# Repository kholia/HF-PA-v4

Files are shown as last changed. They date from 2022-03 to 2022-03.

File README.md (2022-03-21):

### HF-PA-v4

VU3CER's Robust `Class-D HF PA` for https://github.com/kholia/Easy-Digital-Beacons-v1
project for 40-20-17-15-10 bands.

For extra fun, use this PA with https://github.com/kholia/HF-Balcony-Antenna-System.

Jan-2022 UPDATE: https://github.com/kholia/HF-PA-v5 is up now.

This design aspires to be the standard mW-to-QRP-Gallon HF PA in the ~600 INR
(8 USD) design space. Well, it does much more than QRP now...

Design Constraints:

- PCB is to be homebrewed.

- PCB is single-sided - only one layer (side) is available for routing.

- IRF510 MOSFET needs to be on an edge to allow usage of heatsinks.

- Typical external linears (e.g. `PA150 HF Linear Amp`) need 2W minimum to
  function. So we need a minimum of 2W of RF output from our design.

- Minimal part count is strongly preferred. Low cost, and ease of availability
  are strong driving and deciding factors.

  The cost of this HF-PA-v4 system is less than one RD16HHF1 MOSFET ;)

- Reproducibility is a MUST! We focus a lot on this aspect by documenting each,
  and every detail possible.

- Repairability in the field is a MUST!

  Dhiru's finding: Repairing homebrewed PCBs is so much easier, and fun than
  reworking commercial `lead-free` PTH PCBs.

- No moving mechanical parts are allowed in the design - this rules out usage
  of (failure-prone) active cooling options like fans.

- We do NOT like the robustness of QCX, QDX, uSDX PAs. Removing heat from TO-92
  devices in a reliable way is not a trivial problem.

Note 0: All screenshots are clickable and zoomable.

Input: Few milliwatts is fine. Note: Si5351's output is around 8-10mW.

Output: With `v4.1` design, we are able to get 12W+ (total power) on the 15m
band with 30% efficiency! With a 5-pole LPF attached, we get ~10W RF output on
the 15m band. Efficiencies and output power levels are much higher on lower
bands! E.g. Power output @ 14 MHz is 14W+ with 51% efficiency - with LPF
attached!

Old results (kept for reference purposes):
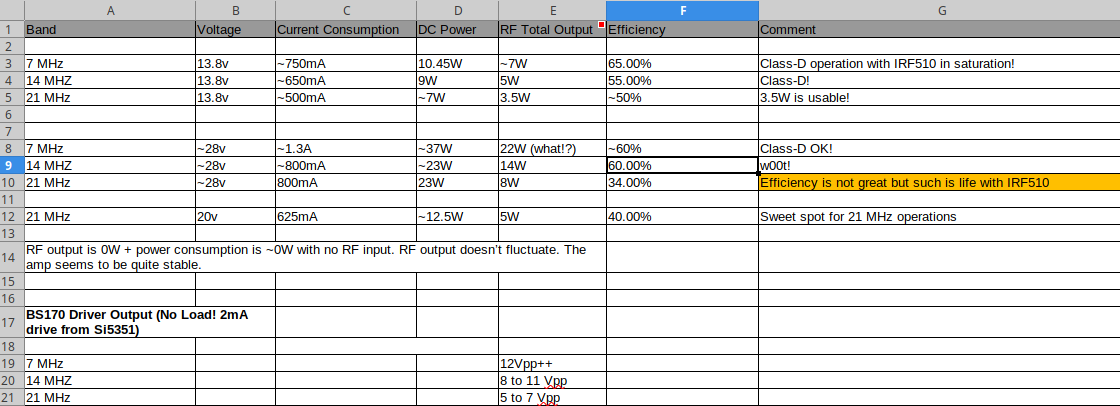
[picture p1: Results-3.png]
Results


Sample output for (14 MHz, 20v, ~725mA IN, 15W DC IN, 5.2W RF OUTPUT, With LPF
attached):

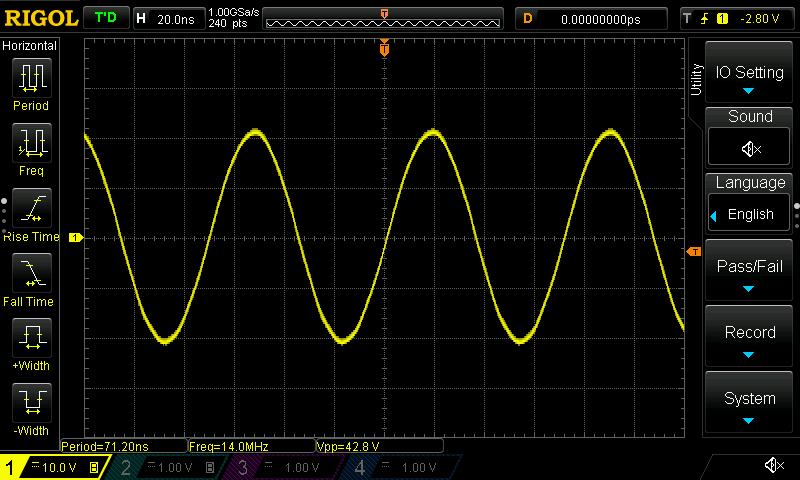
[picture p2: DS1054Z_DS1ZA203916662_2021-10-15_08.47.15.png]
Scope Shot


Note 1: The output power is software controllable (via `PWM grounding`) for
flexibility.

Note 2: The idea behind making these (and my other) design notes publicly
available is to deliver REPRODUCIBLE, flexible, home-brewable, standardized,
reasonable, and cost-effective solutions for some common problems. I include
many references, simulations, and notes in my projects to enable you to do your
own (better) designs - do share them ;)

Robustness Notes:

- Ensure that the IRF510 is fastened securely to the heat sink.

  Use lock washers, and thermal epoxy adhesive to ensure good mechanical
  contact.

- We recommend operating at 24v instead of >= 29v.

**Final recommendations from 05-November-2021 (for v4.3)**:

- Using 7805 is recommended instead of 7809 / 7912. Less is more ;)

- Enable `SI5351_DRIVE_8MA` option in code.

- Output results @ 24v:

  - 28.075 MHz (10m): 4W RF OUT (~14.5W DC IN)

  - 21.075 MHz (15m): 5W RF OUT (~13W DC IN)

  - 14.075 MHz (20m): 7W RF OUT (~13W DC IN)

For more power, use 7809 instead of 7805, and remember to take (much) more
care!

Please see the older https://github.com/kholia/HF-PA-v2 project for the
power-supply (over-current protected), and LPF designs.

Schematic:

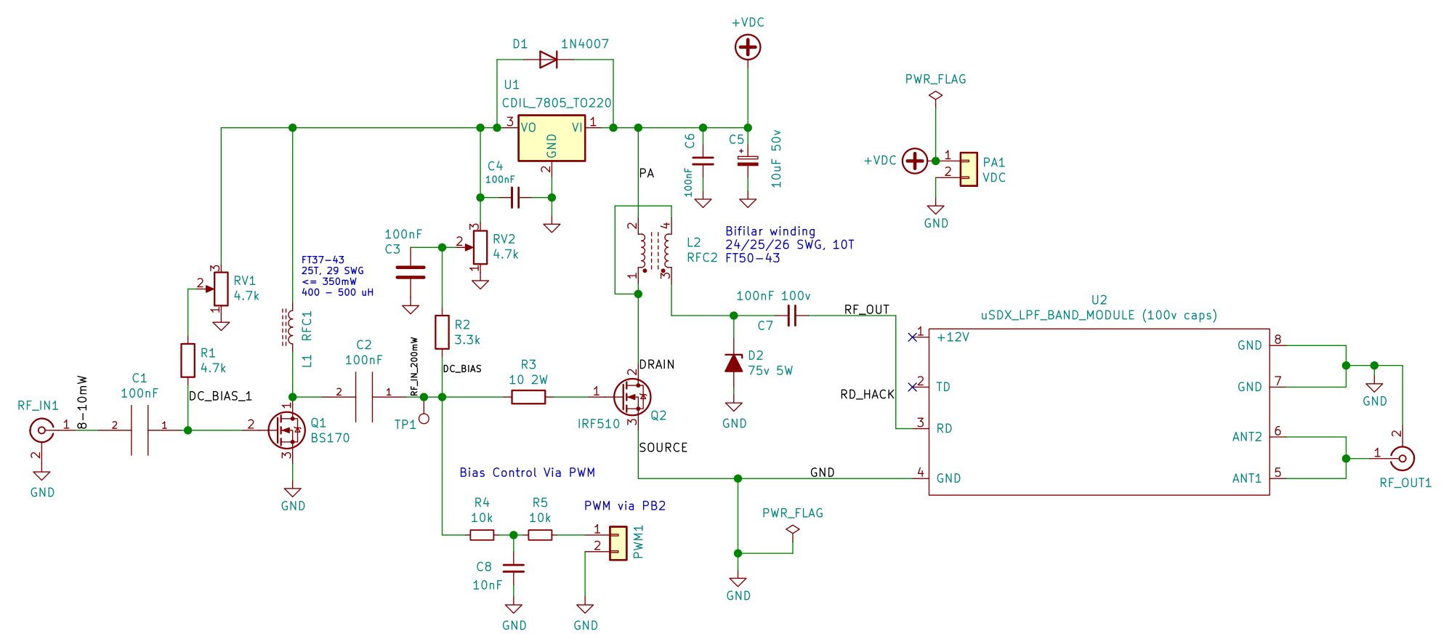
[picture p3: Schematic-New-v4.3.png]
Schematic


PCB rendering (v4.1):

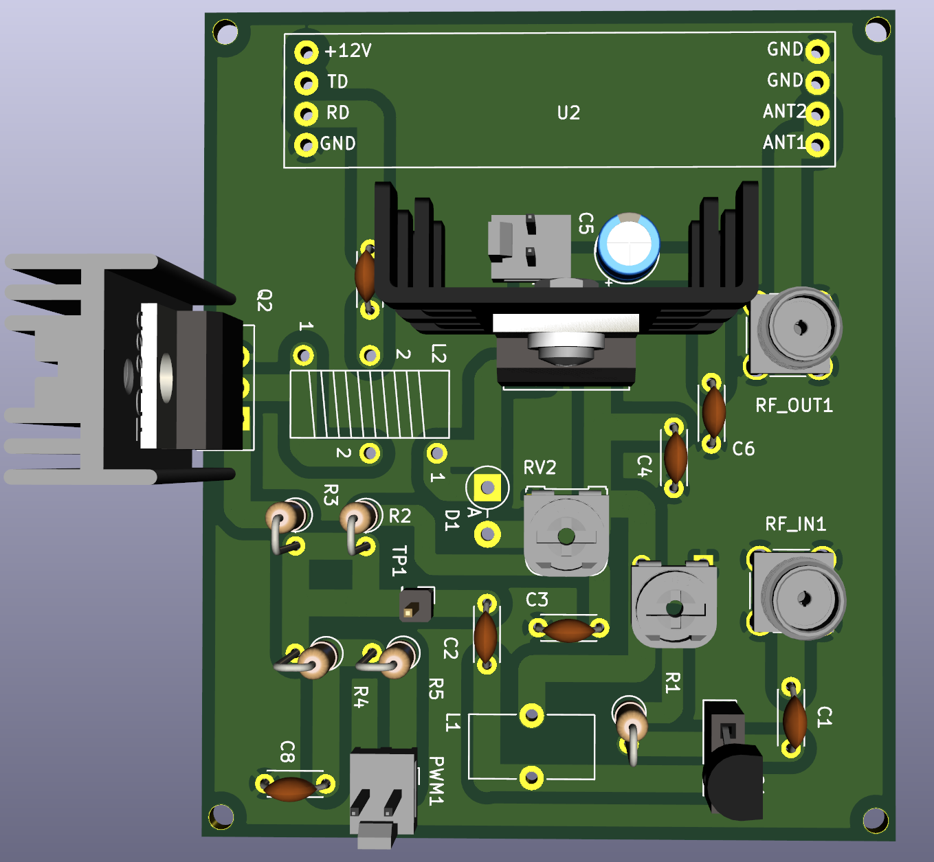
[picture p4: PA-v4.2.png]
HF-PA-v4


Note 3: The HF PA is connected to a 20m dipole over 55 meters of HLF-200 coax.

Note 4: The PCB is done using KiCad - a free, and open EDA software.

Note 5: This PA can be homebrewed from scratch in around 4 to 6 hours (one
afternoon, and an evening).

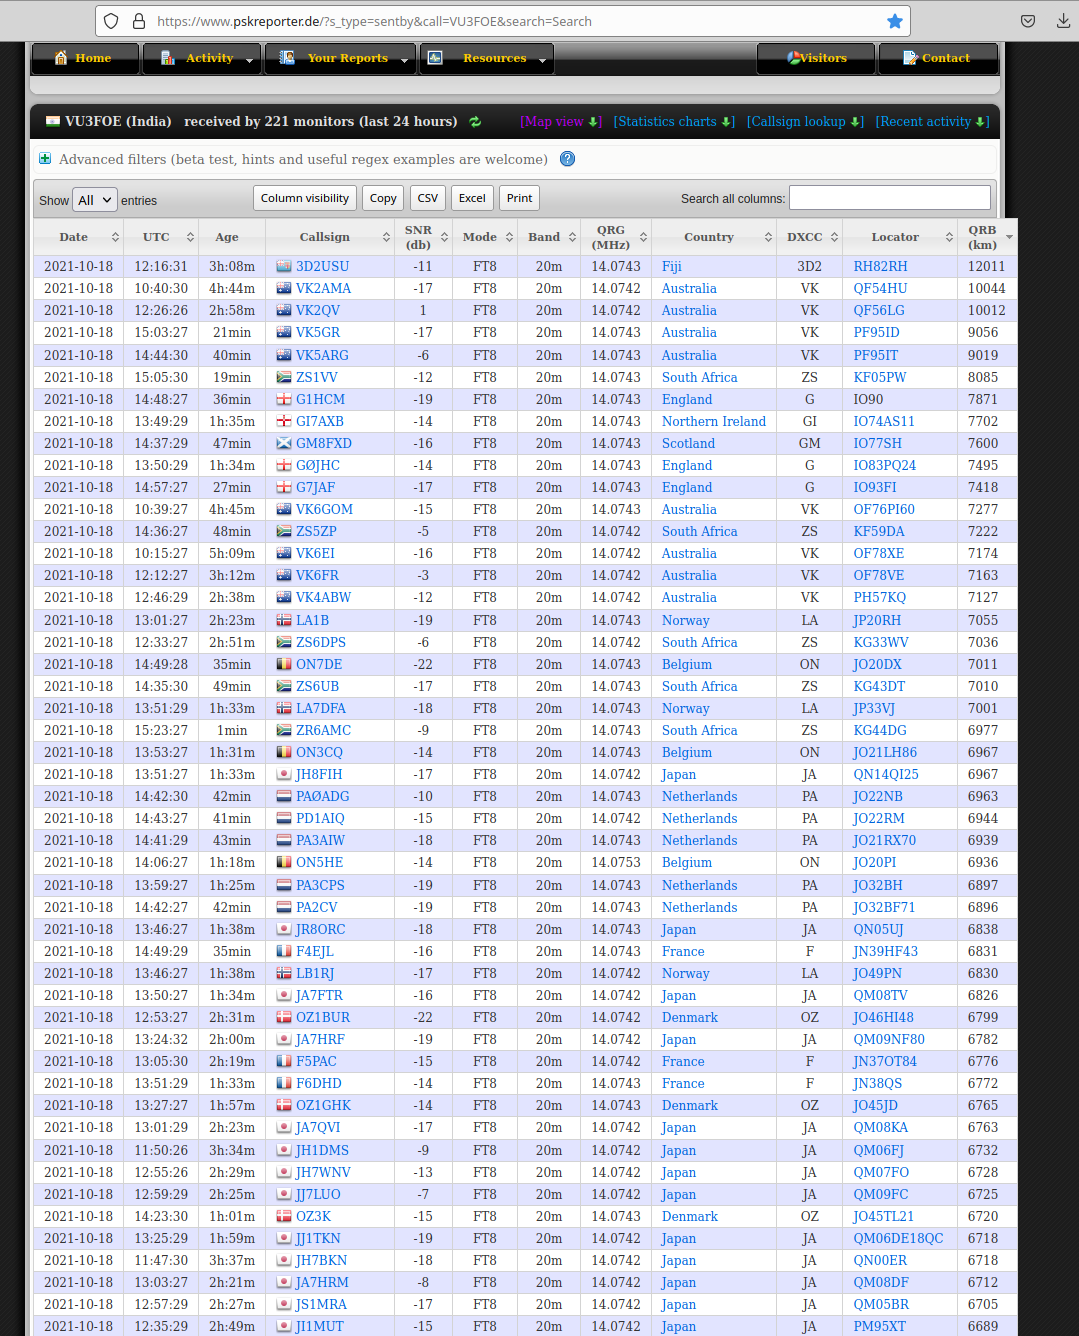
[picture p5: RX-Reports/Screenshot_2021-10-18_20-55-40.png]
RX Report 1

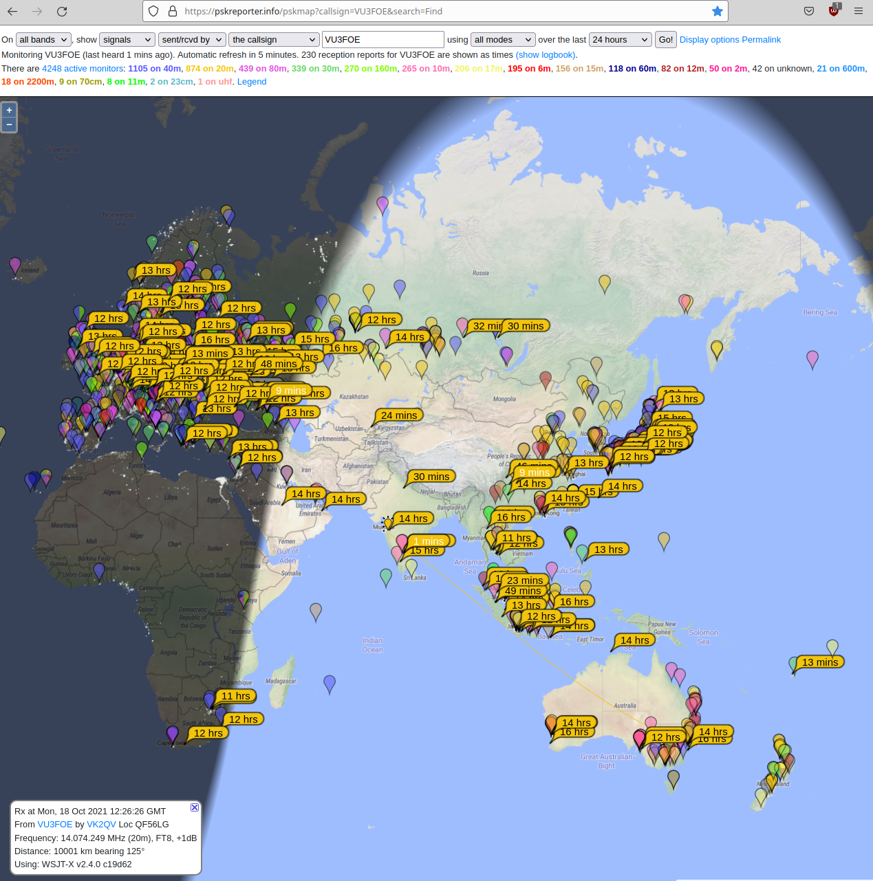
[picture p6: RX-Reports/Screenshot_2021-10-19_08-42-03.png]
RX Report 2

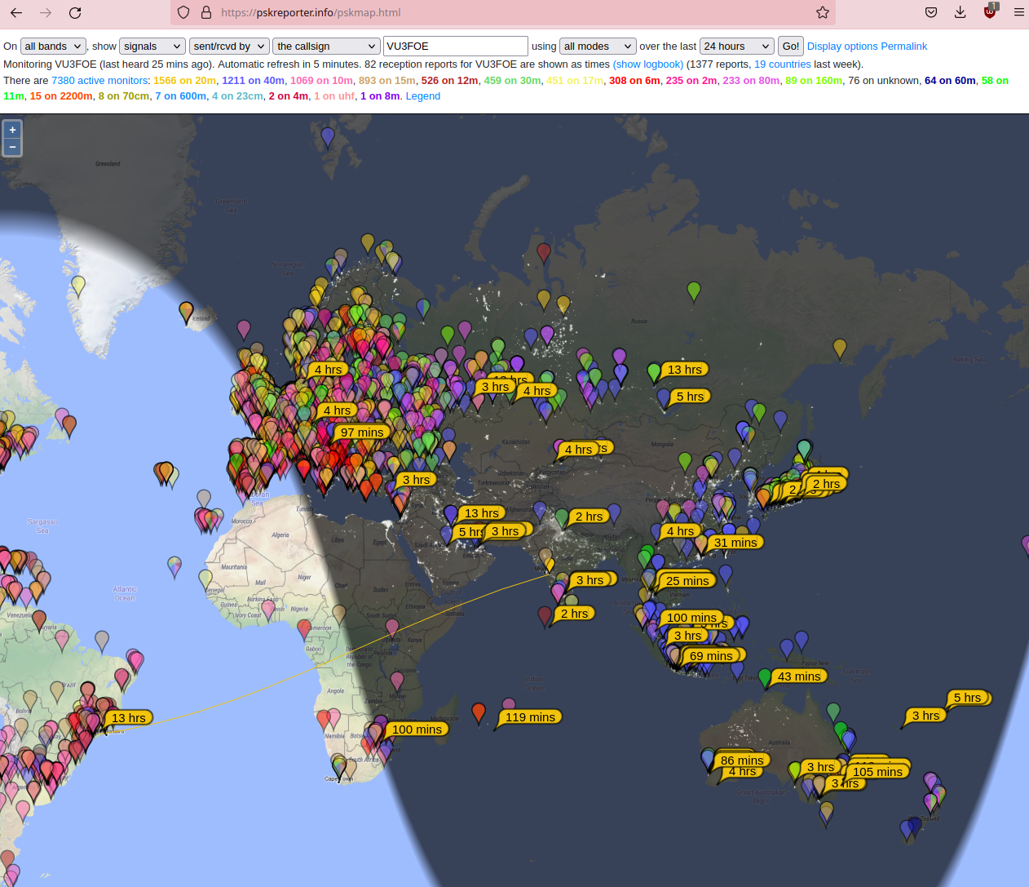
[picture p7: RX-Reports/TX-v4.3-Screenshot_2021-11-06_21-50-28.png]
RX Report 3


#### Notes

[From QRP Labs] Si5351A outputs a 3.3v square wave. The power output of Si5351A
is around 8-10mW (10 dBm). The BS170 based driver circuit amplifies this to
~200mW (23 dBm) for a gain of around 13 dB. The IRF510 finals provide a gain of
around 14dB and produce around 5W of RF power.

#### PA tuning process

- Remove the BS170 and IRF510 MOSFETS from their sockets.

- Set DC gate bias for BS170 to 0v. Now increase the bias (via trimpot) until
  the current consumption increases slightly (QRP Labs' process).

  You can also start by setting the gate bias to 2v directly ;)

- For IRF510, set gate bias to 3v. This ensures that IRF510 isn't turned ON -
  double-check this by monitoring the power consumption.

- Connect the MOSFET back, and measure RF output. Happy with the output power? -
  If yes, you are done else follow the next steps.

- Remove the MOSFET, increase the gate bias voltage in very small increments
  (0.1v types).

- Connect the MOSFET back, and measure power consumption without any RF input.
  Ensure that MOSFET remains OFF without any RF input.

- Apply RF input, and measure RF output.

- Repeat these steps as needed.

The [QRP Labs' procedure for bias adjustment](https://www.qrp-labs.com/images/pa/pa_simple_assembly_A4.pdf) and [this document](https://www.qrp-labs.com/images/ultimate3s/assembly_u3s.pdf) seem to have a better description of this process.

#### PA BOM

- 1 x IRF510 (Genuine Vishay parts are tried-and-tested) - 35 to 50 INR

  - The `SEC` (`SEC Electronics Inc`) branded IRF510(s) also work great!

  - The `SEC IRF510` can perform even better than Vishay's version. This
    particular result will vary between different product batches.

  - IRF510 with `International Rectifier` branding are most likely fake or "new
    old stock" if you are very lucky!

    Note: IR and Infineon have stopped manufacturing IRF510 MOSFETs.

  - AliExpress IRF510(s) are likely to be fake

  - The IR IRF510 gave ~3W versus 5.2W+ from SEC IRF510 versus ~5W from
    Vishay's IRF510!

    Note: The gate threshold voltage can vary even between two samples picked
    from the same manufacturer!

  - The Cgs ("gate capacitance") of a fake IRF510 is typically more than 1000pF
    on a LCR-T4 meter. This value is around ~400pF for genuine IRF510 parts on
    a LCR-T4 meter.

  - Ensure proper sourcing (trusted supply chain, etc) to get genuine parts

- BS170 MOSFET - 9 to 15 INR

- 2 x 4.7k Preset (Potentiometer) RM-065 - 12 INR

  - It is easier to get 5k (502) trimpots

- 1 x 3.3k 0.25W MFR - 2 INR

- 1 x 4.7k 0.25W MFR - 2 INR

- 1 x 10 Ohm Resistor 0.25W or 0.5W MFR - 2 INR (MOSFET gate resistor)

- [Optional] 2 x 10k Ohm - 0.25W Metal Film Resistor - 5 INR

- A very large heat sink - 50 to 175 INR - larger heatsink is better!

- 1 x 7805 (TO-220 package from CDIL) Voltage Regulator - 30 INR

  - The ST's 7805 is widely faked - let's avoid it or let's source it properly

- 1 x 1N4001 (or 1N4007) diode for 7805 protection - 2 INR

- 2 x SMA connectors (Vertical PCB mount) - 75 INR

- 1 x 10uF 50v Electrolytic Capacitor - 5 INR

- 8 x 100nF (104) 50v MLCC - 20 INR

- 1 x FT37-43 (Black Toroid, Fair-Rite 5943000201) - less than 25 INR (handles <= 350mW only)

- 1 x FT50-43 (Larger Black Toroid, Fair-Rite 5943000301) - less than 32 INR

- Misc: Relimate Connectors, Copper Clad PCB (Glass Epoxy), Various Consumables
  (~100 INR), SMA cables for testing, RF adapter (SMA Male to SO-239), M3 nuts
  and screws, TO-220 insulator kit

- Tools: LCR-T4 Meter (for measuring things), RF Power Meter

- Optional power supply: LM50-20B24 Mornsun SMPS - 24V 2.2A - 52.8W AC/DC SMPS - 700 INR

- Optional PPTC fuse

- PA Total Cost: Less than 600 INR

#### Power Supply + LPF BOM

See the following projects:

- https://github.com/kholia/HF-PA-v2
- https://github.com/kholia/HF-PA-v3
- 2 x 100 pF (50/100v)
- 1 x 180 pF (50/100v)
- 2 x T50-6 (Yellow Iron Dust code) toroids
- 25 SWG Winding Wire

Note: For LPF, use C0G 100v rated caps!

#### BOM + Equipment Sources

- https://www.semikart.com/ (IRF510, BS170, 100v NP0 LPF caps - Kemet and others)

  - 100v NP0 LPF caps from `Multicomp Pro` brand seem pretty cost-effective

  - 1N5374B 75V 5W Zener Diode (optional - for SWR protection)

- https://www.electronicscomp.com/

  - IRF510, BS170, regular caps, ST voltage regulators

  - Female berg strip (2.54mm pitch)

- https://www.electroncomponents.com/ (transistors, connectors, consumables, misc)

  - https://www.electroncomponents.com/LM7805-5V-Positive-Regulator

  - https://www.electroncomponents.com/BS170-N-channel-Switching-FET

  - https://www.electroncomponents.com/1N4001

  - https://www.electroncomponents.com/mica-insulator-to-220-set-kit

- https://www.sunrom.com/ (regular ceramic caps, SMA connectors)

- https://projectpoint.in/

  - Transistors, regular caps, voltage regulators, pots / trimmers, MFR resistors, misc

  - 2-Pin High Quality Relimate Connectors (all those 2-pin headers are actually Relimate Connectors)

  - Copper Magnetic Winding Wire - 29 SWG and 25 SWG

  - CDIL 7805

  - 3-Pin Relimate Cable Female to Female (High Quality 2500mA) - 'TO-220 socket'

  - 2-Pin Relimate Cable Female (High Quality 2500mA) - for power

  - 2-Pin Relimate Male Header

- Semikart, eBay (`gr_makis`) - Toroids

- https://www.onlinetps.com/shop/ ('IR branded' IRF510 - not recommended!)

- https://www.ktron.in/ (SMA connectors)

- [LCR-T4 LCR Meter](https://www.techtonics.in/lcr-t4-12864-lcd-graphical-transistor-tester-resistance-capacitance-esr-scr-meter)

- https://robu.in/ (voltage boost module)

- See https://github.com/kholia/HF-PA-v2 and https://github.com/kholia/HF-PA-v3 sources too

Note for international buyers: The BOM can be carefully sourced via Mouser and DigiKey.

#### O(Current consumption)

The ESP8266 usually draws a peak current of about 250mA after it wakes up and
then more or less constantly draws around 70mA before it goes back to sleep.

DS3231 -> 5mA

Si5351 -> ~50 to 100mA

PA -> Less than 1 A (rms)

Upper bound -> 1.4A maximum.

#### Tips

MOSFETs are sensitive with regards to ESD and high soldering temperatures. Use
best practices when dealing with MOSFETs and perhaps always ;)

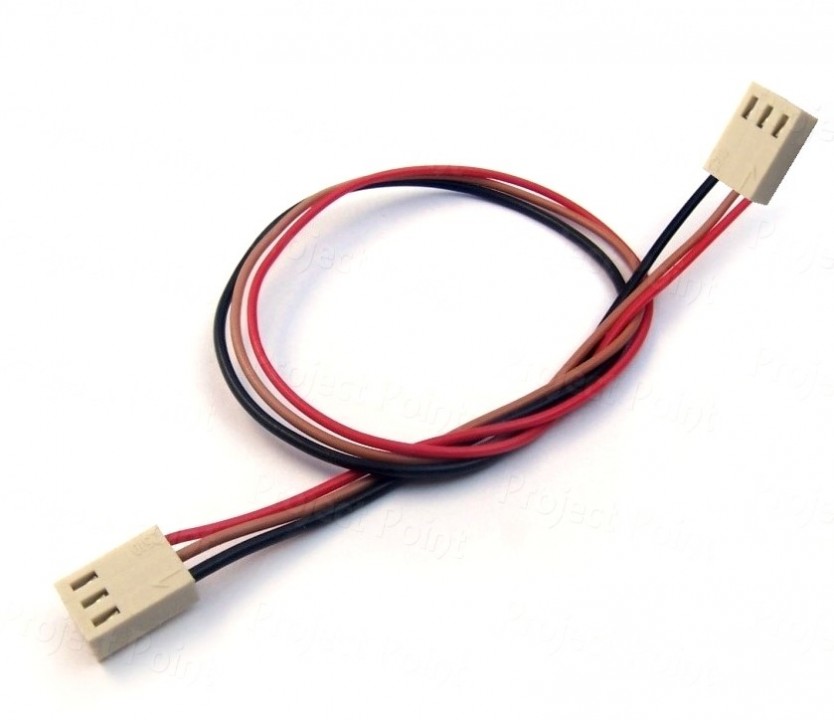
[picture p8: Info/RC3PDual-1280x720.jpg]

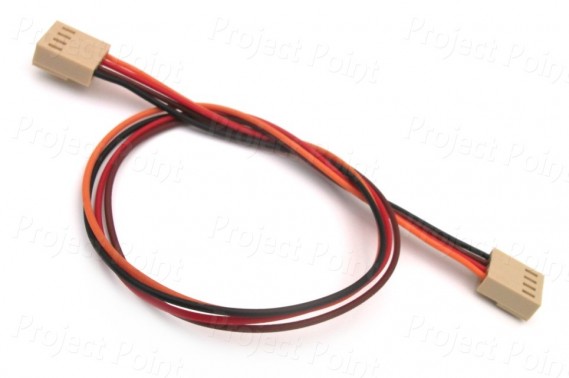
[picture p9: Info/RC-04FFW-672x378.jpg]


By using these `TO-220 Sockets`, we can easily support any MOSFET pinout. This
technique allows usage of `off-pcb` heat sinks with a lot of flexibility. It
also avoids common ESD + MOSFET problems as well. The gate bias can be easily
checked by safely removing the MOSFET from the TO-220 socket. Also, this socket
idea allows us to safely eliminate the LDO from the design.

A burnt 78(L)05 regulator can easily eat up 4-5W of power by itself. If there
is no RF output but power is being consumed then check your linear regulator.

#### Future ideas

- Use a `PPTC fuse` in the PA voltage line (oscillations can be a real problem,
  and can be nasty) - Sandeep Lohia (VU3SXT).

- Add a `Type K Thermocouple` based temperature monitoring to ensure safety.

- Alternatively, use ACS712 to monitor the current consumption to ensure
  safety.

#### References

See [References.md](./References.md).

#### Credits

This design uses ideas, and support from Hans Summers (G0UPL, QRP Labs), VU3SXT
(Sandeep Lohia), VU2ASH, Mr. Bhatnagar (VU2SPF), AC7LX, and PY2OHH.

Also see https://github.com/kholia/HF-PA-v3#credits and https://github.com/kholia/HF-PA-v2#credits.

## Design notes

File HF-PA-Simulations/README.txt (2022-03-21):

The `DS1054Z*.png` files are scopeshots of the BS170 driver stage.

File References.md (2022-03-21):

#### References

- http://shop.qrp-labs.com/pa
- http://shop.qrp-labs.com/kits/U3S
- https://github.com/kholia/HF-PA-v3/
- https://github.com/kholia/HF-PA-v2/
- https://github.com/agustinmartino/wsjt_transceiver
- https://www.qrp-labs.com/ultimate3/u3info/u3sbifilar.html
- https://www.qsl.net/py2ohh/trx/peanuts/peanuts.html
- https://www.qsl.net/py2ohh/trx/lpf100w/lpf100w.html (LPF filters)
- http://hyse.org/pdf/www.aoc.nrao.edu/~pharden/hobby/_ClassDEF1.pdf
- http://hyse.org/pdf/www.aoc.nrao.edu/~pharden/hobby/_ClassDEF2.pdf
- http://thestone.zone/radio/2020/12/13/multi-watt-amplifier.html
- http://thestone.zone/radio/2020/12/18/gate-driver-amplifier.html
- http://thestone.zone/radio/2021/01/14/capacitors.html
- http://thestone.zone/radio/2021/01/16/minor-enhancements.html
- https://www.g0kla.com/scpa/SimpleCheapPA.php
- https://www.linkedin.com/pulse/rf-pcb-design-rules-manufacturing-process-lisa-chu/
- http://thestone.zone/radio/2021/06/04/attenuator.html
- http://thestone.zone/radio/2021/06/05/power-amplifier.html
- https://on7dq.blogspot.com/2020/12/qcx-mini-measurements.html
- https://www.random-science-tools.com/electronics/dBm-Watts-volts.htm
- https://www.mitsubishielectric.com/semiconductors/php/oSearch.php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
- http://www.carnut.info/WSPR_Tx/WSPR_Tx.htm
- https://sites.google.com/view/andy-g0ftd/iron-fist-transmitter
- https://www.dj0abr.de/english/technik/dds/pa.htm
- https://www.qsl.net/py2ohh/
- https://hf5l.pl/en/transceiver-usdx-with-arduino-nano/#
- http://www.m0rzf.co.uk/PA_Old/index.html
- https://vk3hn.wordpress.com/2019/05/01/summit-prowler-6-a-pocket-sized-ssb-cw-transceiver-for-80-40-30-and-20m/
- http://am-transmitter.blogspot.com/2014/07/protect-your-mosfet-final-stage.html
- https://electronics.stackexchange.com/questions/11583/grounding-a-soldering-iron
- http://hfsignals.blogspot.com/p/25-watt-linear-for-40-and-20.html
- http://www.norcalqrp.org/nb6mminiboots.htm
- https://github.com/RoGeorge/DS1054Z_screen_capture

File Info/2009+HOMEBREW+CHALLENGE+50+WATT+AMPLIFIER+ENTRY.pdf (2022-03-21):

ARRL 2009 HOMEBREW CHALLENGE 50-WATT AMPLIFIER ENTRY: “The 89-cent Special”
Donald W. Huff, W6JL

This amplifier was designed and built by the author as an entry in the ARRL’s 2009 Homebrew Challenge contest. The requirements of the amplifier are that it be a 40 meter band 50 watt output amplifier intended for use with a QRP transmitter as driver (less than 5W), constructed at a total material cost of not over $125.00, and meet applicable FCC requirements for amateur radio products, tested in accordance with published ARRL Laboratory test procedures. Other requirements also apply. Hopefully this amplifier will be found to meet or exceed all requirements.

This builder’s priorities for this amplifier are as follows, in order of importance:
1. True “homebrew” (no pre-made PC boards, kits, etc).
2. Lowest possible cost of materials. (HB labor is recreational, and therefore FREE, so I always trade off materials for labor). Must be a “cost-effective” design.
3. More than adequate performance.
4. Practicality in construction and in use, with no frills.
5. Usable on other bands.
6. T/R switching fast enough for QSK at usual speeds.
7. “Cosmetics” always seem to be last on my list. Beauty is in the eye of the builder, and for this builder, ugly-style is beautiful!

PHYSICAL CONSTRUCTION (FANCY TERM IS MECHANICAL DESIGN):

Bare copper-clad material, and “ugly construction” methods minimize cost and provide excellent RF grounding of circuitry. This amplifier is a nearly ideal candidate for ugly construction. Only a single side of the copper clad material is used for mounting components, thus either double-sided or single-sided copper clad material (less expensive) may be used. The copper-clad material is drilled for three 4-40 mounting screws threaded into matching drilled and tapped holes in the heat sink. Also, the heat sink is drilled and tapped for two 4-40 threaded holes for the mosfet mounting screws. Last, the copper-clad is drilled with four 4-40 screw clearance holes in the corners, used for four 4-40 screws and threaded spacers to act as supports above the table top when in use. Two rectangular cutouts about 1/8 inch larger all around than the TO-220 device packages, are centered on the base material’s length and width, and cut out using a drill and a hand nibbler tool and/or a file. An inexpensive but very effective personal computer Pentium processor heat sink/fan is used. This heat sink/fan maximizes cooling effectiveness required by the relatively poor thermal conductivity of the TO-220AB package of the chosen active devices, the International Rectifier IRFZ24N power mosfet. The key to low cost is the use of these very inexpensive devices, which are intended for switch-mode power supplies and other switching applications, not RF service. As hams have historically done, I am using whatever is readily and inexpensively available that will meet my needs. A reasonably stocked junkbox can keep the out-of-pocket cost for this amplifier under $10.

CIRCUIT DETAILS (FANCY TERM IS ELECTRICAL DESIGN):

There is really no original design work here. But for any builder it is important to understand what the components do, and how they were chosen. I see all too many homebrew articles which just present a schematic and skimpy circuit description and do not explain what each part does, how its value is determined, and perhaps how critical its value may be and why.

The circuit used in this amplifier is a conventional and often-used push-pull broadband transformer-coupled architecture. No RF negative feedback is used, for simplicity and to provide high gain while still meeting the minimum IMD requirement of -28 dBc (at least 22dB below 12.5W tones). No complex mechanical assemblies are required and most components are mounted by their leads as usual in Ugly Style construction. I used inexpensive solder-down RCA type connectors for input, output, and P.T.T./Keying, and direct wire connections for a 13.8VDC supply.
Operation is class AB for linear applications (SSB, PSK, etc); or the amplifier is easily re-biased for class B for CW use if desired. A bias control potentiometer for each mosfet allows user variation of operating point to enable optimization of operation for a particular mode or for optimizing performance. Limited temperature compensation of bias point is provided by gluing pairs of 1N4148 (costing as low as 2 cents each from at least one supplier) diodes to the plastic cases of the mosfet devices and utilizing their known forward voltage vs temperature characteristic (about -2mV/deg C) to reduce forward bias as mosfet junction temperature increases. The diodes run at a constant current. This is accomplished by making simple current sources using a PNP transistor at Q1 and Q2 with associated biasing resistors. Why use a current source? Because, if driven from a voltage (ie, low resistance) source, the temperature variation of diode forward voltage will be reduced by the divider formed between the diodes’ changing forward voltage and the other resistors in the circuit. With a current source, the current through the diodes is maintained over a wide range of voltages and variation in diode forward voltage, thus preserving the variation in voltage due to the diodes’ changing temperature. (See LTSpice simulation circuit for the current sources later in this article). The absolute value of the bias voltage depends on the magnitude of the current from the current source, and the setting of the bias pot. How does the current source work? Zener diode D1 maintains a fixed voltage of about 4.8V across the base-emitter of Q1 and Q2, plus emitter resistor of Q1 and Q2 (the zener has a tolerance of +/- 5%, so its voltage can vary from 4.75 to 5.25 volts depending on the accuracy of any given diode). The current flowing in the emitter and collector circuits of Q1 and Q2 is determined by this voltage, minus 0.7 volts drop emitter to base, divided by the emitter resistance. Thus, in the prototype circuit the current is (4.8 – 0.7)/1.2K or 3.3 mA. This value is not critical, and will vary from unit to unit depending on zener tolerance and resistors R1 and R2 tolerances. Potentiometers R4 and R5 adjust gate bias on the mosfets over a range from about 2.9 to 4.5V, which for most IRFZ24N devices will cover operation from Class B (no quiescent drain current), up to class AB (up to a few hundred mA of drain current for each mosfet). The author found it unnecessary to make biasing individually adjustable for each mosfet, after trying several pairs of IRF24ZN mosfets in the circuit, but individual control is included here for accommodating those cases where the gate threshold voltage matching is not so close between the two mosfets. .
The gates of the two mosfets are heavily loaded at RF frequencies by the pairs of 20 ohm ½ watt resistors, connected from gate to RF ground via C2 and C5. These values were chosen somewhat arbitrarily (yes, they were available in the junkbox), and reduce the gain in addition to partially swamping out the high input capacitance of the mosfets. The lower the values of these resistors,the higher the required input drive power (and the lower the power gain) of the amplifier. They also act to help stabilize the input impedance, so that the driver sees approximately a 50 ohm load. Transformer T1 steps the 20 ohms of push-pull gate impedance up to about 50 ohms, thus requiring at 50/20 or 2.5:1 impedance step-up from gates to input. Recall that for any transformer the impedance ratio is equal to the turns ratio squared, ie, Z1/Z2 = (N1/N2)^2. This requires a turns ratio in this case of the square root of 2.5, which is 1.58. The inductance of the secondary or primary must be at least 4 times the working impedance of the circuit. For the secondary, this impedance is 20 ohms. So we need an inductive reactance of at least 4 times 20 or 80 ohms, at the lowest frequency we plan to use, say 1.8 MHz. 80 ohms of inductive reactance at 1.8 MHz works out to an inductance of 7.1 uH (easily determined from a reactance chart; also see calculation method below for T2’s primary). Using an Amidon FT-37-43 (readily available at low cost, but also was in my junk box), we find the AL value to be 420 mH/1000 turns. Since turns = 1000 * square root of (inductance in mH/AL), we get 4 turns. For a little margin I chose 5 turns, making the primary 1.58 x 5 or 8 turns, rounded to the nearest turn.

The output transformer T2 is determined similarly, but we need to know what drain-to-drain load resistance we need. This is easily determined from a consideration of the supply voltage and output power that the mosfets can sustain. For a push-pull Class AB or B amplifier, the drain to drain impedance can be calculated from the formula Rdd = 2*(Vsupply)^2/Pout (see Note 1, also see sidebar for derivation). In this case we calculate Rdd to be [2*(13.8)^2]/50 or 7.6 ohms. The voltage swing on the mosfet drains will be about twice the supply voltage, or about 28V. (The rated 55 V maximum drain-source voltage of the IRFZ24N’s thus provides adequate margin, as long as the load is connected to the amplifier. Some mismatch is tolerable of course, but it is good practice to assure that the amplifier is looking into a relatively low impedance at all times). Since transformer T2 has a single-turn primary, the available ratios are integer ratios only. The closest integer ratio is 1:3 which provides a 1:9 impedance step-up, (or 9:1 impedance step-down the other way, from output to input). With a 50 ohm load resistance, this works out to 50/9 or 5.6 ohms at the input, which is close enough to 7.6 ohms for our purpose. Why is a single turn chosen for T4’s primary? We need a primary inductive reactance greater than 4 times the drain-to drain impedance so as not to significantly load the circuit with the transformer’s primary inductance, at the lowest frequency of operation. This means no less than 5.6 ohms x 4 or 22 ohms of inductive reactance, at 1.8 MHz. Since XL =2*PI*F*L (or use a reactance chart), we need a primary inductance of at least 22/(2*PI*1.8MHz) or 1.9uH. Using the Amidon BN-43-3312 ferrite two-hole balun core (also available for about $2 but also available salvaged from another project in my junk box), and looking up the AL value in the Amidon data sheet, we find an AL value of 5400 mH/1000 turns. Since turns = 1000 * square root (Lmh/AL), plugging in the inductance of 1.9 uH, which is .0019 mH, gives us 0.6 turns. The closest we can get is a single turn, so that should do, even for 160M.
The method of building T4 is nothing new, using the braid from a short piece of RG-58 coax, and looping the braid through to make the single turn primary (a single turn in a binocular core passes through both holes). The braid does not have to be insulated, because the ferrite core is a non-conductor of electricity for all practical purposes. The braid is kept open and a hole is enlarged through it at the center of the output side to enable threading three turns of insulated wire through the inside of the braid, around the input holes (staying always inside the braid), and with the final turn exiting the braid through the hole. This takes longer to describe than becomes immediately apparent when seeing a sketch, which is shown below. Another way is to use the common method of two brass tubes that fit the core holes to make the primary, shorting the ends at the output side, and connecting the mosfet drains to the two tubes at the input side. Then the secondary is threaded through the brass tubes. Either way is equivalent, but the braid method requires no brass tubing to be cut and a short to be fabricated from PC stock with holes drilled to short the output end. As you can see, there is a simple rationale for everything, as it should be: Keep It Simple.
For those wondering about why there is no RF feedback, as is often used, the use of small value source resistors and shunt RF feedback was investigated. Both can make the amplifier more linear, reducing IMD further, but drive power increases and peak output power becomes insufficient to meet the 50W CW requirement, at least while limited to a 13.8 VDC supply voltage. There is just not enough “head room” to avoid peak rounding (amplifier compression) with a 13.8VDC supply. The amplifier simply saturates at a lower power level when using feedback, particularly source resistive feedback. (A higher supply voltage may enable use of feedback while still obtaining sufficient peak power output). The peak RF output limitation with a 13.8V supply is probably due to the ON-state resistance of the mosfets. At peak RF drain currents of say 10 amperes or more, the voltage drop across the Rdson resistance (rated at .07 ohms at 25 deg C) of the mosfet can become a significant portion of the 13.8V supply voltage, subtracting from it and resulting in insufficient remaining drain voltage swing to provide the desired 50W of peak output. Mosfets designed for RF power amplifier service tend to have higher ON resistances (and much lower capacitances) and they almost always require a higher supply voltage for proper operation. This is why 14V powered RF power amplifiers at near the 100W level tend to use bipolar transistors instead of mosfets.
Push-pull operation tends to cancel even harmonics if well balanced, but odd harmonics are still significant. (This is a price we pay for untuned, broad-band amplifier circuits like this). The usual 40-meter “half wave” low-pass filter is included here for further harmonic suppression; other bands will require different low-pass filter component values. These are easily determined and available components (the reactance of each L and C is chosen to be equal in to the load impedance of 50 ohms), see table below for list of components for filters on other bands. If you have a selective antenna system and/or antenna tuner, if you calculate how much harmonic suppression you have with the total radiating system, you may find that on some bands you will have sufficient harmonic filtering due to an appropriate antenna tuner/antenna combination’s selectivity, to eliminate or greatly simplify the low pass filtering of harmonics. This is an often-overlooked capability. I have a two-element yagi on 40 meters for example, which is a very high Q (narrow band) radiator, offering significant attenuation outside of the band and poor radiating (and receiving) efficiency at harmonic frequencies. Running an antenna simulation using Eznec or other programs, can aid in determining the selectivity of your antenna system. We are only interested in total transmitted harmonic suppression, so you can take the whole transmitter/tuner/antenna system selectivity into account.
Simple relay T/R switching is provided. On “make” (key-down), the small Omron relays chosen close after a less than 7 millisecond (mS) delay after key-down (“make”), and, with a 22uF capacitor across the coils to slow the current decay in the coils, open again after 20 mS of delay following key-up (“break”). This enables QSK at up to about 30 WPM with no hot switching in the amplifier if the exciter does not have RF build-up before about 7 mS from key-down, and if the RF output does not last more than 20 mS after key-up. This can usually be arranged with the exciter (especially if the exciter is also homebrew!). Use of a lower-rated coil voltage relay, operating at 13.8VDC, can speed up the “make” time in some relays. This is no problem if key-down time is limited. (Do not be afraid to “mis-use” a component in a known and intentional way; we are not building an amplifier for mass production here; we just need reliable operation for this one to work. Again, think of simple ways to solve a problem and/or use an existing junk-box part to advantage). The higher voltage (and hence, coil current) on “make” can speed up the armature movement to the closed condition. The T/R relay switching was also modeled using LTSpice, after measuring the relay resistance and inductance. It turns out the inductance is insignificant and the relay opening (“break”) time stretch is determined by the resistance and the coil drop-out current, in conjunction with the shunt capacitor value. (The capacitor value is easily determined experimentally with an oscilloscope without any coil measurements or simulating of the circuit, but I have become attached to using LTSpice and find any excuse to model something :o)). With the values shown, the maximum QSK CW speed is limited to about 30 WPM. QRQ ops will need shorter switching times. (This can also be done very inexpensively with a homebrew PIN diode T/R switch, eliminating all relays, which the author built for his QRO QSK rig, using inexpensive 5-cent 1N4007 rectifier diodes, but that is outside the scope of this article).
Operation with key-down for over 20 minutes at a time has been demonstrated at the 50W continuous output power level on CW or 2-tone output at 12.5W per tone on 40 meters, at stabilized heat sink temperatures (see thermal test results graph below). The inexpensive CPU cooler does an excellent job of dissipating the heat from the two TO-220 devices, but they must be mounted with silicon grease and/or good quality insulators. Mica is ideal. The inherently rather high (about 1.8 deg C per watt) thermal resistance from junction to case of the TO-220AB package also limits the maximum safe power dissipation even with a very good heat sink

BAND | INDUCTANCE | CONSTRUCTION | C9, C12 | C10+C11
160M | 4.2uH | 18T ON T106-2 | 1500pF | 3000 pF
80M | 2.5uH | 14T on T106-2 | 820pF | 1500pF
30M | 1.2uH | 15T on T-50-2 | 330pF | 560pF
20-17M | 0.58uH | 12T on T-50-6 | 180pF | 330pF
15-10M | 0.33Uh | 9T on T-50-6 | 100pF | 180pF
Table 1. Output low-pass filter values for other HF bands. Wire sizes are not given, as they are non-critical. It is best to use the largest wire size (or equivalent-area multifilar smaller gauge wires) for which the required number of turns will fit as a single layer on the toroidal core. The two largest cores, used on 80 and 160 meters, are overkill size-wise; they were available, naturally, in the author’s junk box so were used. T-80 cores are a better fit, and turns will more fully fill the core. As with winding any toroidal inductors, the required turns count is calculated according to the published AL values for the cores chosen, and the total turns count is how many turns pass through the central hole. The first capacitor, C9, can be adjusted (ie, “tweaked”) in value somewhat, with minimal effect on low pass performance, but it can improve the higher-order IMD products by reflecting a varying reactive load back into the primary of T2, helping to cancel a little of the higher-order IMD energy. This is why C9 is shown as 680pF (instead of the calculated 470pF) on the schematic. However the amplifier should still meet the minimum -28dBc IMD requirement even with the calculated value.

TURN-ON AND TESTING:

There is not much to do before turn-on except verify all connections and parts values; look carefully, in good light. Measure the resistance of the 13.8VDC line to ground to check for shorts, set bias potentiometers to their minimum (counterclockwise, if wired similar to the original, but check this beforehand!); the bias voltage should read less than 3V on the two gates. It is useful to be able to vary the 13.8V supply up from zero slowly, watching the current. That way any problems can be corrected with no damage to the circuit. Short the PTT line to ground to energize the relays. At 13.8VDC, with the PTT grounded, the fan and relays draw about 200mA total, so this will be the minimum current drawn before adjusting the bias pots. With 13.8V supply, adjust the bias potentiometers R4 and R5 one at a time carefully such that 13.8V current increases by about 100 mA for each potentiometer. Total idling supply current will then be around 400 mA.
The amplifier is now ready for use for linear operation. For CW-only, you can set the bias at about 2.95V or just at the point where you start to draw mosfet drain current (Class B). Connect a load reasonably close to 50 ohms, preferably a 50W or greater dummy load through a directional wattmeter to start. Connect a driver and apply drive power carefully, not to exceed 5W and preferably much less (and preferably adjustable; a simple homebrew attenuator is useful for this), observing output on whatever directional wattmeter you normally use. On 40 meters it should not require over 2W of RF power for 50W output if biased for AB1 (100mA per mosfet), or 3W for Class B (0 mA). On CW you can drive the amplifier to about 63W output with 5W of drive in Class B. Higher drive powers will increase the dissipation in the gate loading resistors, so caution should be exercised to not hold drive power above about 3 watts for extended periods of time due to heating of these resistors, but they are quite forgiving.

PERFORMANCE:

This amplifier was tested using a regulated 13.8V DC bench supply capable of up to 10 amperes, an oscilloscope, the usual DVOM, and, for documenting the IMD, a 35 year old HP141T / HP8553B spectrum analyzer. However, adjustment for optimum performance can be done without recourse to a spectrum analyzer with a little practice “reading” the two-tone RF output envelope on the oscilloscope. The amplifier is usable on all HF bands 160M through 10M, but optimum performance (and full output (50W) is reached only on the 80M through 20M bands, with IMD of -30 dBc or better. On 40 meters, IMD approaching -36 dBc was measured. Maximum output on 80 through 20 meters meets or exceeds 50 W with up to 5 W of drive. This makes this amplifier a very useful addition to any QRP-only station when more power (QRO) is required for the QSO and propagation path at hand. In normal use there should be no problems with overheating. A key-down test was made with the CPU cooler’s fan turned off, and mosfet temperatures rapidly rose to 100 deg C in less than 3 minute’s time. So keep that fan running! Detailed performance figures are illustrated in the graphs below, based on the test data taken on the prototype. Output of 50 watts or better is available from 80 through 20 meters, with reduced output on 160 meters (about 25W), 15 meters (about 40W) and 10 meters (only about 12 watts). The relatively high capacitances and consequent long switching times of these inexpensive mosfets limit the output on the highest HF bands. Even more output could be obtained on several bands by using higher supply voltages (respecting the 55 V maximum breakdown voltage of the device) and optimizing components for another band. There is much opportunity for further experimentation with this design; no doubt the output can be improved on 160 meters, for example.

Total material cost should be under $30 if all parts are purchased new (not including shipping costs and taxes), and under $10 for a reasonably-stocked junkbox containing the common components such as R’s and C’s and scrap PC board material, etc; likely available to anyone who has done any modern homebrewing. The two most important components, the mosfets, are some of the least expensive items required. This is one thing that makes homebrewing today so great! So build, and enjoy. Then, build some more!

ACKNOWLEDGEMENT:
Thanks to my old friend and fellow homebrewer Bob Friess, N6CM, for alerting me to the Pentium heat sink/coolers available at low cost online, and for persuading me to enter the contest with my amplifier. The heat sink is the heart of this amplifier in that one needs plenty of cooling capability to enable use of the inexpensive TO-220 packaged devices at these power levels, especially with nearly unlimited key-down times. And, yes, the mosfets are beryllium-oxide free, as with all plastic-cased low-cost devices. Also, if it matters, they are available lead-free if you purchase the IRFZ24NPB part number.

Respectfully submitted,
D. W. Huff, W6JL 10 February, 2010

Notes:
1. See 2010 ARRL Radio Handbook, page 17.35. Also see sidebar for derivation.

APPENDIX 1: Using other mosfets: the IRFZ34N or IRFZ34NPB

The author did some limited experimenting with a similar mosfet, the IRFZ34N. This is priced in the same range as the IRFZ24N, but is rated at 34 amps max, compared with 24 amps for the IRFZ24N. It has a lower ON resistance, but we don’t get something for nothing, so it has about twice the capacitance of the IRFZ24N. This limits it further in high frequency performance but I was curious to see how it might work on the lower three HF bands, 40 through 160 meters. It does indeed appear to work somewhat better on these bands The data below shows a capability of at least 50W output on 40, 80 and 160 meters, with low drive power of 1W or less (about 0.5W ON 160m gives 50W of output when biased at 100 mA per device). This is a gain of 100 , or 20 dB, not bad for a device costing less than one dollar each. The IMD also met or exceeded the required -28 dBc on all these bands, at 12.5 watts per tone. So here is one way to improve performance on the lower HF bands.

MEASUREMENT RESULTS: PHOTOS/GRAPHS

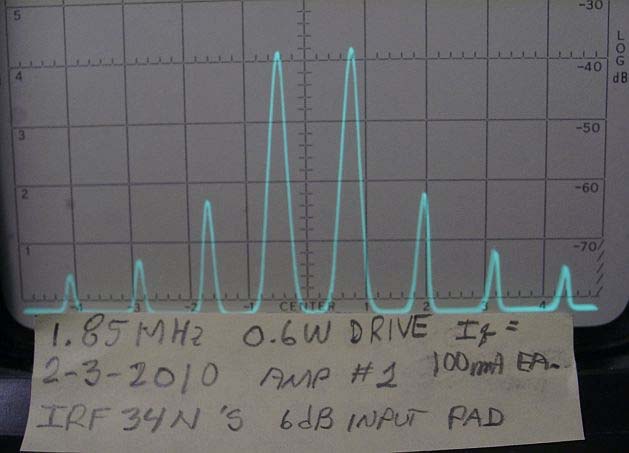
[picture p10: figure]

160M: About -31 dBc IMD at 12.5W per tone with less than 1W of drive.

160M: 50W CW output with less than 1W of drive.

160M: About -31 dBc IMD at 12.5W per tone.

80M: About 63W CW output with less than 1W drive.

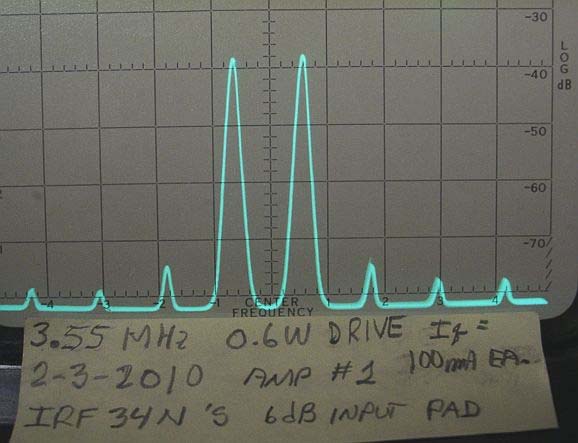
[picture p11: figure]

80M: Impressive IMD of -42 dBc with less than 1W drive. This approaches the IMD of the test two-tone source. IMD varies with temperature and biasing, especially when this clean. With circuit values unchanged from the IRFZ34N design, 80M seems to be the new “sweet spot” for low IMD when using the IRFZ34N. (The reference to a 6 dB input pad refers to a pi-attenuator made of three 2W resistors, to further reduce the output of the K3 2-tone source, which has a lower limit of resolution of a few tenths of a watt, so that a higher power setting could be used on the K3).

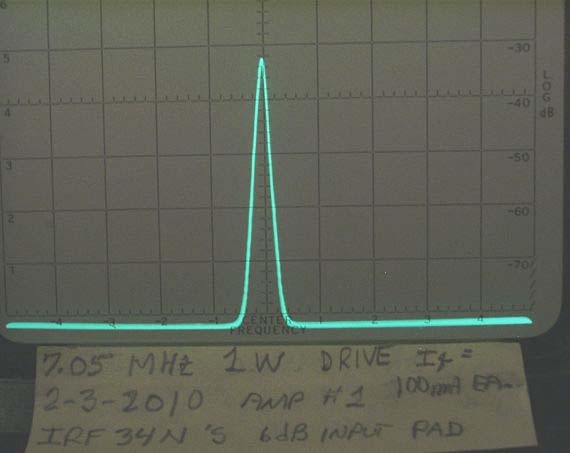
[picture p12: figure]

40M: 50W CW with about 1W of drive.

40M: IMD about -30 dBc, not as good as the IRFZ24N, but will be somewhat better with higher quiescent current. .

ADDENDUM:

The Homebrewing Experience

This project provides the amateur radio builder with an opportunity to experiment with a useful RF amplifier using very inexpensive modern devices. Building RF circuits on bare copper-clad is a joy. Progress is rapid, and soldering is easy with almost nothing required except the components themselves, soldered together in free-space style. A little forethought in layout will usually result in a circuit which “flows” naturally when reading the schematic and working on the actual circuit. It is my preferred method of constructing even QRO transmitters, and complete receivers.
This amplifier, with appropriate variation of bias point, supply voltage, and incorporating such features as RF negative feedback, one can achieve improved IMD performance and/or higher RF output, possibly even 100W, at a very low cost. It is also conceivable that four parallel devices could be used, at least at the lower end of the HF spectrum, for additional power output. Alternatively, two or more amplifiers can be combined with transformer combiners for even greater power output. There are a large number of possibilities waiting to be explored with such a basic circuit as a starting point. With devices costing under $1 each, experimentation need not be prohibitively expensive when sudden failures in devices occur. RF-rated devices rated at comparable power level cost 20 to 50 times as much per device as the IRFZ24N devices used in this amplifier, which are currently available online for $0.89 each, in single quantities (www.jameco.com.)

Expensive or elaborate test equipment is not required for this kind of project, even though the author has available a 35+ year old surplus HP spectrum analyzer. Assuming an adequately clean RF two-tone source as driver is available, even just an oscilloscope display can get you in the ballpark for IMD. (An Elecraft K3 transceiver became available for use in testing. Its design conveniently includes a clean built-in 2-tone RF generator with variable output power (down to 0.1W) on all HF bands. Before the K3 became available, a homebrew single mosfet Class A driver amplifier and simple homebrew hybrid combiner circuit was used, driven by two low level RF sources separated by a few KHz in frequency. This was adequate for IMD testing). An oscilloscope allowing observation of the two-tone RF output voltage envelope will enable a builder to get IMD performance at least equal to -28 dBc or better, just by carefully observing envelope waveform zero crossing and crest wave shapes. The author found this to be the case, and used his HP141T spectrum analyzer only for making more accurate measurements for documentation purposes. For CW ops like myself, even less equipment is needed, since a high degree of linearity is not a requirement. Incidentally, older analog test equipment, now available at low prices online, is more than adequate for ham radio homebrew projects such as this. Use of an inexpensive digital camera allows easy documentation of test results and waveforms. This author used his 10 year old Casio digital camera, hand held, for all screen shots in this project.

Homebrewing has never been easier, or less expensive, than it is today, for building excellent rigs! The author has operated all-homebrew equipment at QRO power levels for many years (decades), frequently updating as new design ideas, (plus free software circuit simulation tools), and devices become available. Parts are readily available and at low cost online from many sources today. See internet part sources list below, current as of this writing, at the end of this article. Excellent homebrew designs are also available by searching the internet. Many new and creative designs are coming from ham homebrewers in Europe also. So there is a lot to see, learn, (and copy!) if desired. All it takes is the interest and motivation to do so.
Full-featured free software simulation tools using PSPice are now available. One I recommend is Linear Technologies’ LTSpiceIV, available for download from their website at: http://www.linear.com/designtools/software/#Spice. This program with built in schematic capture and parts libraries allows almost any builder simulate linear and nonlinear circuits and measure their performance, before you build them. And you can add models of other parts not already in the provided library, as well as custom components. This is a really fun program to use, and can be used as a learning tool to gain much insight into how circuits of all kinds work, without lifting a soldering iron.

We are living now in a Golden Time for those of us interested in homebrewing. The author’s 54 years of homebrewing experience supports this conclusion. This is just the opposite from what many hams I talk with on the air every day seem to believe. Many are convinced that parts are difficult to obtain and are more costly, but those who have shared this opinion with me have never actually tried obtaining modern parts online from the many sources available today. The mentality of many hams I talk with on the air who claim to have once been homebrewers but say they “can’t homebrew any more” seems to be that of 30+ years ago, when electronic parts were purchased at local retail stores, which are now long gone. That era has (fortunately, in my view) long passed, with something much better taking its place with the much better situation we have now! So, what other excuses do YOU have for not enjoying homebrewing, if you are really interested?

APPENDIX:

SUPPORTING DOCUMENTATION

Example of reasonable IMD | RF envelope of IMD plot at left. Some peak rounding.

More IMD, higher order. | RF envelope of IMD plot at left. Distortion is obvious.

Test Bench showing Amp under test, attenuators, and spectrum analyzer. I found the power attenuators at bargain prices at the 2009 Dayton Hamvention flea market.

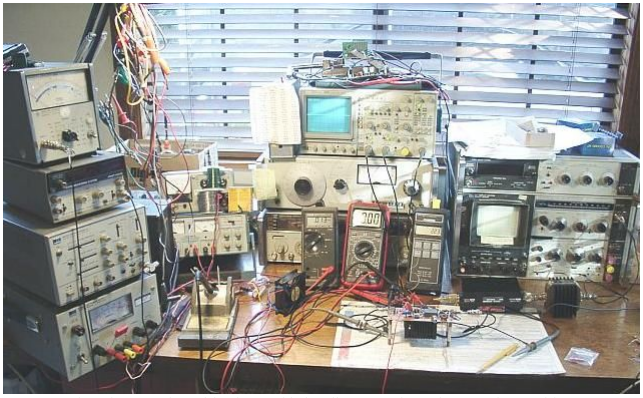
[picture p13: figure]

My “Homebrewing Bench”, wide view. This is adjacent to the main operating position. (I use a homebrew wireless paddle and wireless cans while ragchewing and working on the bench. That way, I can get a lot done while ragchewing). How much of this equipment was used for this project? Very little: power supply at lower left, scope at top center, one or more DVOMs, temperature meter, and, for IMD documentation, the older HP spectrum analyzer at lower right.

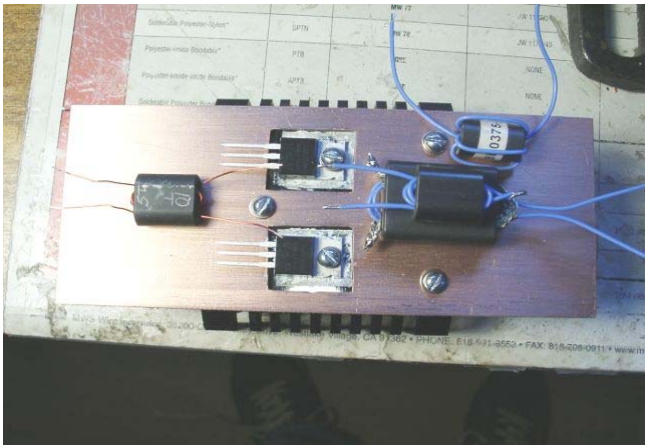
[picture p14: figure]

Beginning of amplifier assembly on bare copper-clad. Later the input binocular and DC
feed binocular and bead chokes were found unnecessary and eliminated. Keep It Simple applies here.

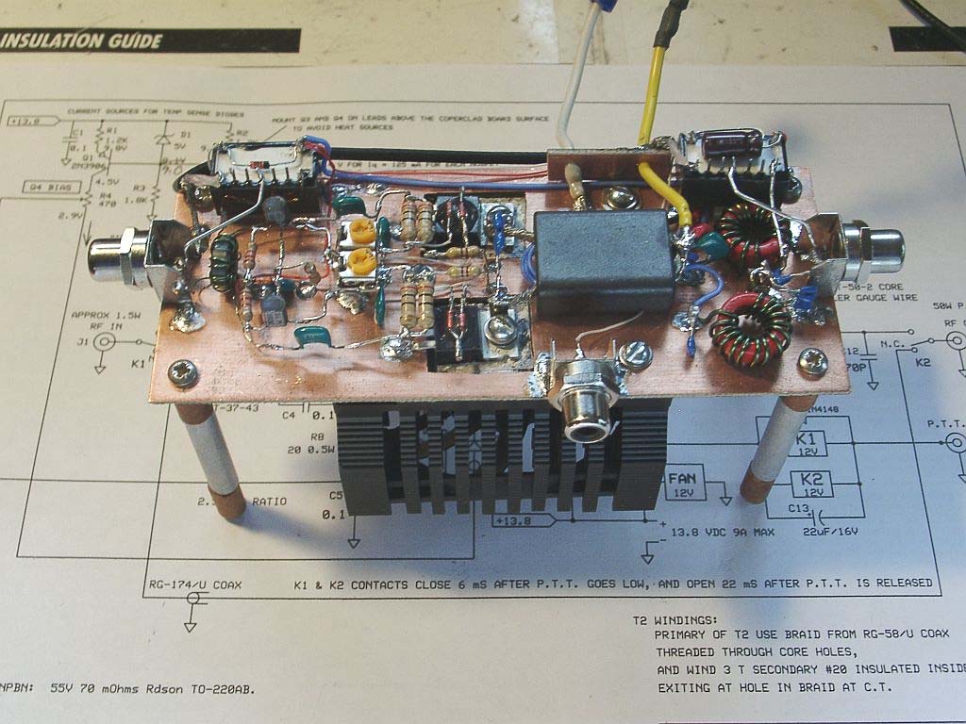
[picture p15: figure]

Overall view of bottom side of completed amplifier. Copper-clad is a beautiful material for building circuits, and is easy to work with.

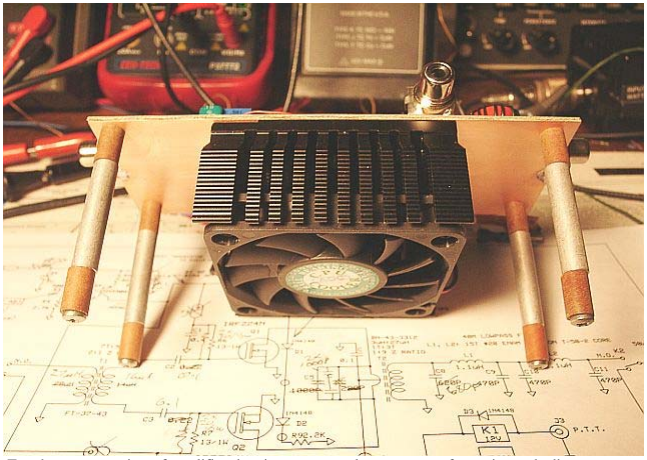
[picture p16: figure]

Top three quarter view of amplifier showing temporary longer spacers for testing and adjustment access to bottom side while allowing sufficient clearance for the fan to operate.

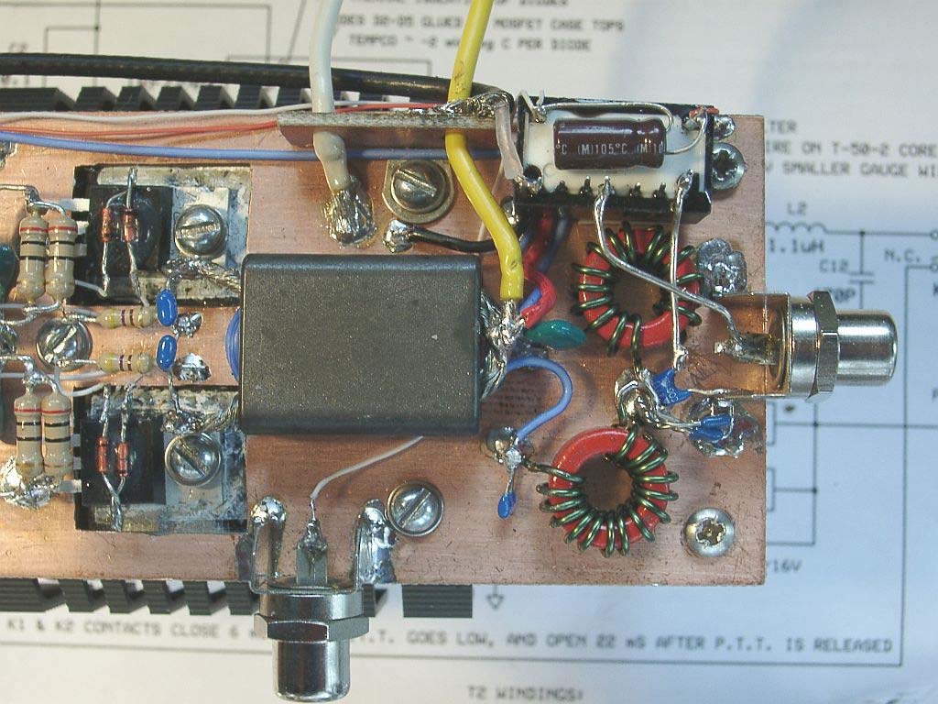
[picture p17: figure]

Close view of mosfets and output circuitry. Note 1N4148 diodes epoxied to mosfet case tops. These serve as temperature sensors for bias compensation. Wire-wrap wire serves as a minimal thermal-conductance electrical path for connections to diodes.

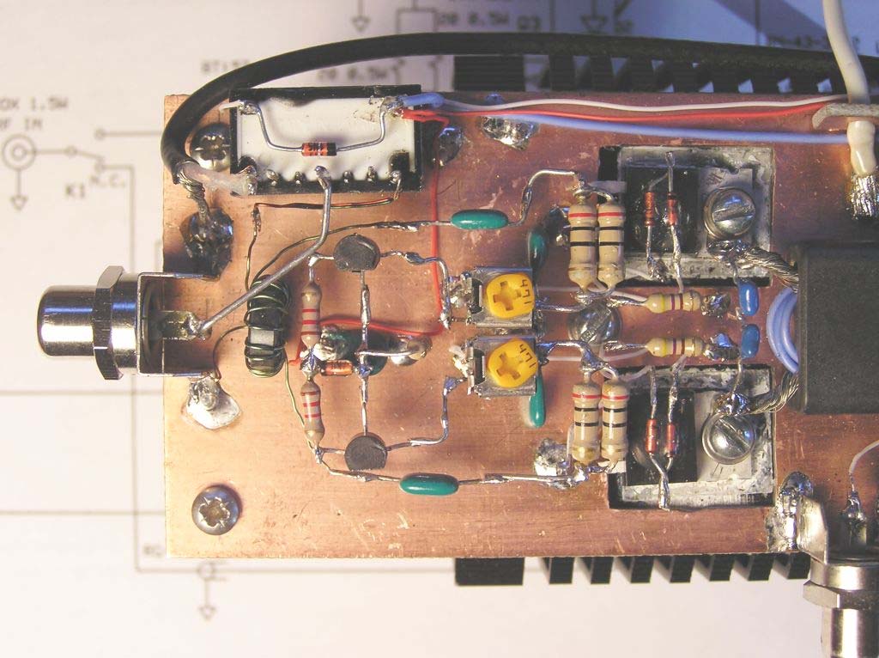
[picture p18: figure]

Input circuit of amplifier showing input coupling transformer and temperature compensated bias adjustment circuit.

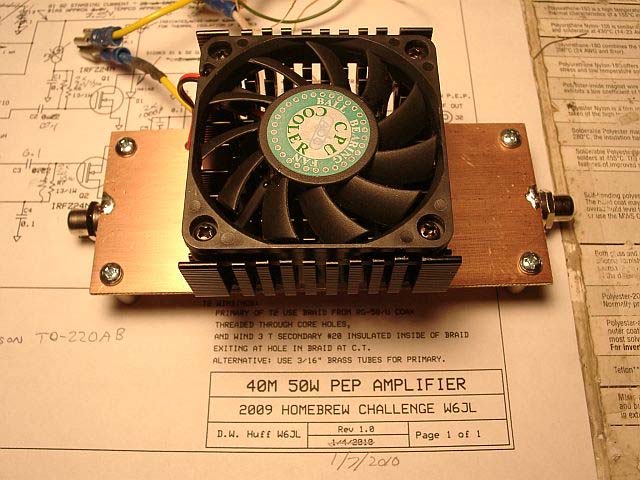
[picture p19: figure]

Top view, nearly completed amplifier mounted upright on its spacers, showing Pentium cooler fan/heat sink. Input/output and PTT utilize inexpensive solder-down RCA jacks. No labeling is shown; if you are the builder/user then no need to label anything; you know what each connection is for. Fancy labels are for “show & tell”, mainly.

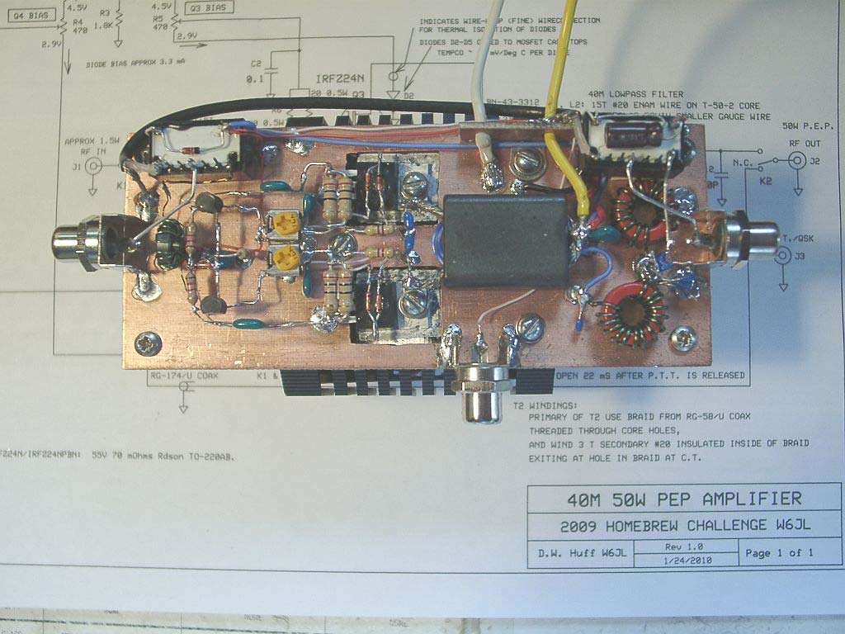
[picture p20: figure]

Amplifier bottom view.

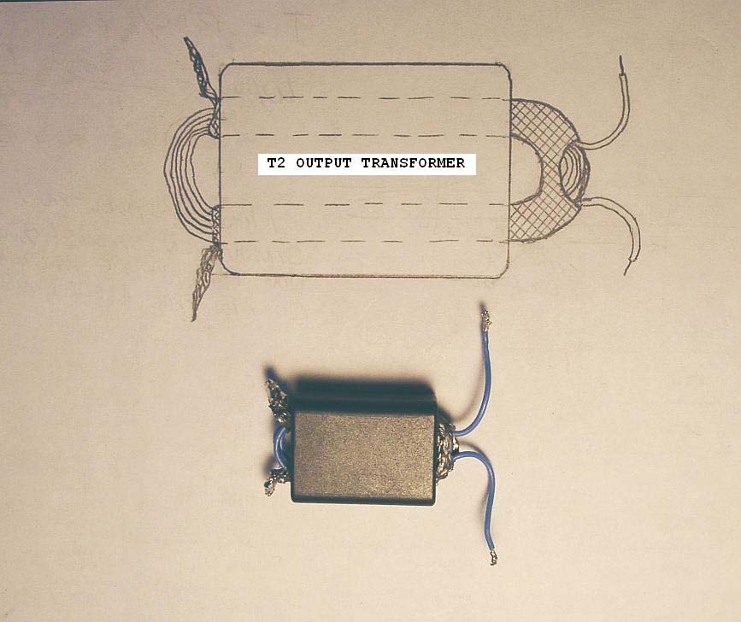
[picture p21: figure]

Output transformer construction details. Three turns of insulated wire make up the secondary, wound inside a section of RG-58/U or similar coaxial cable shield, which makes up the U-shaped single primary turn. The core is an Amidon BN-43-3312 ferrite binocular core. An equivalent construction is a stack of toroidal beads on each leg of the primary, at least equal in cross-sectional core area and total core volume as the BN-43-3312. Note that the two legs of the primary and the secondary are not coupled magnetically with each other; electrically the binocular cored transformer is equivalent to two transformers in series. This is why using stacked toroidal beads (or one equivalent larger cylindrical bead) for each half works the same as a binocular core.

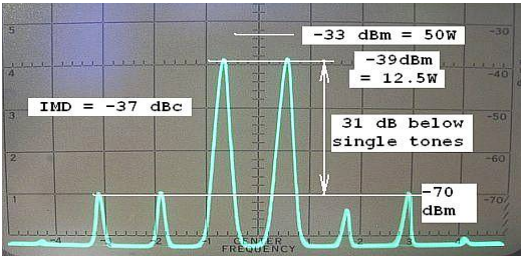
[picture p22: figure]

Example spectrum analyzer display of IMD on 7050 KHz, two-tone output at 12.5W per tone. (Quiescent bias is set at 250 mA drain current total, or 125 mA per device). Approximately -37 dBc IMD is shown (highest of the IMD products is about 31 dB below each of the two tones, which in turn are 6 dB below maximum output, adding up to 37 dB below carrier level, or dBc). To obtain actual power output in dBm from the traces, we just add 80 dB (sum of input attenuators used in front of the spectrum analyzer) to the levels shown. Thus, -39 dBm (top of the two tones shown), plus 80 dB gives +41 dBm, or 12.5 watts, per tone, created by the combining of equal level 7.000 KHz and 7.001 KHz input drive signals. The total power output of just the two tones is thus 25W, or 3 dB below 50W. In this particular case, the higher-order IMD products are about equal in level to the first-order ones. Which IMD products dominate depends on the nature of the distortion of the two-tone RF envelope shape.

IMD improves somewhat with increasing quiescent drain current, as expected.
This reduces crossover distortion in the RF envelope waveform and also increases gain.

Up to 63W CW output with 5W drive, class B.

IMD PERFORMANCE VS FREQ BAND AT 12.5W PER TONE OUTPUT QUIESCENT CURRENT 250 Ma ( total of both mosfets)

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
1.85 | 3.60 | 7.05 | 14.05 | 21.05 | 28.05
TEST FREQUENCY

INTERMODULATION DISTORTION, dBc

9 JAN 2010 W6JL

TONE SEPARATION 1 KHz

40 meter harmonic output at 50W. Highest is the second harmonic at 58 dB below 50W. Display shows fundamental output at 7.05 MHz, and has been adjusted to be at a level of -10 dBm (second spike from left). The 3rd spike from left is the second harmonic, at 14.1 MHz, which is 58 dB below the fundamental output. The next spike, which is the third harmonic, is greater than 70 dB down. The spike at far left is the “zero frequency” reference of the spectrum analyzer.

Best obtainable IMD on 1.85 MHz without modifying parts values is only -26 dBc, and this occurs at a low quiescent current of 50 mA.

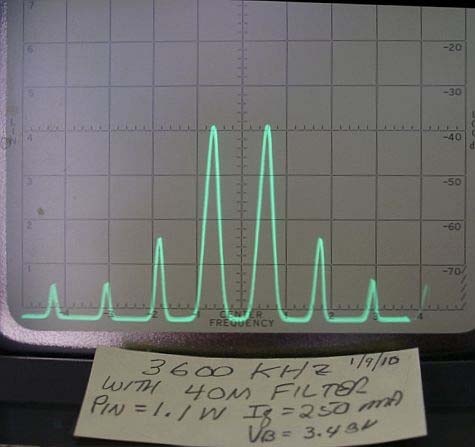
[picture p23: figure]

3600 KHz, IMD -31 dBc at 12.5W per tone

7050 KHz IMD -37dBc. Iq = 250 mA total for both devices.

10.125 MHz IMD -32 dBc at 12.5W per tone.

14.050 MHz IMD, no output filter, = -32 dBc at 12.5W per tone

21.050 MHz IMD, no output filter = -30dBc at 12.5W per tone

IMD at max two-tone output available on 28.05 MHz, at 5W input. This is equivalent to only about 32 W PEP, but IMD is good at -35 dBc.

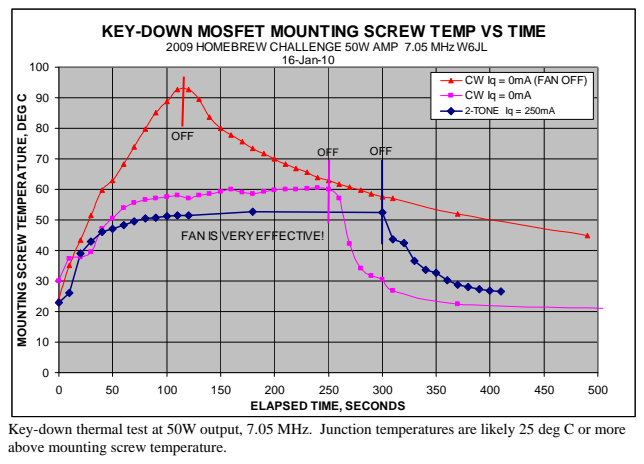
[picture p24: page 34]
16-Jan-10

KEY-DOWN MOSFET MOUNTING SCREW TEMP VS TIME

2009 HOMEBREW CHALLENGE 50W AMP 7.05 MHz W6JL

CW Iq = 0mA (FAN OFF) CW Iq = 0mA

MOUNTING SCREW TEMPERATURE, DEG C

2-TONE Iq = 250mA

OFF | OFF | OFF

FAN IS VERY EFFECTIVE!

ELAPSED TIME, SECONDS

Key-down thermal test at 50W output, 7.05 MHz. Junction temperatures are likely 25 deg C or more
above mounting screw temperature.

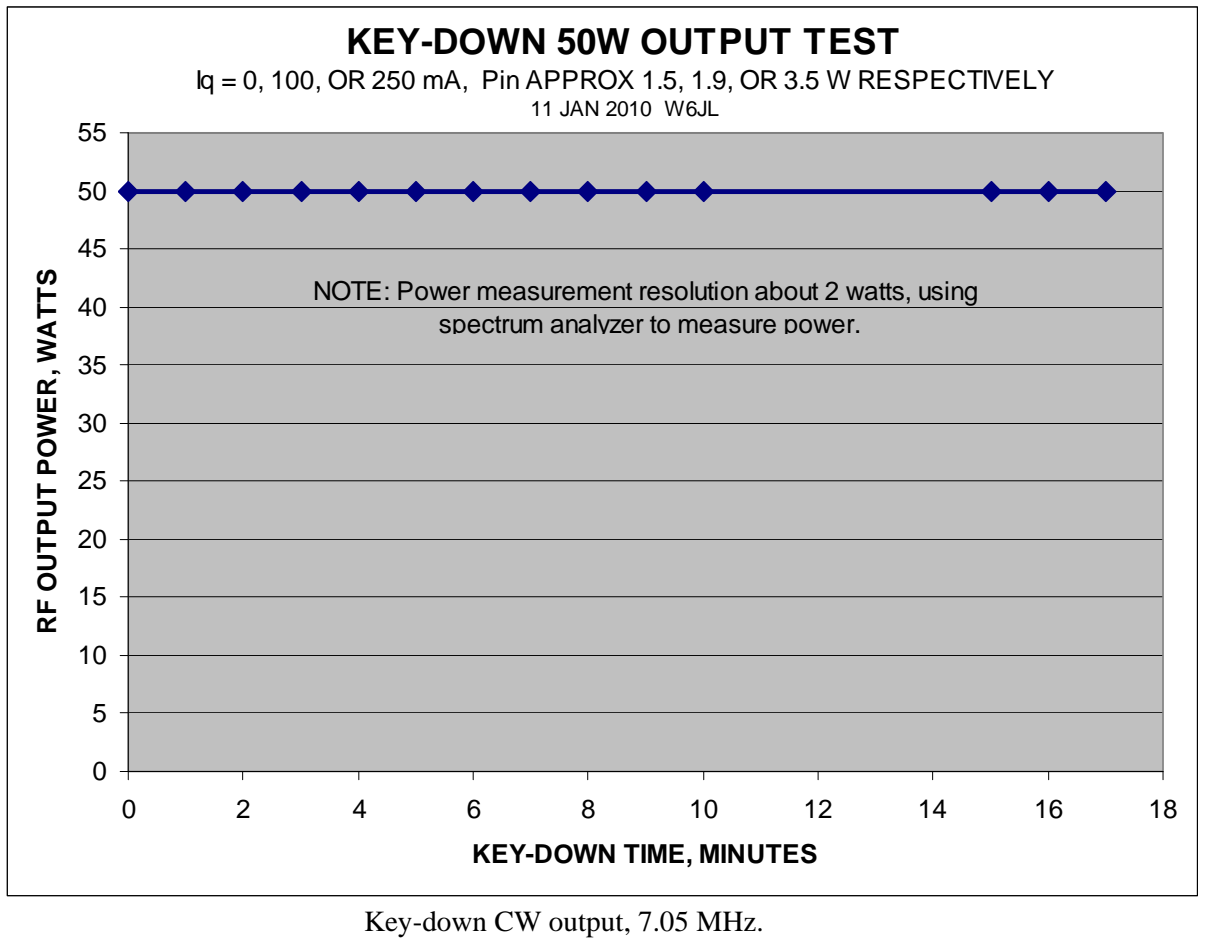
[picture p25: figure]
KEY-DOWN 50W OUTPUT TEST; 11 JAN 2010 W6JL; KEY-DOWN TIME, MINUTES; RF OUTPUT POWER, WATTS; spectrum analyzer to measure power.; Key-down CW output, 7.05 MHz.

Iq = 0, 100, OR 250 mA, Pin APPROX 1.5, 1.9, OR 3.5 W RESPECTIVELY

NOTE: Power measurement resolution about 2 watts, using

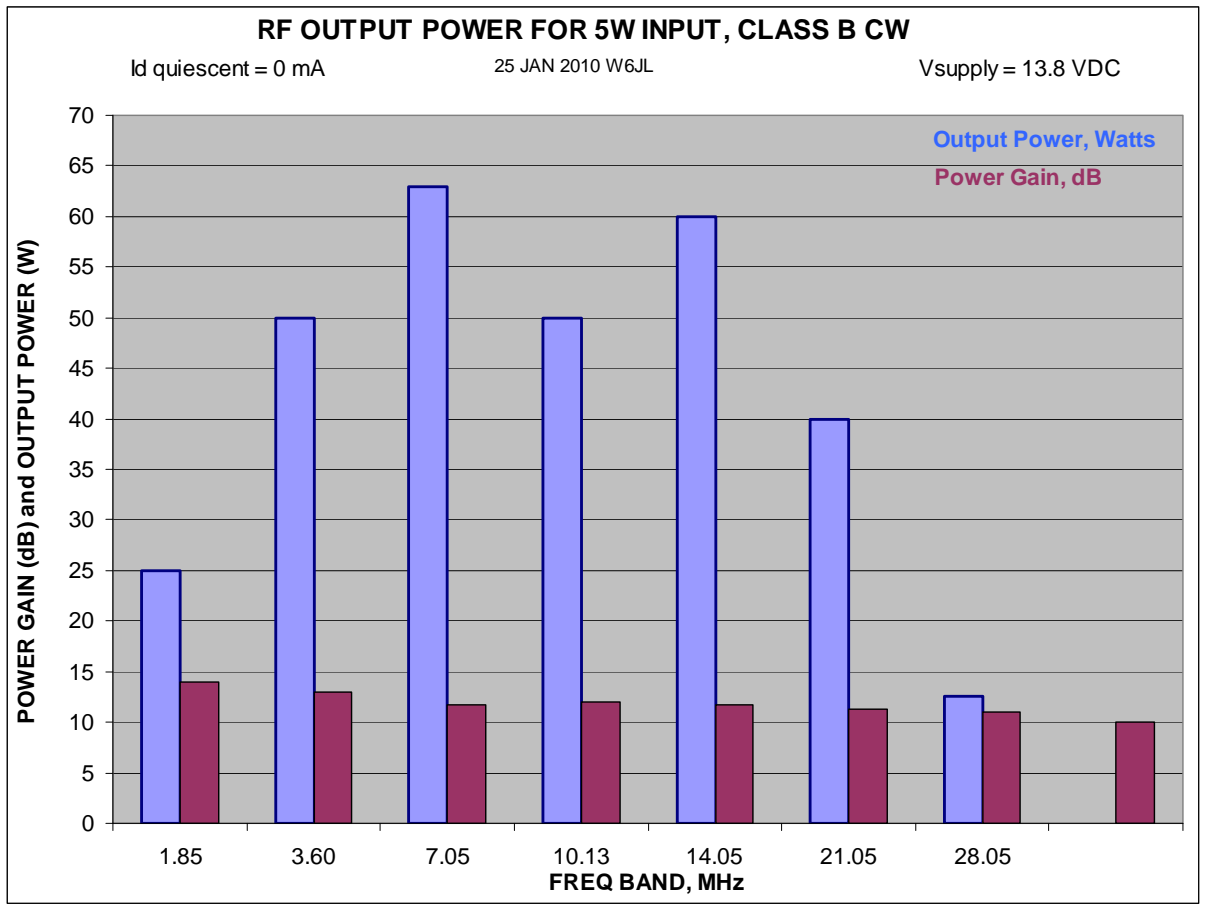
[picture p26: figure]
FREQ BAND, MHz; POWER GAIN (dB) and OUTPUT POWER (W); Power Gain, dB; 25 JAN 2010 W6JL; Vsupply = 13.8 VDC; Output Power, Watts; Id quiescent = 0 mA

RF OUTPUT POWER FOR 5W INPUT, CLASS B CW

EFFICIENCY VS KEY-DOWN TIME AT 50W OUTPUT

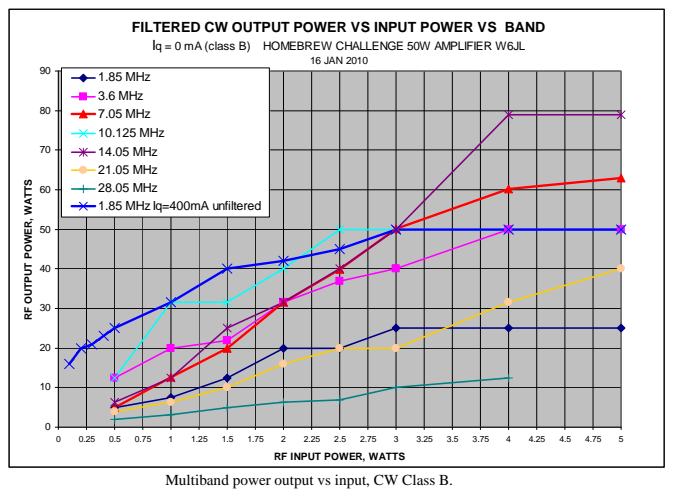
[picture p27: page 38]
16 JAN 2010

FILTERED CW OUTPUT POWER VS INPUT POWER VS BAND
Iq = 0 mA (class B) HOMEBREW CHALLENGE 50W AMPLIFIER W6JL

1.85 MHz 3.6 MHz

7.05 MHz 10.125 MHz 14.05 MHz

21.05 MHz 28.05 MHz

RF OUTPUT POWER, WATTS

1.85 MHz Iq=400mA unfiltered

RF INPUT POWER, WATTS

Multiband power output vs input, CW Class B.

PTT/QSK T/R switching timing. With C12 = 22uF and using Omron G5Y-1-H relays, both relays close (key-down, when nPTT is high) 7 mS after PTT is pulled low (which is key-down) and open 22 mS after PTT goes high (which is key-up). This should be sufficient for QSK at keying speeds up to about 30 wpm if the exciter’s RF output does not rise before 7 mS after key-down, and stays on no longer than 22 mS after key-up. This can usually be easily arranged (especially if the exciter is also homebrew!). It is assumed that the PTT line is controlled by the CW keying line of the exciter. NOTE: The sense of the PTT and resultant relay closures are reversed in these scope traces because a pulse generator was used to drive a mosfet which pulled the relay coils to ground to close the relays. The “nPTT” trace is the positive-going gate drive signal to this mosfet. The closure of the relays was sensed by probing the voltage across a 1K resistor connected between the relay contacts and ground, (with the other set of relay contacts connected to +13.8 VDC), thus this trace also goes high when the relays are closed. Below is a clearer graphic equivalent of the above scope trace photo.

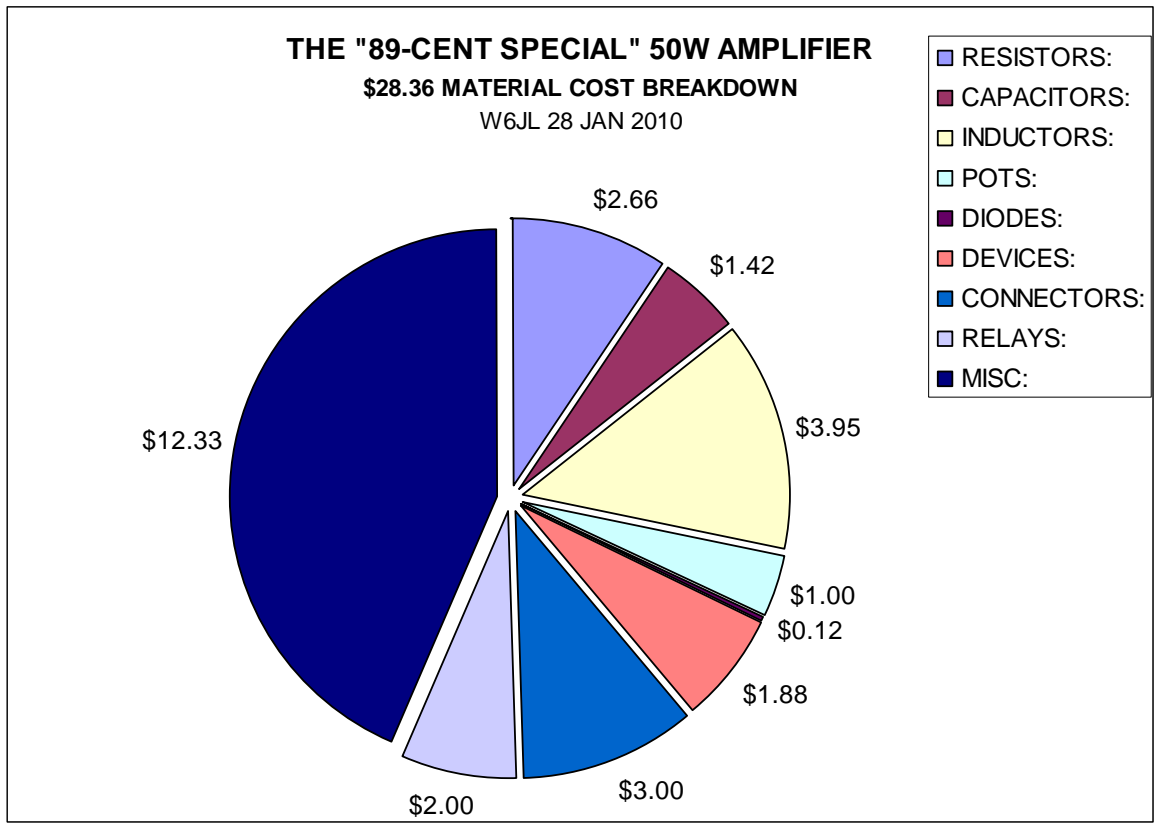
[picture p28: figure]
THE "89-CENT SPECIAL" 50W AMPLIFIER; $28.36 MATERIAL COST BREAKDOWN W6JL 28 JAN 2010; RESISTORS: CAPACITORS: INDUCTORS: POTS: DIODES: DEVICES: CONNECTORS: RELAYS: MISC:

Material cost breakdown for the amplifier. In many cases, the “Miscellaneous” segment (as well as several other segments) of the pie chart can be made $0, if your junk-box is reasonably well-stocked.

AMPLIFIER SIMULATIONS USING LTSPICE:

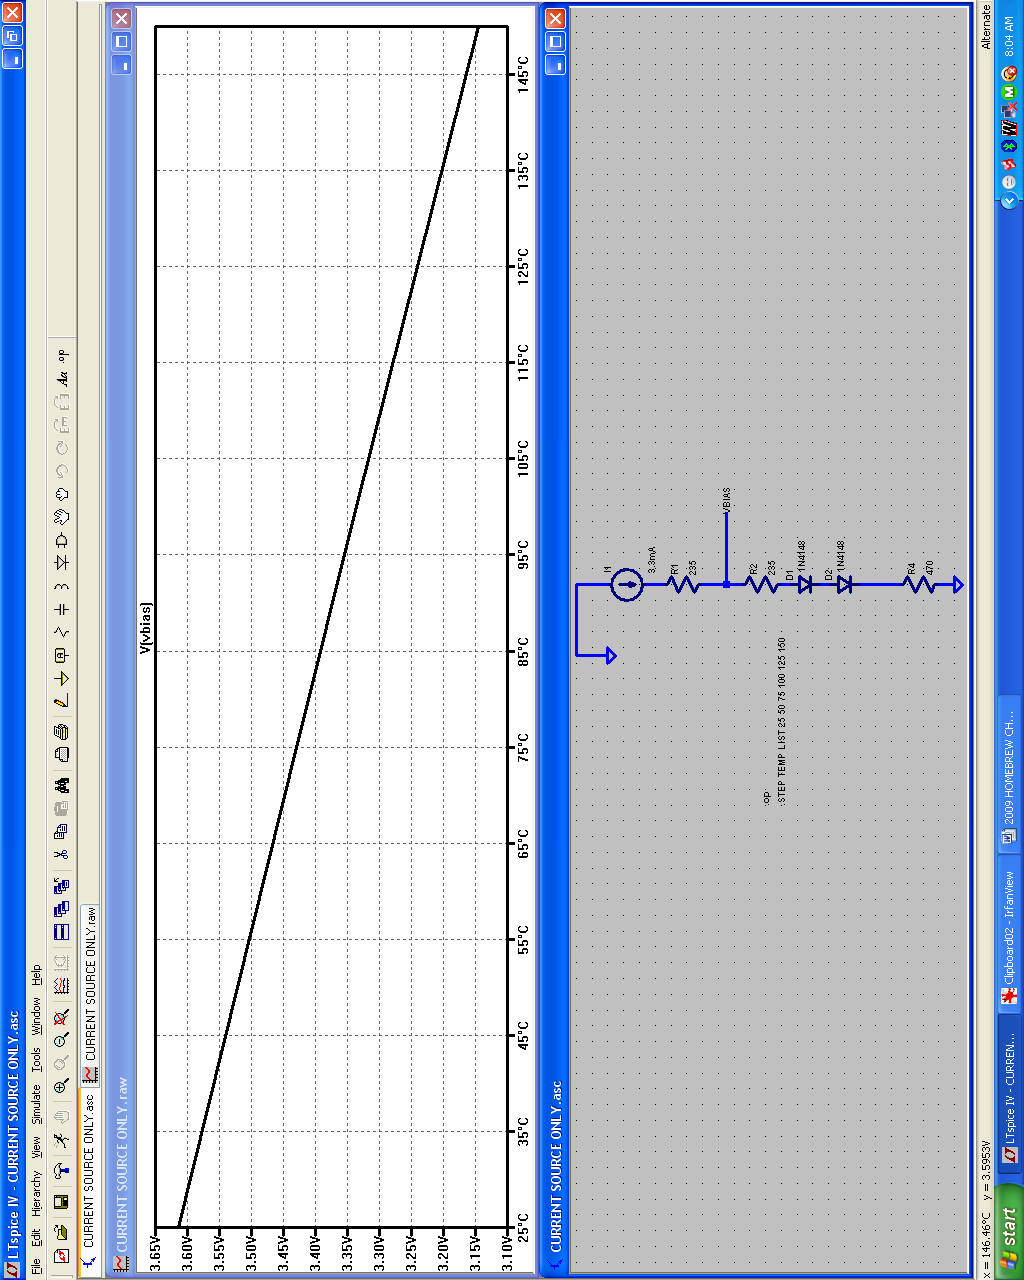
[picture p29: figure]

Biasing circuit temperature dependence simulation run using LTSpice, showing linear decrease of bias voltage with temperature. .

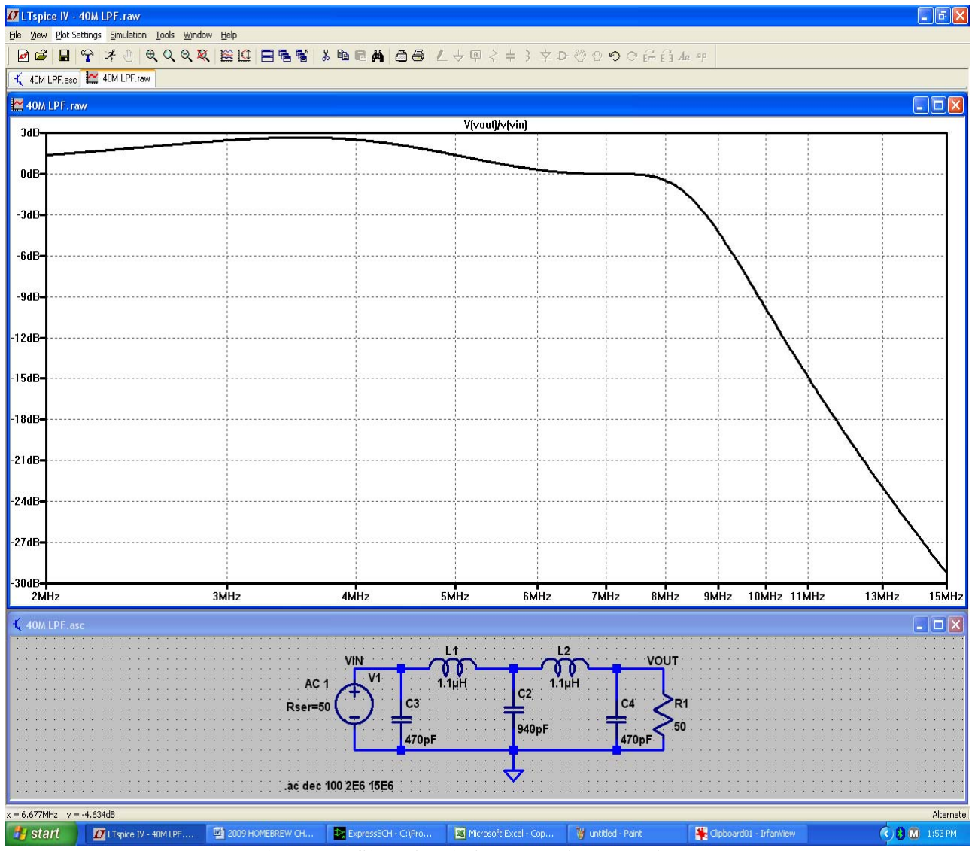
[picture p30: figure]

40M low-pass filter simulation run using LTSpice

Screen shot of entire amplifier simulation for IMD using LTSpice simulator. Simulation shows about minus 29 dBc IMD for this case. A fast fourier transform (FFT) function is available in LTSpice, making it easy to plot IMD directly. The two-tone time domain RF envelope is also plotted. Note the output transformer is modeled as two transformers in series, which it is, electrically. The Fast Fourier Transform (FFT) function in LTSpice can be used to determine the resulting frequency spectrum of any voltage or current in the circuit. In this case the FFT is of the output RF waveform and the plot has been scaled to show directly the resulting IMD products which are tightly clustered around the center frequency of the output RF envelope.

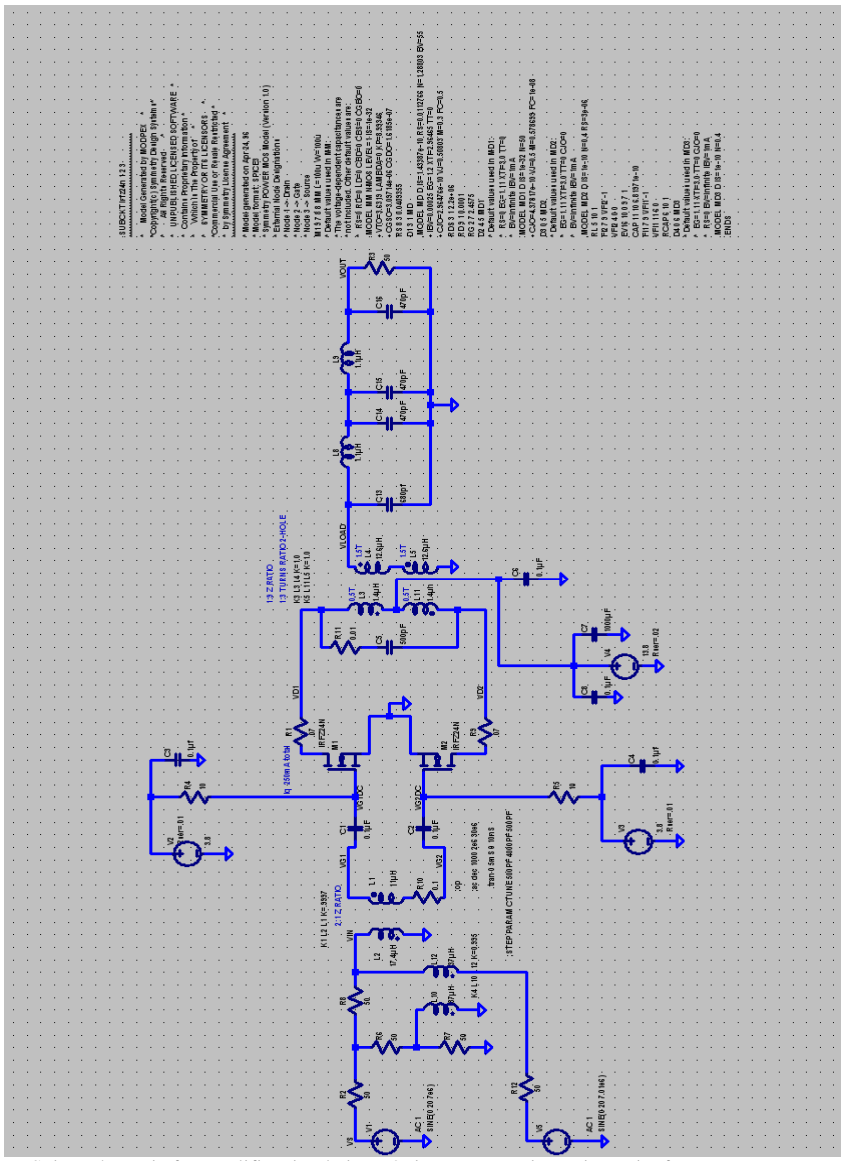
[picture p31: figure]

LTSpice schematic for amplifier simulation. Quiescent operating point, gain, frequency response, IMD, and temperature dependence are easily simulated using the free LTSpice simulation software downloadable (and updatable) from Linear Technologies’ web site (www.linear.com) . Us homebrewers could not imagine having these tools, especially freely available, when I started homebrewing back in the mid 50’s! The spice model text for the IRFZ24N mosfet is put directly onto the schematic as a text file and the mosfet symbols are associated with it. The mosfet spice model is available on the International Rectifier web site (www.irf.com) The simulation schematic includes at the input a homebrew discrete hybrid combiner circuit (see ARRL’s “Experimental Methods in RF Design” book). It enables combining the two closely-spaced RF sources needed to generate the beat note pattern for IMD testing, without each source being affected (modulated) by the other.

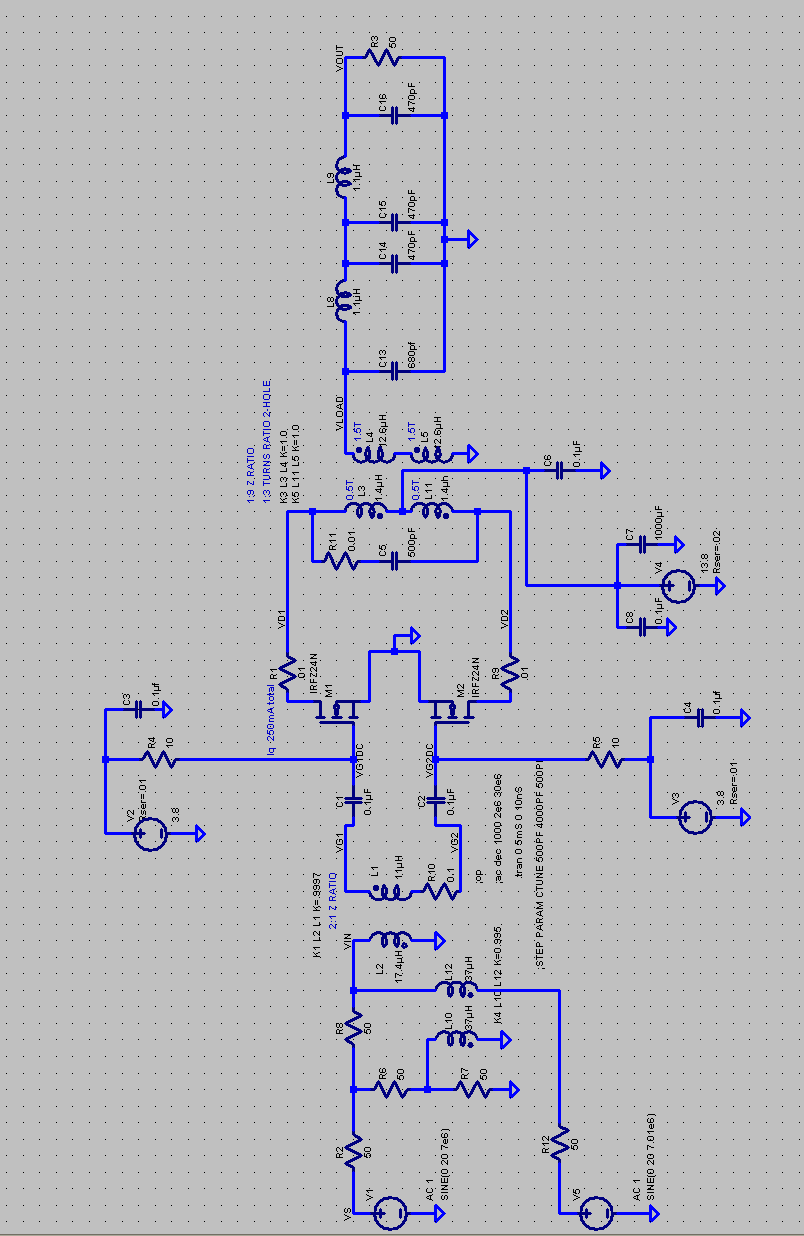
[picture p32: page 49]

SOME USEFUL INTERNET PARTS SOURCES FOR HOMEBREWERS:

www.mouser.com
www.digikey.com
http://www.jameco.com/
http://kitsandparts.com/
http://www.kangaus.com/
http://cbjohn.com/aa0zz/index.htmlhttp://www.farcircuits.net/http://www.danssmallpartsandkits.net/http://comtrolauto.com/
http://www.tubesandmore.com/http://www.elexp.com/
http://www.cwsbytemark.com/mainpage.phphttp://futurlec.com/index.shtmlhttp://www.mfjenterprises.com/Search.phphttp://www.radiodaze.com/
http://www.goldmine-elec-products.com/departments.asphttp://www.cwsbytemark.com/mainpage.phphttp://www.communication-concepts.com/http://www.bgmicro.com/
http://www.aade.com/
http://www.allelectronics.com/http://www.angelfire.com/electronic2/index1/http://www.rfparts.com/
http://www.qrpkits.com/
http://www.oldradioparts.com/http://www.rentron.com/
http://www.mtechnologies.com/index.htmlhttp://www.sdr-kits.net/
http://www.oselectronics.com

SIDEBAR

Where do design equations come from? One should always try to understand where “formulas” come from, instead of just accepting the author’s use of them. All formulas are based on assumptions and simplifications, which may or may not apply to the case at hand. We can easily derive the equation for calculating required drain-to-drain load resistance from supply voltage and desired output power of Class B or AB mosfet RF amp:

From our knowledge that for a push-pull transformer-coupled class B or AB amplifier, we know that for each mosfet the drain voltage excursion will be about twice the supply voltage (2Vcc). This is because each half of the primary swings from near zero (mosfet ON, opposite mosfet OFF), to near twice Vcc (mosfet OFF, opposite mosfet ON), centered around Vcc. And, both halves of the primary are in series and are 180 degrees out of phase (hence the term “push-pull”). Each mosfet drain sees a total swing of 2Vcc pk-pk, thus the total primary voltage swing is the difference between the two drain voltages, allowing for the fact that the lower drain voltage is always 180 degrees out of phase with the upper one (ie, it is always the negative value of the upper voltage). Now, with any sine wave, we know that we just divide its peak-to-peak value by 2.828, which is twice the square root of 2, to obtain its RMS value. We now have all the information we need to derive an equation relating the power output and the drain-to-drain primary load impedance.

Reiterating from above,

( | ( | )) ( | ) | Vcc Vprimarypk pk Vdrain Vdrain | Vcc | Vcc | Vcc Vprimaryrms | 2

2 2

4
2
2 | 2
2
1 | 1
2 2 | = | = - - = - = - =

And, remembering from Ohm’s Law how to calculate power in a resistor:
( )
Rout
Vout Pout | rns

2
=
Now, substituting from above we get, | ( ) ( )( )

Rout

Vcc
Rout

Vcc Pout

2 2
2 | 2 = | =

Starting to look familiar? Now, rearranging the equation to solve for Rout:
( )( )
Pout

Vcc Rout

2 2 = | Voila! Now, that was not so hard, was it?

And now we know where that equation from the 2010 ARRL Handbook, page 17.35, comes from and we can use it with more confidence.

A really instructive way to verify the above and get a feel for how things work, is to use a circuit simulator, such as LTSpiceIV. Let’s do it. Below is a transient response run of the entire amplifier circit. From it we can plot any voltage or current in the circuit, vs time:

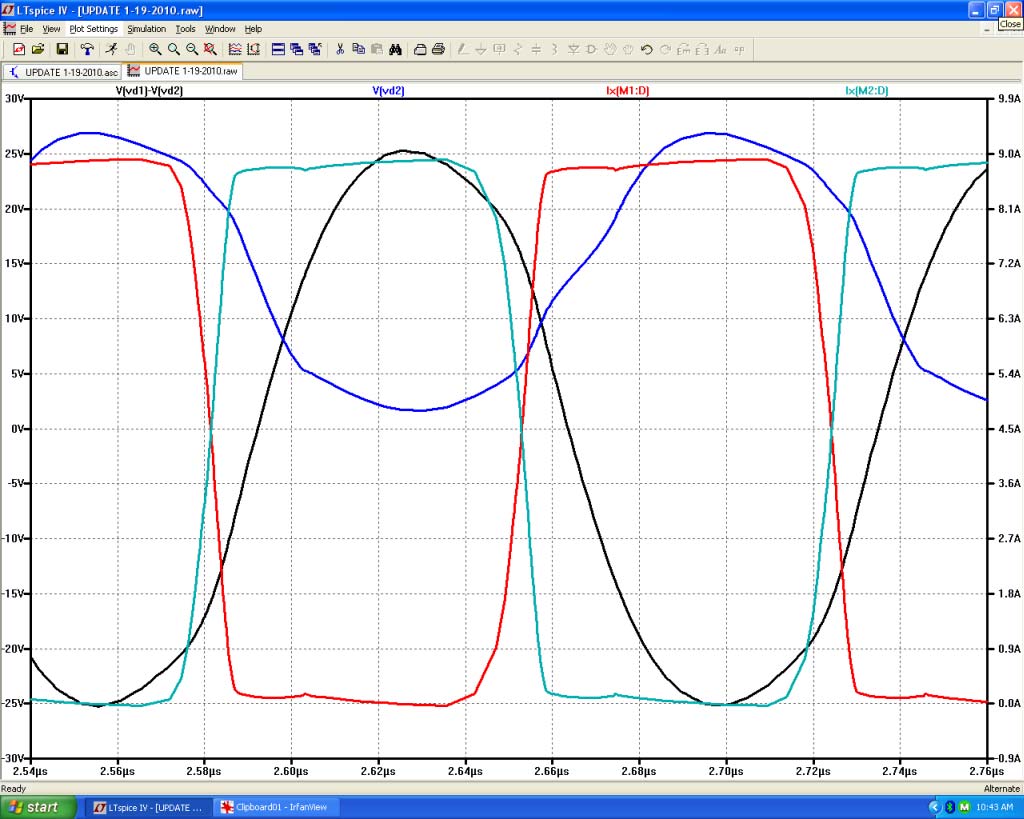
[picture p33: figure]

The four waveforms plotted are the drain voltage and current for each mosfet, plus the total primary voltage end to end, which is V(Vd1)-V(Vd2) (black trace). We can see that the peak to peak total primary voltage is near four times Vcc, as we expected. Note that the primary voltage is approximately a sine wave, whereas the primary current is nearly a square wave. Circuit simulators are great design tools, but equally useful as learning tools. And since this one is FREE (and even has free online support via Linear Technologies’ LTSpice User’s Forum), why not use it? These waveforms are somewhat idealized however, as the simulation model of the mosfet does not take into account the voltage-dependent capacitances in the mosfets. Any simulation’s accuracy is only as good as the models of the circuits and devices used in the simulation. These waveforms do not look quite so clean on the oscilloscope (reality). However, even a limited simulation is a very valuable design, verification, and learning tool, one which any homebrewer today should have in his toolbox.

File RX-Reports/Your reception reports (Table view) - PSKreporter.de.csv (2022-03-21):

ID | Date | UTC | Age | Callsign | SNR (db) | Mode | Band | QRG (MHz) | Country | DXCC | Locator | QRB (km)
28 | 2021-10-19 | 02:57:34 | 7h:52m | 3D2USU | -17 | FT8 | 20m | 14.0743 | Fiji | 3D2 | RH82RH | 12011
195 | 2021-10-18 | 12:26:26 | 22h:23m | VK2QV | 1 | FT8 | 20m | 14.0742 | Australia | VK | QF56LG | 10012
43 | 2021-10-18 | 15:03:27 | 19h:46m | VK5GR | -17 | FT8 | 20m | 14.0743 | Australia | VK | PF95ID | 9056
8 | 2021-10-19 | 10:37:30 | 12min | VK5ARG | -9 | FT8 | 20m | 14.0743 | Australia | VK | PF95IT | 9019
42 | 2021-10-18 | 15:05:30 | 19h:44m | ZS1VV | -12 | FT8 | 20m | 14.0743 | South Africa | ZS | KF05PW | 8085
60 | 2021-10-18 | 14:48:27 | 20h:01m | G1HCM | -19 | FT8 | 20m | 14.0743 | England | G | IO90 | 7871
121 | 2021-10-18 | 13:49:29 | 21h:00m | GI7AXB | -14 | FT8 | 20m | 14.0743 | Northern Ireland | GI | IO74AS11 | 7702
79 | 2021-10-18 | 14:37:29 | 20h:12m | GM8FXD | -16 | FT8 | 20m | 14.0743 | Scotland | GM | IO77SH | 7600
118 | 2021-10-18 | 13:50:29 | 20h:59m | GØJHC | -14 | FT8 | 20m | 14.0743 | England | G | IO83PQ24 | 7495
49 | 2021-10-18 | 14:57:27 | 19h:52m | G7JAF | -17 | FT8 | 20m | 14.0743 | England | G | IO93FI | 7418
80 | 2021-10-18 | 14:36:27 | 20h:13m | ZS5ZP | -5 | FT8 | 20m | 14.0742 | South Africa | ZS | KF59DA | 7222
25 | 2021-10-19 | 05:45:26 | 5h:04m | VK6MIT | -10 | FT8 | 20m | 14.0743 | Australia | VK | OF78WC | 7175
1 | 2021-10-19 | 10:48:26 | 1min | VK6FR | - | FT8 | 20m | 14.0742 | Australia | VK | OF78VE | 7163
179 | 2021-10-18 | 12:46:29 | 22h:03m | VK4ABW | -12 | FT8 | 20m | 14.0742 | Australia | VK | PH57KQ | 7127
164 | 2021-10-18 | 13:01:27 | 21h:48m | LA1B | -19 | FT8 | 20m | 14.0743 | Norway | LA | JP20RH | 7055
191 | 2021-10-18 | 12:33:27 | 22h:16m | ZS6DPS | -6 | FT8 | 20m | 14.0742 | South Africa | ZS | KG33WV | 7036
55 | 2021-10-18 | 14:49:28 | 20h:00m | ON7DE | -22 | FT8 | 20m | 14.0743 | Belgium | ON | JO20DX | 7011
81 | 2021-10-18 | 14:35:30 | 20h:14m | ZS6UB | -17 | FT8 | 20m | 14.0743 | South Africa | ZS | KG43DT | 7010
113 | 2021-10-18 | 13:51:29 | 20h:58m | LA7DFA | -18 | FT8 | 20m | 14.0743 | Norway | LA | JP33VJ | 7001
37 | 2021-10-18 | 15:23:27 | 19h:26m | ZR6AMC | -9 | FT8 | 20m | 14.0743 | South Africa | ZS | KG44DG | 6977
109 | 2021-10-18 | 13:53:27 | 20h:56m | ON3CQ | -14 | FT8 | 20m | 14.0743 | Belgium | ON | JO21LH86 | 6967
114 | 2021-10-18 | 13:51:27 | 20h:58m | JH8FIH | -17 | FT8 | 20m | 14.0742 | Japan | JA | QN14QI25 | 6967
67 | 2021-10-18 | 14:42:30 | 20h:07m | PAØADG | -10 | FT8 | 20m | 14.0743 | Netherlands | PA | JO22NB | 6963
66 | 2021-10-18 | 14:43:27 | 20h:06m | PD1AIQ | -15 | FT8 | 20m | 14.0742 | Netherlands | PA | JO22RM | 6944
69 | 2021-10-18 | 14:41:29 | 20h:08m | PA3AIW | -18 | FT8 | 20m | 14.0743 | Netherlands | PA | JO21RX70 | 6939
98 | 2021-10-18 | 14:06:27 | 20h:43m | ON5HE | -14 | FT8 | 20m | 14.0753 | Belgium | ON | JO20PI | 6936
106 | 2021-10-18 | 13:59:27 | 20h:50m | PA3CPS | -19 | FT8 | 20m | 14.0743 | Netherlands | PA | JO32BH | 6897
68 | 2021-10-18 | 14:42:27 | 20h:07m | PA2CV | -19 | FT8 | 20m | 14.0743 | Netherlands | PA | JO32BF71 | 6896
123 | 2021-10-18 | 13:46:27 | 21h:03m | JR8ORC | -18 | FT8 | 20m | 14.0743 | Japan | JA | QN05UJ | 6838
54 | 2021-10-18 | 14:49:29 | 20h:00m | F4EJL | -16 | FT8 | 20m | 14.0743 | France | F | JN39HF43 | 6831
124 | 2021-10-18 | 13:46:27 | 21h:03m | LB1RJ | -17 | FT8 | 20m | 14.0742 | Norway | LA | JO49PN | 6830
119 | 2021-10-18 | 13:50:27 | 20h:59m | JA7FTR | -16 | FT8 | 20m | 14.0742 | Japan | JA | QM08TV | 6826
174 | 2021-10-18 | 12:53:27 | 21h:56m | OZ1BUR | -22 | FT8 | 20m | 14.0742 | Denmark | OZ | JO46HI48 | 6799
134 | 2021-10-18 | 13:24:32 | 21h:25m | JA7HRF | -19 | FT8 | 20m | 14.0742 | Japan | JA | QM09NF80 | 6782
153 | 2021-10-18 | 13:05:30 | 21h:44m | F5PAC | -15 | FT8 | 20m | 14.0742 | France | F | JN37OT84 | 6776
111 | 2021-10-18 | 13:51:29 | 20h:58m | F6DHD | -14 | FT8 | 20m | 14.0743 | France | F | JN38QS | 6772
130 | 2021-10-18 | 13:27:27 | 21h:22m | OZ1GHK | -14 | FT8 | 20m | 14.0743 | Denmark | OZ | JO45JD | 6765
163 | 2021-10-18 | 13:01:29 | 21h:48m | JA7QVI | -17 | FT8 | 20m | 14.0742 | Japan | JA | QM08KA | 6763
217 | 2021-10-18 | 11:50:26 | 22h:59m | JH1DMS | -9 | FT8 | 20m | 14.0742 | Japan | JA | QM06FJ | 6732
169 | 2021-10-18 | 12:55:26 | 21h:54m | JH7WNV | -13 | FT8 | 20m | 14.0742 | Japan | JA | QM07FO | 6728
166 | 2021-10-18 | 12:59:29 | 21h:50m | JJ7LUO | -7 | FT8 | 20m | 14.0742 | Japan | JA | QM09FC | 6725
90 | 2021-10-18 | 14:23:30 | 20h:26m | OZ3K | -15 | FT8 | 20m | 14.0743 | Denmark | OZ | JO45TL21 | 6720
133 | 2021-10-18 | 13:25:29 | 21h:24m | JJ1TKN | -19 | FT8 | 20m | 14.0742 | Japan | JA | QM06DE18QC | 6718
219 | 2021-10-18 | 11:47:30 | 23h:02m | JH7BKN | -18 | FT8 | 20m | 14.0742 | Japan | JA | QN00ER | 6718
160 | 2021-10-18 | 13:03:27 | 21h:46m | JA7HRM | -8 | FT8 | 20m | 14.0742 | Japan | JA | QM08DF | 6712
168 | 2021-10-18 | 12:57:29 | 21h:52m | JS1MRA | -17 | FT8 | 20m | 14.0742 | Japan | JA | QM05BR | 6705
185 | 2021-10-18 | 12:35:29 | 22h:14m | JI1MUT | -15 | FT8 | 20m | 14.0742 | Japan | JA | PM95XT | 6689
129 | 2021-10-18 | 13:30:30 | 21h:19m | DF4WC | -18 | FT8 | 20m | 14.0743 | Germany | DL | JN49KV01 | 6677
176 | 2021-10-18 | 12:51:29 | 21h:58m | JK1CEK | -18 | FT8 | 20m | 14.0743 | Japan | JA | PM95UO96 | 6667
177 | 2021-10-18 | 12:51:29 | 21h:58m | JL1UXH | -19 | FT8 | 20m | 14.0742 | Japan | JA | PM95UO86 | 6667
172 | 2021-10-18 | 12:53:30 | 21h:56m | JL1XMN | -17 | FT8 | 20m | 14.0742 | Japan | JA | PM96UA | 6666
147 | 2021-10-18 | 13:16:26 | 21h:33m | JL1JVT | -10 | FT8 | 20m | 14.0742 | Japan | JA | PM96UD | 6665
143 | 2021-10-18 | 13:17:30 | 21h:32m | JA1FON | -15 | FT8 | 20m | 14.0742 | Japan | JA | PM95TQ26CS | 6660
145 | 2021-10-18 | 13:17:29 | 21h:32m | JA1GLM | -16 | FT8 | 20m | 14.0743 | Japan | JA | PM95TP | 6660
165 | 2021-10-18 | 13:00:27 | 21h:49m | JK1PIU | -16 | FT8 | 20m | 14.0743 | Japan | JA | PM95SK | 6653
94 | 2021-10-18 | 14:16:31 | 20h:33m | JM1SZY | -20 | FT8 | 20m | 14.0742 | Japan | JA | PM95SO31LE | 6652
173 | 2021-10-18 | 12:53:30 | 21h:56m | JR1NHD | -18 | FT8 | 20m | 14.0742 | Japan | JA | PM95SO | 6652
216 | 2021-10-18 | 11:51:29 | 22h:58m | JG1RBF | -19 | FT8 | 20m | 14.0742 | Japan | JA | PM95RN | 6645
116 | 2021-10-18 | 13:51:26 | 20h:58m | DB1WR | -17 | FT8 | 20m | 14.0743 | Germany | DL | JO53CL | 6643
209 | 2021-10-18 | 12:09:26 | 22h:40m | JG1OGM | -11 | FT8 | 20m | 14.0742 | Japan | JA | PM96RA | 6643
213 | 2021-10-18 | 11:53:29 | 22h:56m | JE1RMI | -14 | FT8 | 20m | 14.0742 | Japan | JA | PM95QP | 6637
188 | 2021-10-18 | 12:33:29 | 22h:16m | JR1QKF | -15 | FT8 | 20m | 14.0742 | Japan | JA | PM95NI | 6616
150 | 2021-10-18 | 13:09:29 | 21h:40m | JI1DMH | -19 | FT8 | 20m | 14.0742 | Japan | JA | PM96NF47 | 6613
186 | 2021-10-18 | 12:35:26 | 22h:14m | JE1NZZ | -9 | FT8 | 20m | 14.0743 | Japan | JA | PM96NE46 | 6613
204 | 2021-10-18 | 12:13:27 | 22h:36m | JJ1IWF | -9 | FT8 | 20m | 14.0742 | Japan | JA | PM96NB | 6613
206 | 2021-10-18 | 12:11:29 | 22h:38m | JE1CSW | -14 | FT8 | 20m | 14.0743 | Japan | JA | PM96NJ | 6612
93 | 2021-10-18 | 14:20:29 | 20h:29m | JHØRNN | -19 | FT8 | 20m | 14.0742 | Japan | JA | PM97NV | 6610
232 | 2021-10-18 | 11:11:29 | 23h:38m | JA1GPN | -18 | FT8 | 20m | 14.0742 | Japan | JA | PM96MH | 6605
157 | 2021-10-18 | 13:05:27 | 21h:44m | OZ1RH | -15 | FT8 | 20m | 14.0743 | Denmark | OZ | JO55TN | 6598
170 | 2021-10-18 | 12:54:29 | 21h:55m | JIØWVQ | -12 | FT8 | 20m | 14.0743 | Japan | JA | PM97KA | 6589
180 | 2021-10-18 | 12:44:27 | 22h:05m | DM4ET | -12 | FT8 | 20m | 14.0743 | Germany | DL | JO52JM | 6586
138 | 2021-10-18 | 13:21:26 | 21h:28m | JG1SYK | -20 | FT8 | 20m | 14.0743 | Japan | JA | PM95IQ | 6577
178 | 2021-10-18 | 12:48:26 | 22h:01m | JF1KMC | -8 | FT8 | 20m | 14.0742 | Japan | JA | PM95GP44TT | 6562
203 | 2021-10-18 | 12:14:29 | 22h:35m | JK1AUS | -5 | FT8 | 20m | 14.0742 | Japan | JA | PM95EV | 6546
72 | 2021-10-18 | 14:41:27 | 20h:08m | DL9QB | -15 | FT8 | 20m | 14.0743 | Germany | DL | JO50NV | 6534
192 | 2021-10-18 | 12:29:31 | 22h:20m | JRØQFA | -19 | FT8 | 20m | 14.0742 | Japan | JA | PM85XU | 6509
221 | 2021-10-18 | 11:47:27 | 23h:02m | SM4RGD | -4 | FT8 | 20m | 14.0742 | Sweden | SM | JO79MD | 6503
224 | 2021-10-18 | 11:43:30 | 23h:06m | DJ9PC | -12 | FT8 | 20m | 14.0743 | Germany | DL | JN59PO26 | 6500
56 | 2021-10-18 | 14:49:27 | 20h:00m | DL6NAC | -15 | FT8 | 20m | 14.0743 | Germany | DL | JO50RC23 | 6497
199 | 2021-10-18 | 12:20:27 | 22h:29m | JR2ATZ | -12 | FT8 | 20m | 14.0742 | Japan | JA | PM84VR | 6496
20 | 2021-10-19 | 09:52:30 | 57min | JA9LX | -19 | FT8 | 20m | 14.0743 | Japan | JA | PM86SW69 | 6470
73 | 2021-10-18 | 14:41:27 | 20h:08m | SM3XGV | -7 | FT8 | 20m | 14.0742 | Sweden | SM | JP81OF | 6466
115 | 2021-10-18 | 13:51:27 | 20h:58m | DL3OI | -8 | FT8 | 20m | 14.0742 | Germany | DL | JN58UB | 6446
175 | 2021-10-18 | 12:52:29 | 21h:57m | JH2KVP | -19 | FT8 | 20m | 14.0743 | Japan | JA | PM84OW | 6442
184 | 2021-10-18 | 12:36:29 | 22h:13m | JA9FFS | -17 | FT8 | 20m | 14.0742 | Japan | JA | PM86MT | 6426
148 | 2021-10-18 | 13:14:31 | 21h:35m | JH2QBV | -14 | FT8 | 20m | 14.0742 | Japan | JA | PM85LD | 6419
197 | 2021-10-18 | 12:21:26 | 22h:28m | JF2DKK | -17 | FT8 | 20m | 14.0743 | Japan | JA | PM85LC | 6419
202 | 2021-10-18 | 12:18:26 | 22h:31m | JR2EUE | -16 | FT8 | 20m | 14.0742 | Japan | JA | PM85LD | 6419
194 | 2021-10-18 | 12:27:27 | 22h:22m | DL7TY | -12 | FT8 | 20m | 14.0742 | Germany | DL | JO62RJ | 6406
151 | 2021-10-18 | 13:07:30 | 21h:42m | DF1YQ | -17 | FT8 | 20m | 14.0742 | Germany | DL | JO62TI | 6394
139 | 2021-10-18 | 13:21:26 | 21h:28m | JA2JRG | -16 | FT8 | 20m | 14.0743 | Japan | JA | PM84HM | 6390
198 | 2021-10-18 | 12:20:29 | 22h:29m | JF2ERJ | -10 | FT8 | 20m | 14.0743 | Japan | JA | PM84GS | 6382
140 | 2021-10-18 | 13:20:26 | 21h:29m | JA9PHV | -10 | FT8 | 20m | 14.0742 | Japan | JA | PM86CB | 6351
142 | 2021-10-18 | 13:17:30 | 21h:32m | JA9KA | -15 | FT8 | 20m | 14.0742 | Japan | JA | PM85CV | 6351
146 | 2021-10-18 | 13:16:29 | 21h:33m | JH3DRN | -15 | FT8 | 20m | 14.0758 | Japan | JA | PM85CC | 6351
171 | 2021-10-18 | 12:54:28 | 21h:55m | JA2EID | -15 | FT8 | 20m | 14.0742 | Japan | JA | PM84BS54 | 6344
193 | 2021-10-18 | 12:29:30 | 22h:20m | JR3FSR | -18 | FT8 | 20m | 14.0742 | Japan | JA | PM75XB | 6328
88 | 2021-10-18 | 14:25:28 | 20h:24m | OK1VRV | -11 | FT8 | 20m | 14.0742 | Czech Rep. | OK | JO60XJ74LP | 6327
47 | 2021-10-18 | 14:59:30 | 19h:50m | DLØPF-PAVEL | -15 | FT8 | 20m | 14.0742 | Germany | DL | JN68RN | 6326
48 | 2021-10-18 | 14:59:15 | 19h:51m | DLØPF | -15 | FT8 | 20m | 14.0743 | Germany | DL | JN68RN16 | 6326
156 | 2021-10-18 | 13:05:29 | 21h:44m | JH3IEG | -19 | FT8 | 20m | 14.0742 | Japan | JA | PM74WM | 6321
190 | 2021-10-18 | 12:33:27 | 22h:16m | JA3LZS | -11 | FT8 | 20m | 14.0742 | Japan | JA | PM74UM | 6306
225 | 2021-10-18 | 11:42:30 | 23h:07m | JF3DRI | -21 | FT8 | 20m | 14.0743 | Japan | JA | PM74UO61 | 6306
196 | 2021-10-18 | 12:24:26 | 22h:25m | JR3IAO | -8 | FT8 | 20m | 14.0742 | Japan | JA | PM74SR | 6290
223 | 2021-10-18 | 11:44:29 | 23h:05m | JA3IWB | -15 | FT8 | 20m | 14.0742 | Japan | JA | PM74SQ | 6290
226 | 2021-10-18 | 11:42:29 | 23h:07m | JA3JFT | -12 | FT8 | 20m | 14.0742 | Japan | JA | PM74SS26XG | 6290
231 | 2021-10-18 | 11:17:30 | 23h:32m | JO3TAP | -19 | FT8 | 20m | 14.0743 | Japan | JA | PM74SR | 6290
86 | 2021-10-18 | 14:25:30 | 20h:24m | IV3DXW | -17 | FT8 | 20m | 14.0742 | Italy | I | JN65QQ63 | 6284
161 | 2021-10-18 | 13:03:27 | 21h:46m | JE3RMQ | -10 | FT8 | 20m | 14.0742 | Japan | JA | PM74RN | 6283
227 | 2021-10-18 | 11:42:26 | 23h:07m | JS3CTF | -16 | FT8 | 20m | 14.0743 | Japan | JA | PM74RM | 6283
159 | 2021-10-18 | 13:03:30 | 21h:46m | JH3AIU | -17 | FT8 | 20m | 14.0742 | Japan | JA | PM74OV38GU | 6260
222 | 2021-10-18 | 11:45:26 | 23h:04m | JH3SIF | -9 | FT8 | 20m | 14.0743 | Japan | JA | PM74NQ | 6252
110 | 2021-10-18 | 13:53:27 | 20h:56m | OH1EDK | -18 | FT8 | 20m | 14.0743 | Finland | OH | KP01WL | 6248
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

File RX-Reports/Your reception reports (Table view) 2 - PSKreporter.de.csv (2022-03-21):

ID | Date | UTC | Age | Callsign | SNR (db) | Mode | Band | QRG (MHz) | Country | DXCC | Locator | QRB (km)
74 | 2021-11-06 | 02:27:29 | 11h:48m | PY2NL | -13 | FT8 | 20m | 14.0747 | Brazil | PY | GG77KG30 | 13716
63 | 2021-11-06 | 10:35:30 | 3h:40m | 3D2MP | -17 | FT8 | 20m | 14.0759 | Fiji | 3D2 | RH91FU36 | 12127
61 | 2021-11-06 | 10:55:34 | 3h:20m | 3D2USU | -14 | FT8 | 20m | 14.0747 | Fiji | 3D2 | RH82RH | 12011
35 | 2021-11-06 | 12:28:30 | 1h:47m | FK8HM | -18 | FT8 | 20m | 14.0747 | New Caledonia | FK | RG37FS | 11033
18 | 2021-11-06 | 12:53:30 | 1h:22m | VK2AMA | -18 | FT8 | 20m | 14.0747 | Australia | VK | QF54HU | 10044
30 | 2021-11-06 | 12:37:29 | 1h:38m | VK2AHE | -14 | FT8 | 20m | 14.0747 | Australia | VK | QF57TA | 10038
32 | 2021-11-06 | 12:36:27 | 1h:39m | VK2LAW | -16 | FT8 | 20m | 14.0747 | Australia | VK | QF56NB | 10035
34 | 2021-11-06 | 12:29:28 | 1h:46m | VK1OO | -9 | FT8 | 20m | 14.0747 | Australia | VK | QF44NO44 | 9930
10 | 2021-11-06 | 13:12:29 | 1h:03m | VK3XN | -16 | FT8 | 20m | 14.0747 | Australia | VK | QF22PE | 9731
9 | 2021-11-06 | 13:16:27 | 59min | VK3MB | -17 | FT8 | 20m | 14.0747 | Australia | VK | QF22NJ | 9708
15 | 2021-11-06 | 12:56:30 | 1h:19m | VK5ARG | -10 | FT8 | 20m | 14.0747 | Australia | VK | PF95IT | 9019
4 | 2021-11-06 | 13:50:32 | 25min | ZS6HON | -7 | FT8 | 20m | 14.0747 | South Africa | ZS | KG44 | 7620
49 | 2021-11-06 | 11:55:27 | 2h:20m | VK6LG | -10 | FT8 | 20m | 14.0747 | Australia | VK | OF84WX | 7553
14 | 2021-11-06 | 12:58:26 | 1h:17m | VK6AXD | -10 | FT8 | 20m | 14.0747 | Australia | VK | OF77VQ | 7203
58 | 2021-11-06 | 11:32:29 | 2h:43m | VK6RK | -14 | FT8 | 20m | 14.0747 | Australia | VK | OF77XW84 | 7194
26 | 2021-11-06 | 12:39:26 | 1h:36m | VK6TB | -13 | FT8 | 20m | 14.0747 | Australia | VK | OF77VW | 7183
29 | 2021-11-06 | 12:38:26 | 1h:37m | VK6ZG | -10 | FT8 | 20m | 14.0757 | Australia | VK | OF78WB | 7178
20 | 2021-11-06 | 12:53:27 | 1h:22m | VK6EI | -9 | FT8 | 20m | 14.0747 | Australia | VK | OF78XE | 7174
41 | 2021-11-06 | 12:14:29 | 2h:01m | VK4ABW | -17 | FT8 | 20m | 14.0747 | Australia | VK | PH57KQ | 7127
47 | 2021-11-06 | 12:02:27 | 2h:13m | OZ1BUR | -15 | FT8 | 20m | 14.0747 | Denmark | OZ | JO46HI48 | 6799
48 | 2021-11-06 | 11:56:27 | 2h:19m | JH7RTQ | -8 | FT8 | 20m | 14.0747 | Japan | JA | QM07FS36 | 6727
3 | 2021-11-06 | 13:56:29 | 19min | JM1HXU | -17 | FT8 | 20m | 14.0747 | Japan | JA | QM05AU19 | 6697
56 | 2021-11-06 | 11:37:26 | 2h:38m | JH1LZU | -14 | FT8 | 20m | 14.0747 | Japan | JA | PM95SI | 6653
55 | 2021-11-06 | 11:37:29 | 2h:38m | JR1NHD | -16 | FT8 | 20m | 14.0747 | Japan | JA | PM95SO | 6652
37 | 2021-11-06 | 12:27:29 | 1h:48m | JH1RKS | -10 | FT8 | 20m | 14.0747 | Japan | JA | PM96PF | 6628
54 | 2021-11-06 | 11:39:29 | 2h:36m | JE1LET | -15 | FT8 | 20m | 14.0748 | Japan | JA | PM95NG81PN | 6616
38 | 2021-11-06 | 12:26:29 | 1h:49m | JE1CSW | -15 | FT8 | 20m | 14.0747 | Japan | JA | PM96NJ | 6612
5 | 2021-11-06 | 13:39:29 | 36min | JA1GPN | -17 | FT8 | 20m | 14.0747 | Japan | JA | PM96MH | 6605
51 | 2021-11-06 | 11:44:29 | 2h:31m | JAØEIY | -19 | FT8 | 20m | 14.0747 | Japan | JA | PM96HX | 6567
53 | 2021-11-06 | 11:40:27 | 2h:35m | DL1NEO | -15 | FT8 | 20m | 14.0747 | Germany | DL | JN59KV30 | 6535
33 | 2021-11-06 | 12:30:29 | 1h:45m | JE2WTX | -12 | FT8 | 20m | 14.0747 | Japan | JA | PM84LW | 6420
24 | 2021-11-06 | 12:41:30 | 1h:34m | JI2KUJ | -18 | FT8 | 20m | 14.0747 | Japan | JA | PM85KA | 6412
23 | 2021-11-06 | 12:42:27 | 1h:33m | JA2JRG | -16 | FT8 | 20m | 14.0747 | Japan | JA | PM84HM | 6390
22 | 2021-11-06 | 12:43:29 | 1h:32m | JG3SKK | -18 | FT8 | 20m | 14.0747 | Japan | JA | PM74QG81 | 6275
45 | 2021-11-06 | 12:10:29 | 2h:05m | JM3OCJ | -18 | FT8 | 20m | 14.0747 | Japan | JA | PM74HT | 6207
6 | 2021-11-06 | 13:31:29 | 44min | JG4CSI | -17 | FT8 | 20m | 14.0747 | Japan | JA | PM64XM | 6145
44 | 2021-11-06 | 12:10:29 | 2h:05m | JH4JOM | -19 | FT8 | 20m | 14.0747 | Japan | JA | PM64FK | 6008
43 | 2021-11-06 | 12:13:26 | 2h:02m | JR4VUV | -15 | FT8 | 20m | 14.0747 | Japan | JA | PM54OA | 5891
42 | 2021-11-06 | 12:14:27 | 2h:01m | JA4LVZ | -16 | FT8 | 20m | 14.0747 | Japan | JA | PM64 | 5452
2 | 2021-11-06 | 14:00:30 | 15min | FR4UB | -13 | FT8 | 20m | 14.0747 | Reunion Island | FR | LG97 | 5436
59 | 2021-11-06 | 11:19:27 | 2h:56m | YB2MDU | -10 | FT8 | 20m | 14.0747 | Indonesia | YB | OI53KD | 4940
65 | 2021-11-06 | 10:10:29 | 4h:05m | YB2TX | -14 | FT8 | 20m | 14.0746 | Indonesia | YB | OI53FA | 4910
69 | 2021-11-06 | 02:59:30 | 11h:16m | YB2HND | -15 | FT8 | 20m | 14.0747 | Indonesia | YB | OI52EW | 4908
66 | 2021-11-06 | 03:11:27 | 11h:04m | R8ØØSAN | -13 | FT8 | 20m | 14.0762 | Russia-AS | UA9 | OO06VH | 4805
11 | 2021-11-06 | 12:59:27 | 1h:16m | YB1BZV | -3 | FT8 | 20m | 14.0747 | Indonesia | YB | OI33VA07 | 4675
67 | 2021-11-06 | 03:08:29 | 11h:07m | YC1INQ | -19 | FT8 | 20m | 14.0750 | Indonesia | YB | OI33MG | 4592
71 | 2021-11-06 | 02:46:26 | 11h:29m | YG1AEX | -10 | FT8 | - | 0.0000 | Indonesia | YB | OI33MG | 4592
62 | 2021-11-06 | 10:46:29 | 3h:29m | RWØSR | -18 | FT8 | 20m | 14.0746 | Russia-AS | UA9 | OO22CG | 4586
16 | 2021-11-06 | 12:55:30 | 1h:20m | TA4/G8SCU | -14 | FT8 | 20m | 14.0747 | Asiatic Turkey | TA | KM56VO | 4575
17 | 2021-11-06 | 12:54:29 | 1h:21m | YC1AYO | -15 | FT8 | 20m | 14.0747 | Indonesia | YB | OI33MN | 4572
76 | 2021-11-06 | 02:15:29 | 12h:00m | YCØDMS | -19 | FT8 | 20m | 14.0748 | Indonesia | YB | OI33JQ | 4542
39 | 2021-11-06 | 12:23:29 | 1h:52m | YCØSAS | -15 | FT8 | 20m | 14.0747 | Indonesia | YB | OI33JS | 4536
19 | 2021-11-06 | 12:53:29 | 1h:22m | 9M8DEN | -17 | FT8 | 20m | 14.0747 | East Malaysia | 9M6 | OJ51EM | 4401
21 | 2021-11-06 | 12:43:31 | 1h:32m | UC8S | -14 | FT8 | 20m | 14.0747 | Russia-EU | UA | LO63IS | 4327
73 | 2021-11-06 | 02:35:30 | 11h:40m | RV9WF | -17 | FT8 | 20m | 14.0747 | Russia-EU | UA | LO74UT | 4327
46 | 2021-11-06 | 12:02:29 | 2h:13m | YCØUCS | -19 | FT8 | 20m | 14.0746 | Indonesia | YB | OI33 | 4294
13 | 2021-11-06 | 12:58:30 | 1h:17m | VR2BG | -14 | FT8 | 20m | 14.0747 | Hong Kong | VR | OL72BI | 4199
50 | 2021-11-06 | 11:45:30 | 2h:30m | UN7LAP | -16 | FT8 | 20m | 14.0747 | Kazakhstan | UN | MO13TD | 3957
8 | 2021-11-06 | 13:17:30 | 58min | YC4AOK | -15 | FT8 | 20m | 14.0747 | Indonesia | YB | OI18SI | 3941
27 | 2021-11-06 | 12:38:30 | 1h:37m | 9M2CNC | -7 | FT8 | 20m | 14.0747 | West Malaysia | 9M2 | OJ03TB | 3471
64 | 2021-11-06 | 10:11:29 | 4h:04m | E21TMW | -5 | FT8 | - | 0.0000 | Thailand | HS | OK02SQ | 3024
57 | 2021-11-06 | 11:36:27 | 2h:39m | HS2AQG | -15 | FT8 | 20m | 14.0747 | Thailand | HS | OK02QP | 3008
40 | 2021-11-06 | 12:18:29 | 1h:57m | BG8TFC | -11 | FT8 | 20m | 14.0747 | China | BY | OL05SA | 2936
60 | 2021-11-06 | 11:04:15 | 3h:11m | HZ1SF | -10 | FT8 | 20m | 14.0747 | Saudi Arabia | HZ | LL34HT | 2907
72 | 2021-11-06 | 02:36:29 | 11h:39m | 9K2OD | -11 | FT8 | 20m | 14.0747 | Kuwait | 9K | LL49AI | 2890
12 | 2021-11-06 | 12:59:15 | 1h:16m | HS/F8UKP | -17 | FT8 | 20m | 14.0747 | Thailand | HS | OK03GR | 2889
36 | 2021-11-06 | 12:28:26 | 1h:47m | E2ØEHQ | -15 | FT8 | 20m | 14.0747 | Thailand | HS | OK03DT | 2861
75 | 2021-11-06 | 02:26:27 | 11h:49m | UN3G | -14 | FT8 | 20m | 14.0747 | Kazakhstan | UN | MN83JD | 2754
52 | 2021-11-06 | 11:40:28 | 2h:35m | EX8ABG | -15 | FT8 | 20m | 14.0747 | Kyrgyzstan | EX | MN72HT | 2705
31 | 2021-11-06 | 12:37:27 | 1h:38m | A65IN | -5 | FT8 | 20m | 14.0747 | United Arab Emirates | A6 | LL74HK | 2106
25 | 2021-11-06 | 12:41:27 | 1h:34m | A65DR | -13 | FT8 | 20m | 14.0748 | United Arab Emirates | A6 | LL75PB | 2060
70 | 2021-11-06 | 02:56:27 | 11h:19m | A65BR | -14 | FT8 | 20m | 14.0747 | United Arab Emirates | A6 | LL75SL88UN | 2050
7 | 2021-11-06 | 13:26:27 | 49min | 8Q7PR | -6 | FT8 | 20m | 14.0746 | Maldives | 8Q | MJ64SE | 1596
1 | 2021-11-06 | 14:10:26 | 5min | VU2MB | -7 | FT8 | 20m | 14.0747 | India | VU | ML88SM | 1171
28 | 2021-11-06 | 12:38:29 | 1h:37m | VU2RC | -4 | FT8 | 20m | 14.0747 | India | VU | MK82UV28FM | 744
68 | 2021-11-06 | 03:01:30 | 11h:14m | VU2MGS | -17 | FT8 | 20m | 14.0747 | India | VU | MK83UB | 728
77 | 2021-11-06 | 01:55:29 | 12h:20m | VU2GHO | -6 | FT8 | 20m | 14.0747 | India | VU | MK83UB | 728

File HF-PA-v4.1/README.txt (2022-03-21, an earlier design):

Note: HF-PA-v4.1 version is currently experimental, and under testing.

Changes:

- LPF circuit is included on the main PCB itself.

- 7805 is replaced with 7812. This way the BS170 driver stage gets more voltage
  to work with.

  Changes: Please ensure that the output of the BS170 stage does not exceed 20v (Vgs) / 1.5W.

Motivation: Improve the usability, and power output of the board.

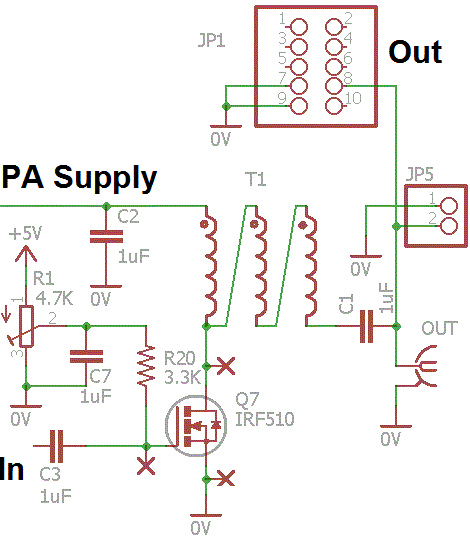
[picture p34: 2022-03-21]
Info/Simplified-PA-Schematic-2.png

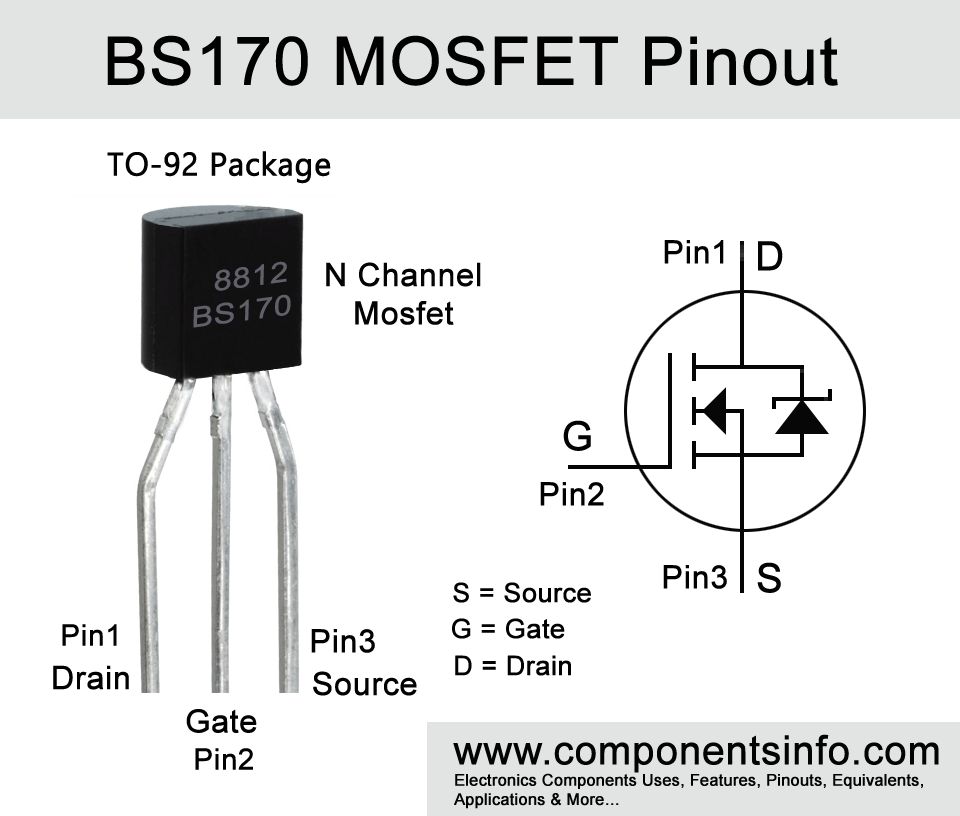
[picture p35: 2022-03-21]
Info/bs170-pinout-equivalent.gif

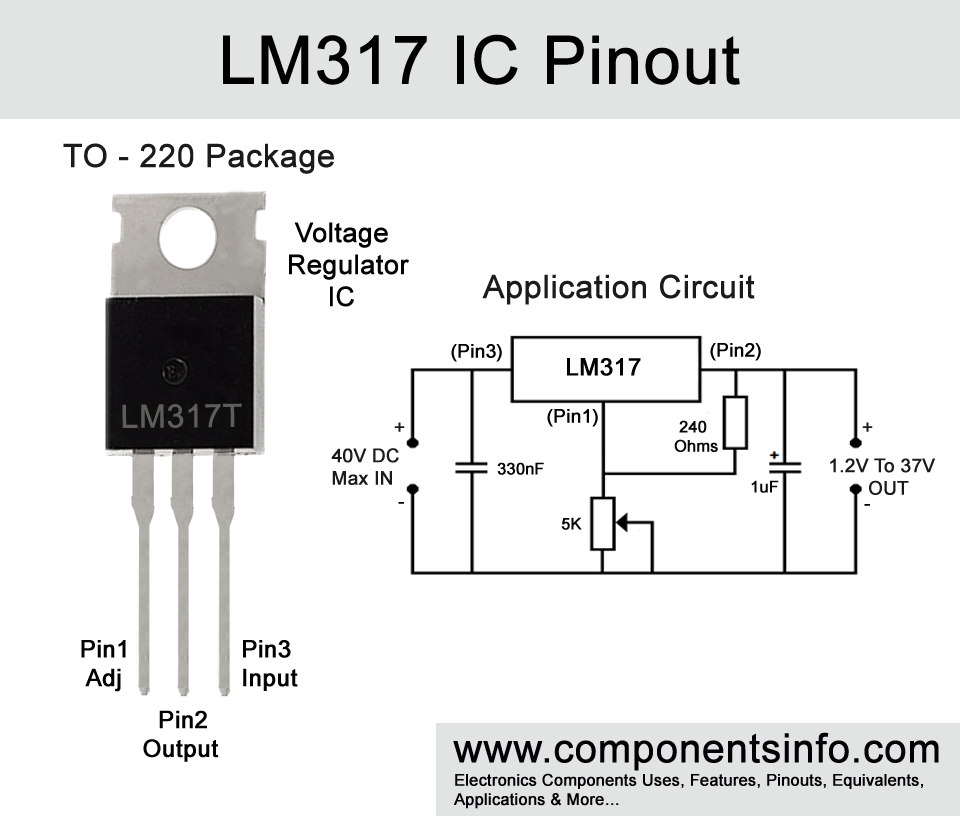
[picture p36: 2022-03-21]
Info/lm317-pinout-equivalent.gif

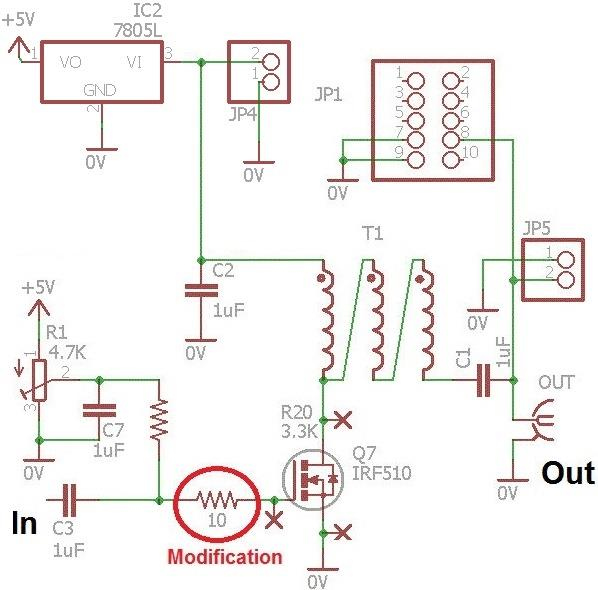
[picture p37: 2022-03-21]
Info/Simplified-PA-Schematic-1.png

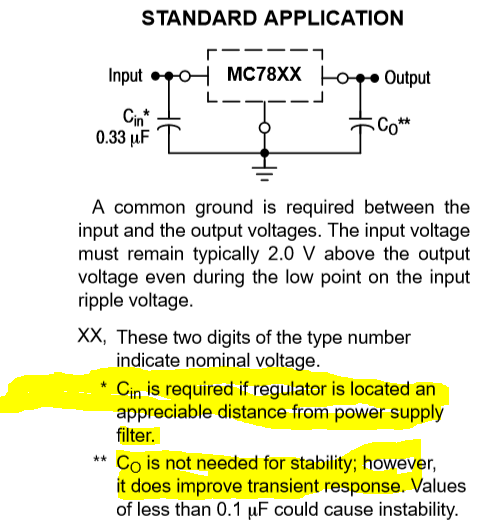
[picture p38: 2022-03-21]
datasheets/7805 Output Capacitor Requirement.png

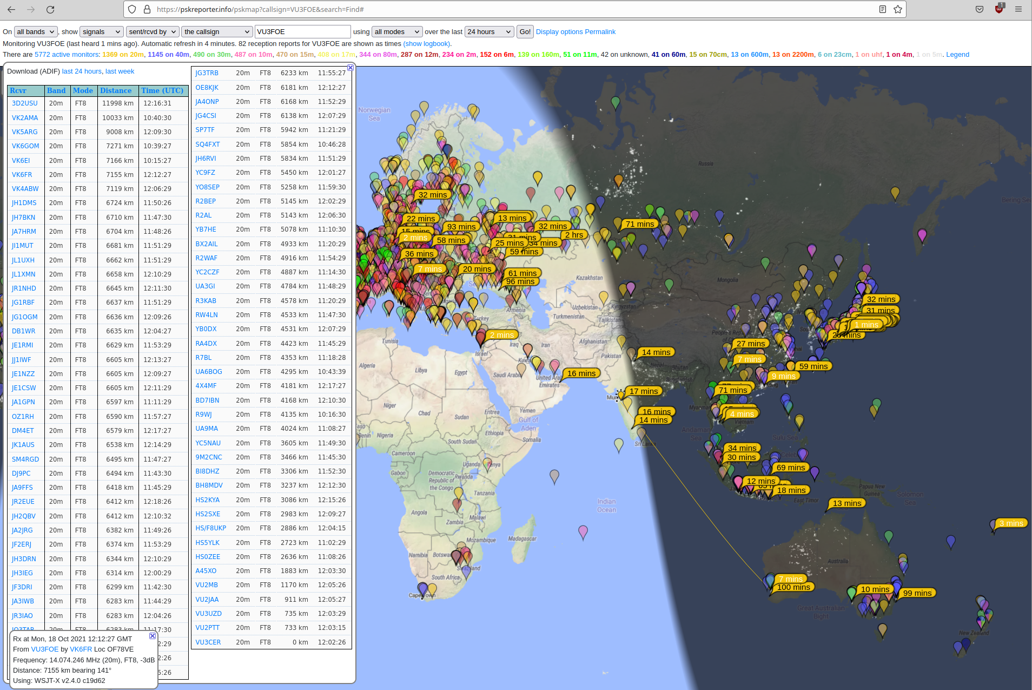
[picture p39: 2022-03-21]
RX-Reports/Screenshot_2021-10-18_17-50-11.png

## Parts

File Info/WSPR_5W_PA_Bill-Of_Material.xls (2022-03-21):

 | 5W PA for WSPR Ultimate
 | vk3pe | 2016-02-01
 | "0805-1206" means most footprints can be fitted, 0805 preffered though
Part Type | Designator | Footprint | Description | Notes
1.09uH | L1 | T50_TOROID | Inductor | for 30M band (refer to Ultimate web page for other band values)
1.09uH | L2 | T50_TOROID | Inductor | for 30M band (refer to Ultimate web page for other band values)
1.257uH | L3 | T50_TOROID | Inductor | for 30M band (refer to Ultimate web page for other band values)
270pF | C17 | 0805-1206 | Capacitor | for 30M band (refer to Ultimate web page for other band values)
270pF | C16 | 0805-1206 | Capacitor | for 30M band (refer to Ultimate web page for other band values)
560pF | C14 | 0805-1206 | Capacitor | for 30M band (refer to Ultimate web page for other band values)
560pF | C15 | 0805-1206 | Capacitor | for 30M band (refer to Ultimate web page for other band values)
100K | R5 | 0805-1206 | RES FIXED
100nF | C6 | 0805-1206 | Capacitor
100nF | C5 | 0805-1206 | Capacitor
100nF | C4 | 0805-1206 | Capacitor
100nF | C11 | 0805-1206 | Capacitor
100nF | C7 | 0805-1206 | Capacitor
100nF | C8 | 0805-1206 | Capacitor
100nF | C9 | 0805-1206 | Capacitor
100nF | C10 | 0805-1206 | Capacitor
100nF | C2 | 0805-1206 | Capacitor
100nF | C3 | 0805-1206 | Capacitor
10K | R3 | 0805-1206 | RES FIXED
10K | R2 | 0805-1206 | RES FIXED
10K | R4 | 0805-1206 | RES FIXED
10R | R7 | 0805-1206 | RES FIXED
10uF/16V | C12 | ccase | polarized cap
180R | R10 | 0805-1206 | RES FIXED
180R | R8 | 0805-1206 | RES FIXED
1K | RV1 | trim-pot | POTENTIOMETER
1N4001 | D1 | axial0.5 | Diode
1nF | C1 | 0805-1206 | Capacitor
22uF/16v | C13 | ccase | polarized cap
270R | R6 | 0805-1206 | RES FIXED
2N7000 | Q1 | TO-92B | FET
33R | R9 | 0805-1206 | RES FIXED
4K7 | R1 | 0805-1206 | RES FIXED
78L05 | U1 | to-92a | Regulator IC
BN43-202 | T1 | BALUN | balun core
NDT2955 | Q2 | SOT-223 | FET
RD16HHF1 | Q3 | TO-220 | FET

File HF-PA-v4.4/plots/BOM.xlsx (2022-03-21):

Designator | Manufacturer Part Number | Manufacturer | Description | Footprint | Quantity | Price per piece | Total price
C1 | - | Generic jellybean | 100nF 105 SMD 50V X7R 1206 10% (MLCC Cap) | SMD-1206-CAP | 0 | 3 | 0
J1 | SM05B-PASS-TBT(LF)(SN) OR SM05B-PASS-TB(LF)(SN) | JST | JST 5 pin Connector. JST PA series. | JST_SM05B-PASS-TBT_LF_SN_0 | 0 | 60 | 0
R1, R2 | - | Generic jellybean | Resistor SMD 4.7kΩ 5% 1206 | SMD-1206-RES | 0 | 2.5 | 0
R3 | - | Generic jellybean | Resistor SMD 820Ω 5% 1206 | SMD-1206-RES | 0 | 3 | 0
U1 | STM32G031J6 | STmicroelectronics | 8-Pin STM32 MCU | SO-8 | 1 | 120 | 120
L1 | - | Generic jellybean | SMD LED 1206 – choose your favorite color | SMD-1206-LED | 0 | 3 | 0
SWD1, DBG1 | - | Generic | 4x1 Male header strip 2.54mm pitch |  | 1 | 5 | 5
C1 [Optional Substitute] | - | Generic | 5x1 Male header strip 2mm, right-angle,L-type |  | 1 | 25 | 25
Copper clad PCB |  | Generic |  |  | 1 | 25 | 25
 |  |  |  |  |  |  | 175 | INR

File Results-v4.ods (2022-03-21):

Band | Voltage | Current Consumption | DC Power | RF Total Output | Efficiency | Comment
7 MHz | 13.8v | ~750mA | 10.45W | ~7W | 65.00% | Class-D operation with IRF510 in saturation!
14 MHZ | 13.8v | ~650mA | 9W | 5W | 55.00% | Class-D!
21 MHz | 13.8v | ~500mA | ~7W | 3.5W | ~50% | 3.5W is usable!
7 MHz | ~28v | ~1.3A | ~37W | 22W (what!?) | ~60% | Class-D OK!
14 MHZ | ~28v | ~800mA | ~23W | 14W | 60.00% | w00t!
21 MHz | ~28v | 800mA | 23W | 8W | 34.00% | Efficiency is not great but such is life with IRF510
21 MHz | 20v | 625mA | ~12.5W | 5W | 40.00% | Sweet spot for 21 MHz operations
RF output is 0W + power consumption is ~0W with no RF input. RF output doesn’t fluctuate. The amp seems to be quite stable.
BS170 Driver Output (No Load! 2mA drive from Si5351, 5v PA voltage)
7 MHz |  |  |  | 12Vpp++
14 MHZ |  |  |  | 8 to 11 Vpp
21 MHz |  |  |  | 5 to 7 Vpp
BS170 Driver Output (No Load! 8mA drive from Si5351, 12v PA voltage)
21 MHz |  |  |  | 24Vpp (w00t!)

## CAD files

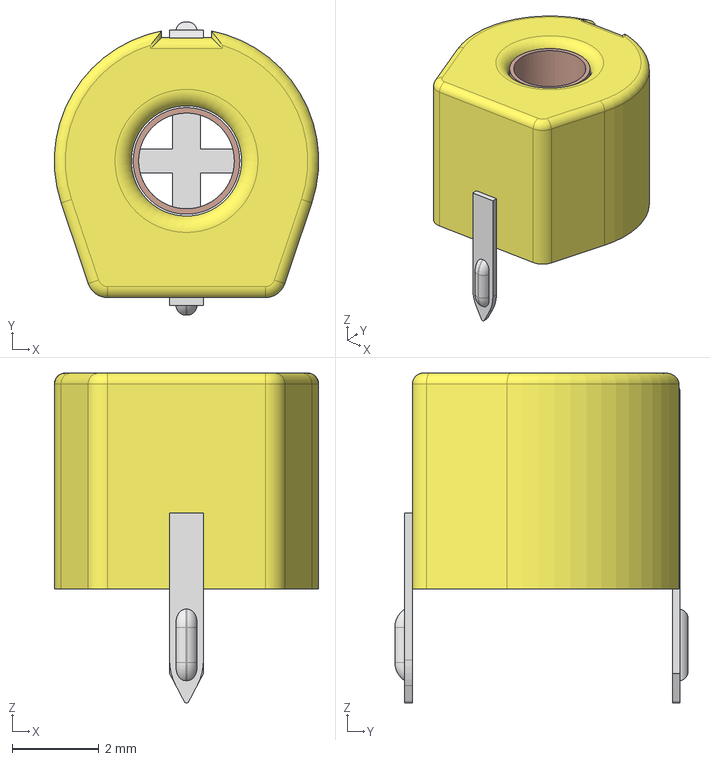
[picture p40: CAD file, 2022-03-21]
HF-PA-v4.4/models/Trimmer Cap - Yellow.stp
6.09 x 6.76 x 7.61 mm

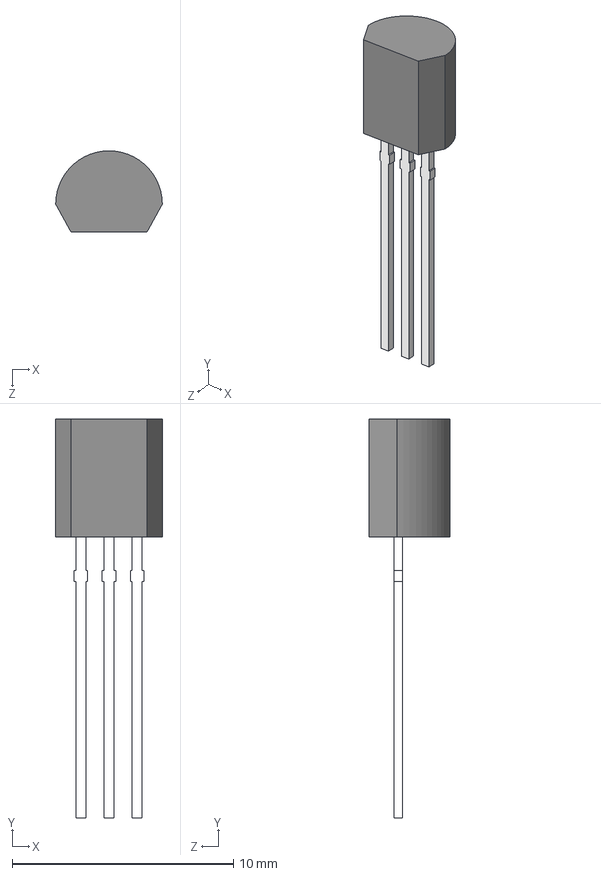
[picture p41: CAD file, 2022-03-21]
HF-PA-v4.4/models/LM78L05ACZ_NOPB.step
4.83 x 18.0 x 3.68 mm

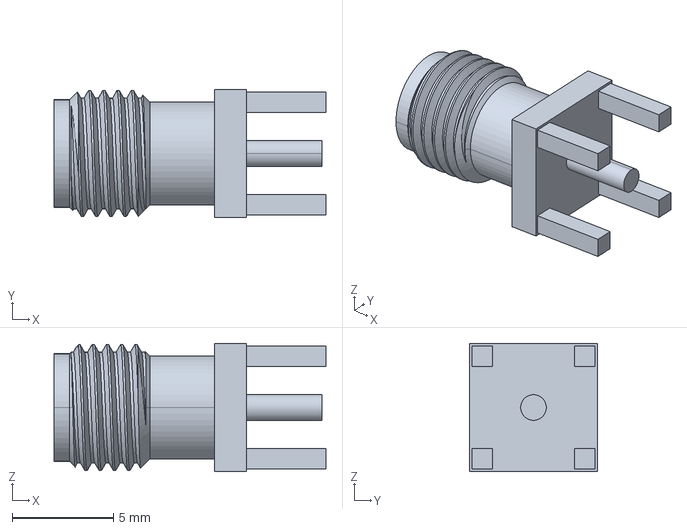
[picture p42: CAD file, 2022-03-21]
HF-PA-v4.4/models/901-144.stp
13.5 x 6.35 x 6.35 mm

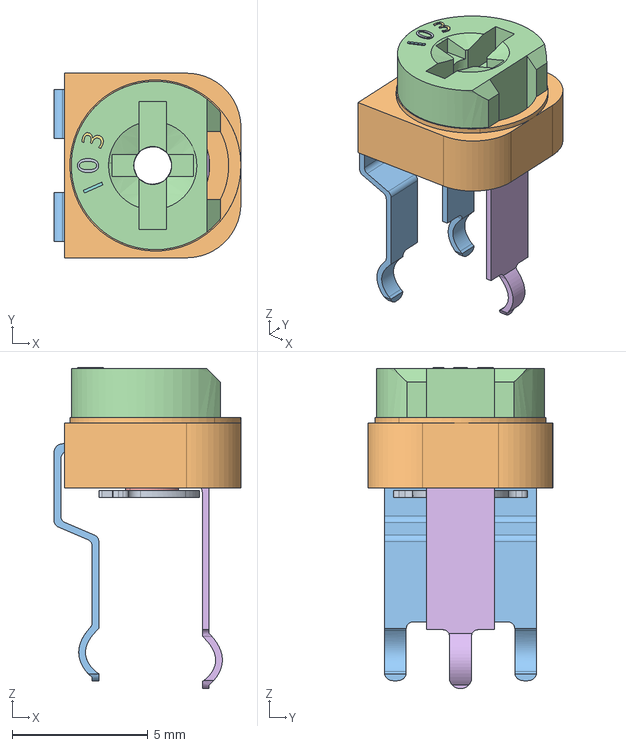
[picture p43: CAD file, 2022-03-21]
HF-PA-v4.4/models/Poti_10kohm.stp
6.88 x 6.80 x 11.8 mm

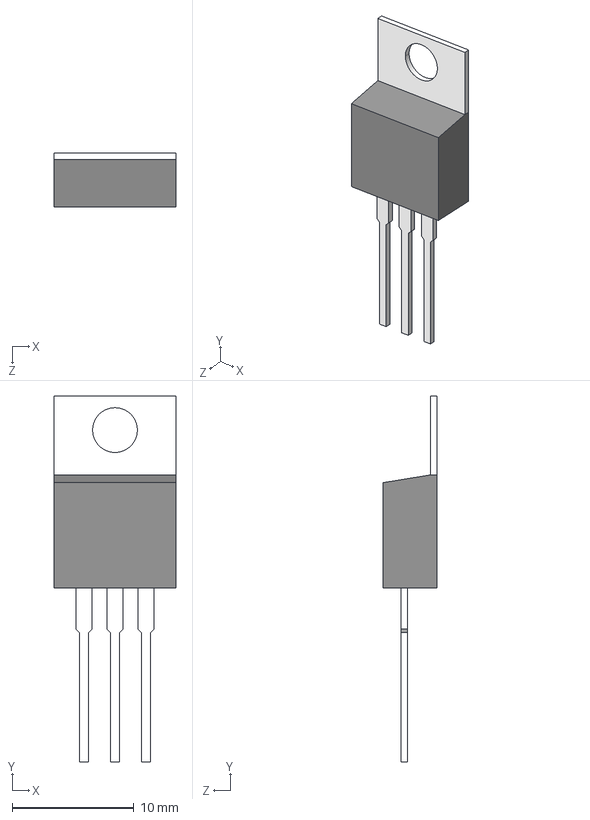
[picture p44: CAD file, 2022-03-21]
HF-PA-v4.4/models/LM7805CT_NOPB.step
9.97 x 30.0 x 4.44 mm

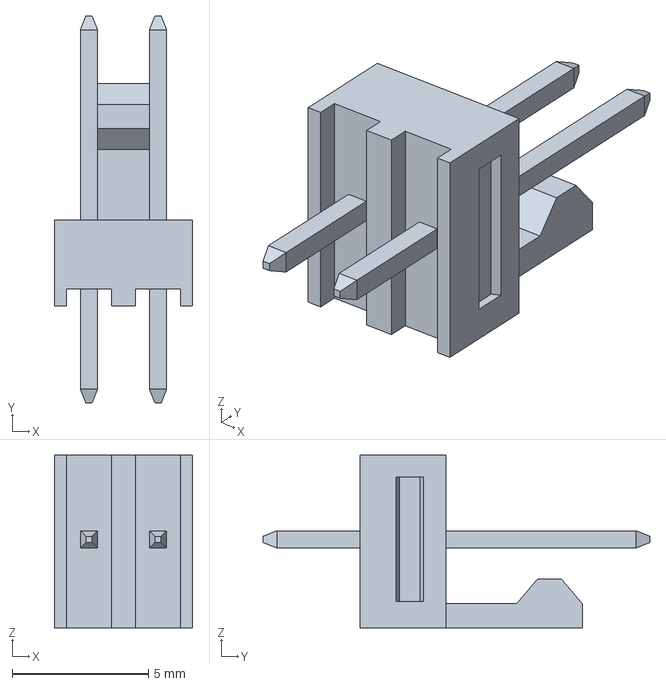
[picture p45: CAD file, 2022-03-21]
HF-PA-v4.4/models/22-23-2021.stp
5.08 x 14.2 x 6.35 mm

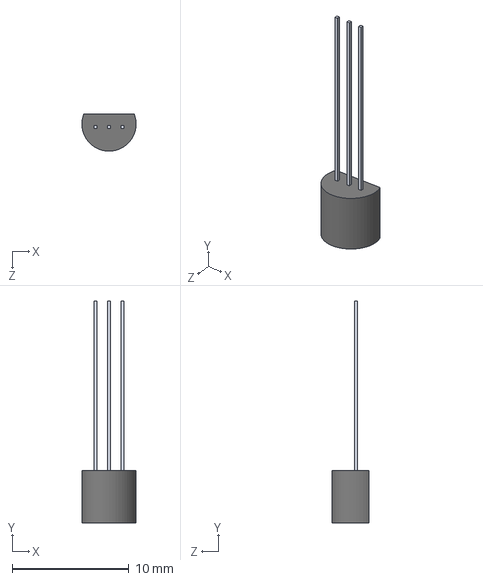
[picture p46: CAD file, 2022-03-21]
HF-PA-v4.4/models/Transistor_TO-92_Type.STEP
4.64 x 19.0 x 3.20 mm

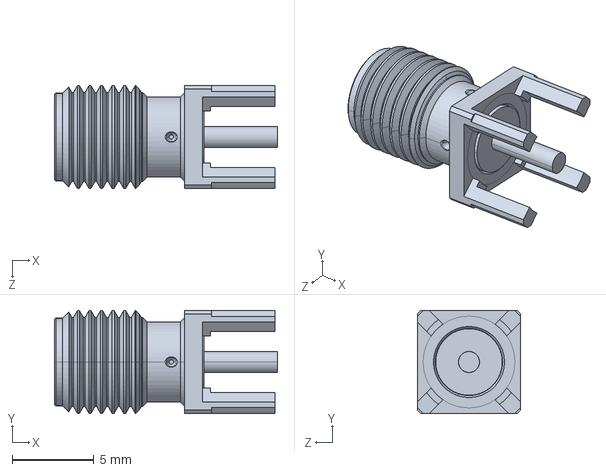
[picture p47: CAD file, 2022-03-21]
HF-PA-v4.4/models/R125.426.000 D.STEP
13.6 x 6.31 x 6.31 mm

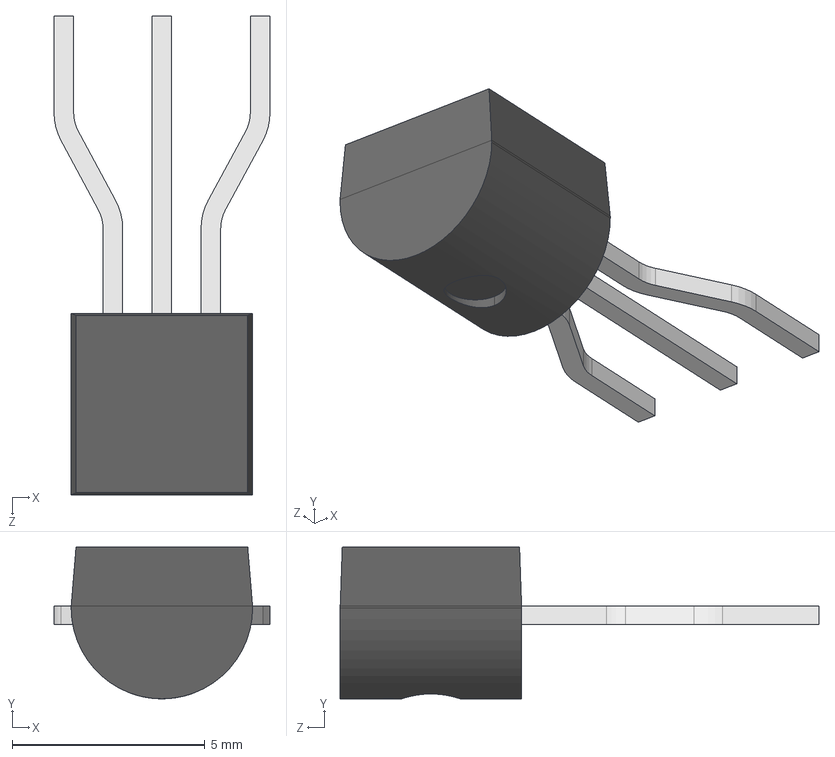
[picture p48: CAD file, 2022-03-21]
HF-PA-v4.4/models/User Library-TO-92-2_54-line.STEP
5.60 x 3.93 x 12.4 mm
User Library-TO-92 Version2_TO-92 Part1
User Library-TO-92 Version2_TO-92 Part3
User Library-TO-92 Version2_TO-92 Part4
User Library-TO-92 Version2_TO-92 Part5

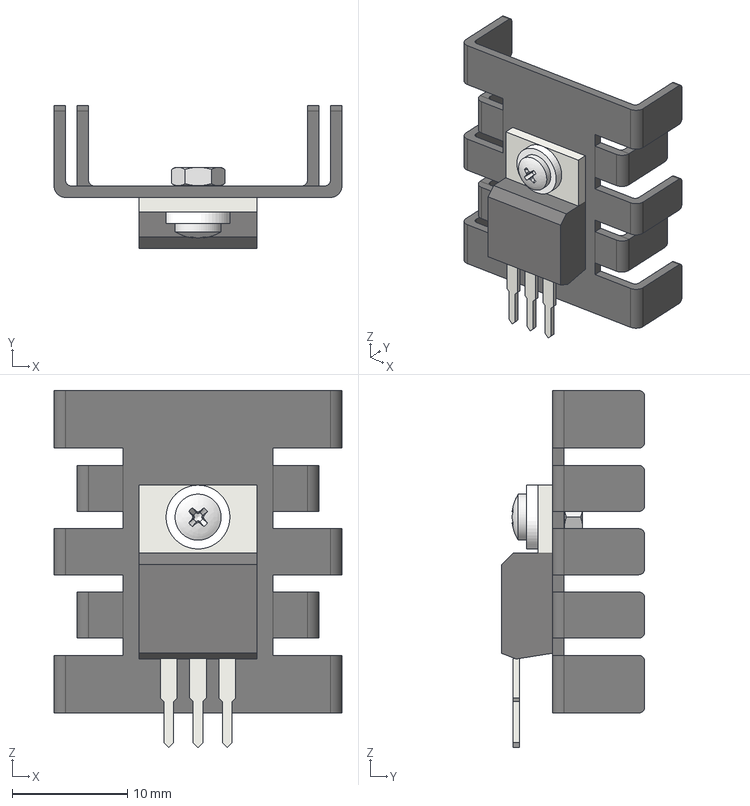
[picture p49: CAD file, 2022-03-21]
HF-PA-v4.4/models/Heatsink TO-220 28x25x8mm.stp
25.0 x 12.4 x 31.0 mm
TO-220_3_Vertical
Isolator
Screw
Nut
Heatsink_28x25x8mm

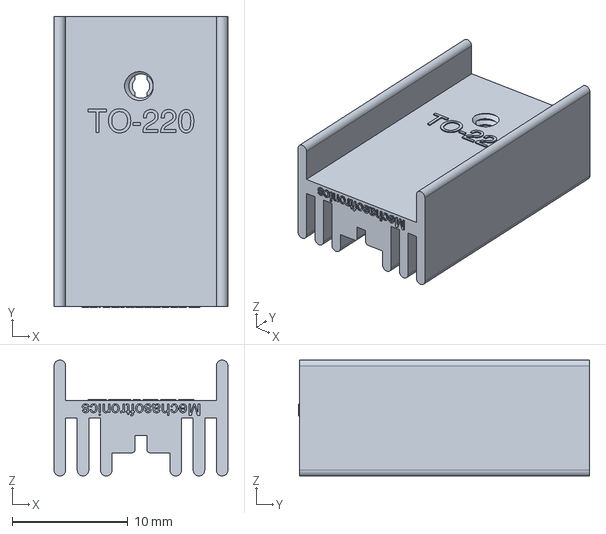
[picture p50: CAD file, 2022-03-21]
HF-PA-v4.4/models/heatsink_to-220.stp
15.0 x 25.1 x 10.0 mm

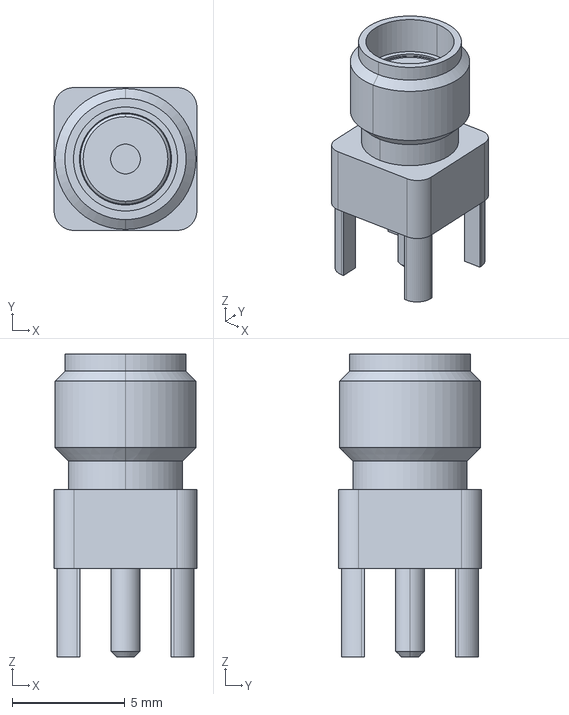
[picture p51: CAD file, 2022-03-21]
HF-PA-v4.4/models/c-221789-1-e-3d.stp
6.35 x 6.35 x 13.5 mm

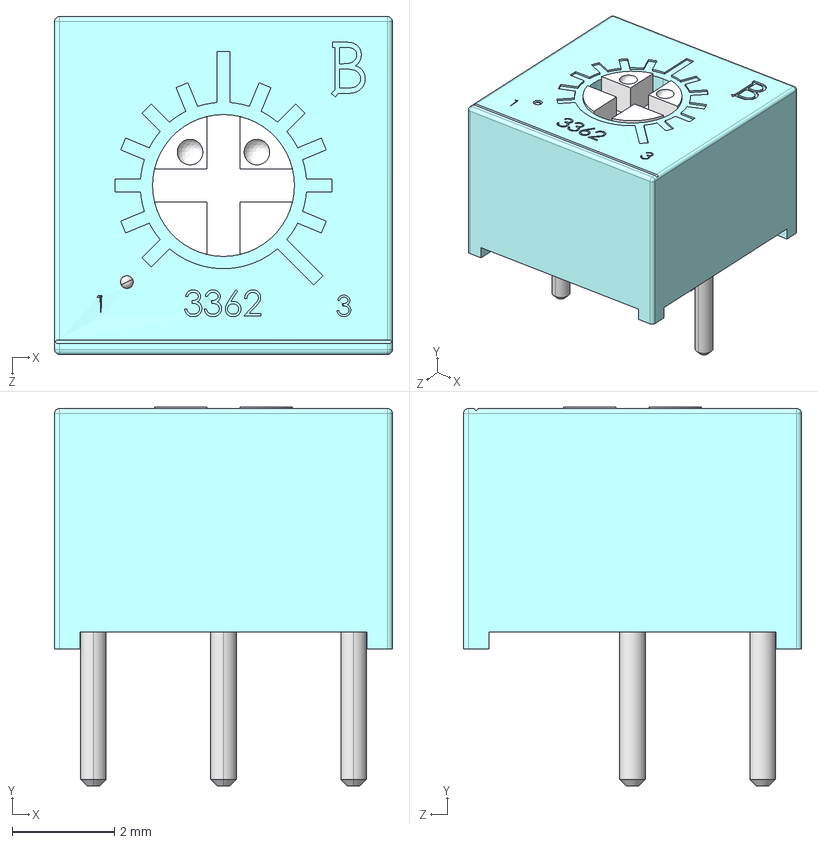
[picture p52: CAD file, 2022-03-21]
HF-PA-v4.4/models/3362P-1-102LF.STEP
6.60 x 7.40 x 6.60 mm

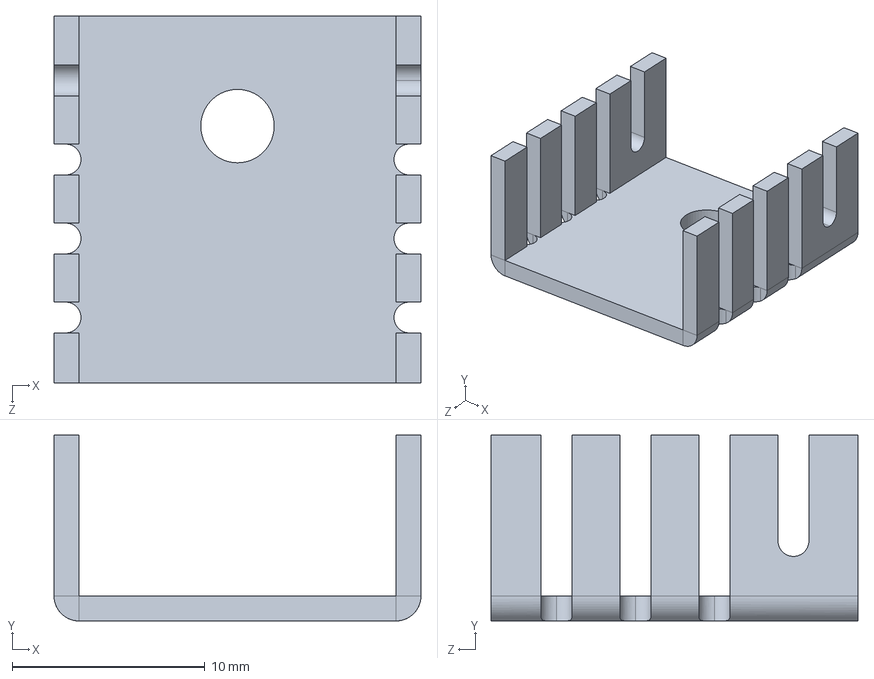
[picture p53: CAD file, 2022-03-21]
HF-PA-v4.4/models/577102B00000.STEP
19.1 x 9.65 x 19.1 mm

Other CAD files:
HF-PA-v4.4/models/Trimmer Cap - Green.stp
HF-PA-v4.1/models/Trimmer Cap - Green.stp
HF-PA-v4.2/models/Trimmer Cap - Green.stp
HF-PA-v4.3/models/Trimmer Cap - Green.stp
HF-PA-v4.OLD/models/Trimmer Cap - Green.stp

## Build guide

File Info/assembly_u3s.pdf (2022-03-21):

## Ultimate3S: Multi-mode QRSS/WSPR transmitter kit

## PCB Revision: “QCU Rev 1”

## 1. Introduction

Thank you for purchasing this QRP Labs kit. You will also plug in other modules. You need to download assembly instructions for those kits also. You will need the following assembly manuals:

- This Ultimate3S assembly manual
- Low Pass Filter kit (bands 2200m to 6m)
- Si5351A Synthesiser kit
- OCXO/Si5351A Synthesiser kit (if you will use this option)
- Relay-switched LPF kit (if you will use this option)
- QLG1 GPS receiver kit (if you will use this option)

Recommended approach to building the kit: This is a simple design but there are a large number of features which provide a great deal of flexibility. Read this WHOLE manual and understand it! Follow the construction section to build the kit.

This assembly manual must be read in conjunction with the operation manual!

## 2. Design

The ATmega328 AVR microcontroller (IC1) is pre-programmed with firmware to control the LCD, buttons, and GPS interface.

For best results, please ensure the use of a well-regulated, clean and solid 5V power supply. The majority of problems with the kits arise due to poor power supplies! Not all wall-wart type or switched mode supplies are clean enough to power the kit.

The PCB contains the microcontroller, Power Amplifier (PA) and connections to other boards and interfaces. The LCD module, Si5351A Synth module, Low Pass Filter module, Relay-switched LPF module all plug into this main PCB. The separate Si5351A Synthesiser module kit includes its own on-board 27MHz crystal reference oscillator.

On/off keying is handled in software by switching on/off the output stage of the Si5351A synthesiser IC. The Q1 BS170 MOSFET is the power amplifier, producing about 250mW from a 5V supply on 30m (power output varies on different bands). Finally standard 7-element low pass filter plug-in modules remove harmonics of the transmission frequency. The schematic diagram on the following page shows the Ultimate3S QRSS/WSPR transmitter.

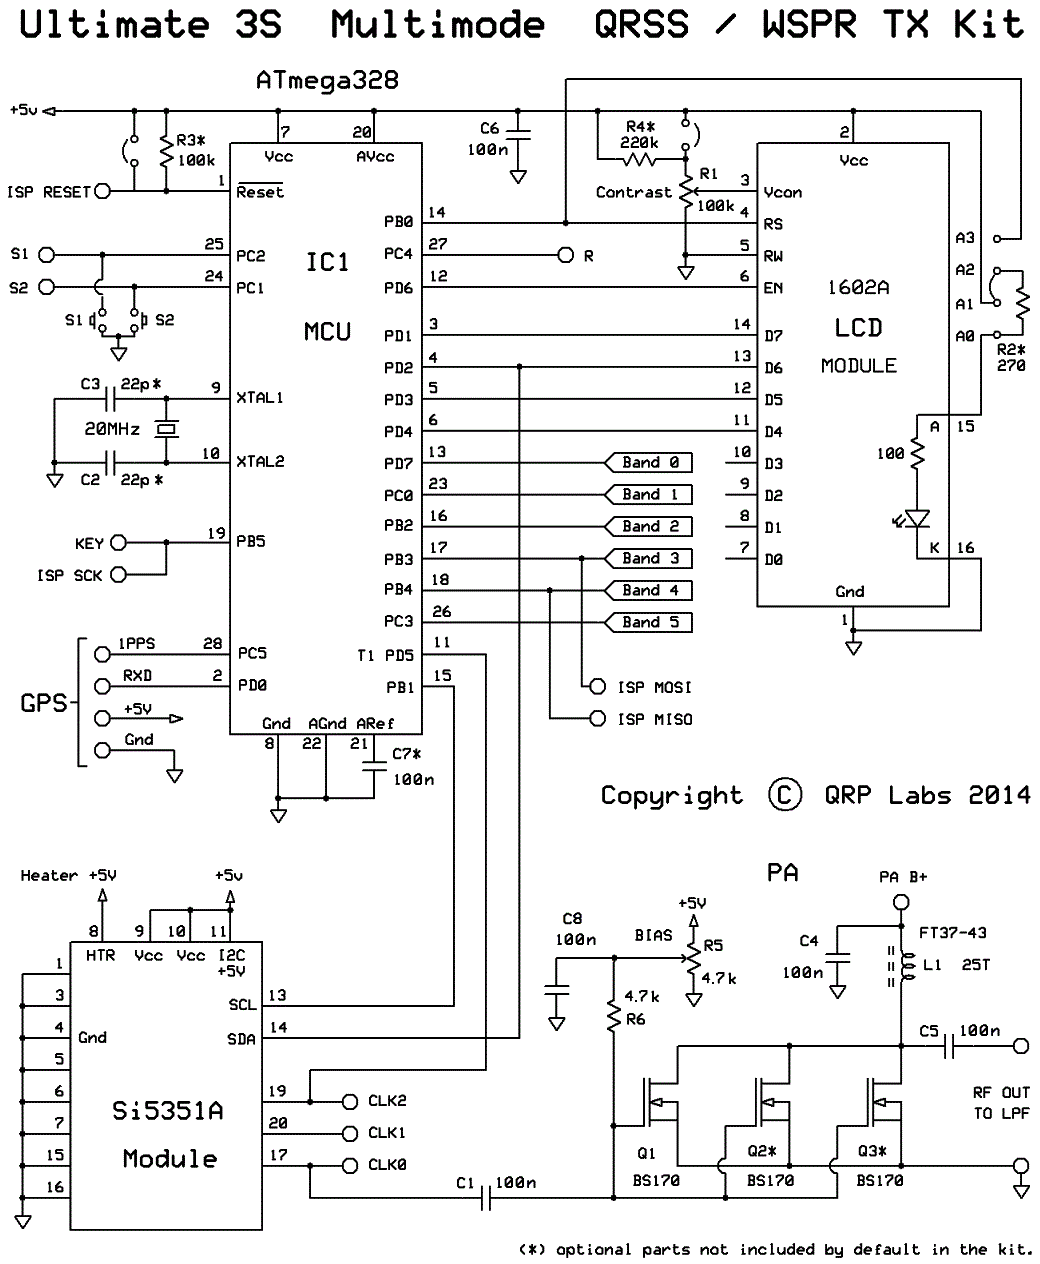
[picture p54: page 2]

## 3. Parts List

In the following parts list, components which are not supplied are shown in grey. They are optional, or supplied with other optional kits such as the relay-switched LPF kit, if you are going to use it.

### 3.1 Resistors

R1 | 100K preset potentiometer, for LCD contrast adjustment (code “104”)
R2 | No resistor – space is provided on the PCB only for reducing LCD backlight brightness
R3 | No resistor – space is provided for a 100K resistor, if you want to do AVR firmware upgrades
R4 | No resistor – space is provided for a 220K resistor, for smoother contrast adjustment
R5 | 4.7K preset potentiometer, for setting the PA bias (code “472”)
R6 | 4.7K resistor (colour coding yellow-purple-red-gold)

### 3.2 Capacitors

C2, 3 | No capacitor – space is provided for optional 22pF capacitors if required
C1,4,5,6,8 | 100nF (ceramic, marking 104)
C7 | No capacitor – optional, reduces noise when using analogue to digital conversion

### 3.3 Inductors

L1 | 25 turns, FT37-43 core (black)

### 3.4 Semiconductors

Q1, 2, 3 | BS170 (note: only one BS170 is provided in the kit, to be installed at the Q1 position.
| For use with higher PA supply voltages, more transistors may be added, i.e. Q2 and Q3).
D1 | No diode - provided for use with relay-switched LPF board kit
IC1 | Pre-programmed ATmega328 microcontroller

### 3.5 Miscellaneous

Two push buttons, S1 and S2
16-column x 2-row LCD (HD44780-compatible) with blue LED backlight Printed circuit board, 80 x 37mm size
Wire for winding toroid
Socket for IC1
20MHz quartz crystal
Two 10-pin female header sockets Two 4-pin female header sockets 16-pin female header socket
Two 16-pin male header plugs
Four 12mm nylon hex PCB spacers
Eight 6mm M3 screws
Relay RL0 – not supplied, provided for use with relay-switched LPF board kit

## 4. Construction

### 4.1 General construction tips

Parts placement is defined by the silkscreen printed legend on the PCB, so please observe it carefully, paying particular attention to the correct orientation of the semiconductors.

The PCB is quite small and the parts are close together. You are recommended to use a low wattage iron with a fine tip, and fine solder e.g. 1mm diameter or less. Take care not to overheat the PCB and risk damaging it. A well-lit area and magnifying glass are useful. Be careful not to bridge solder across closely packed connections. Some of the joints are very close to each other. I recommend checking with a DVM to make sure no solder bridges have been created.

Note that components D1, Q2, Q3, R2, R3, R4, C1, C2 and C7 are not required or supplied in the kit (R2 may be added by the builder if lower LCD backlight brightness is desired). Q2 and Q3 are not supplied, additional BS170 transistors may be installed here to increase the output power (see below).

IC1 (the microcontroller) has an IC socket, in case in future you wish to change the microcontroller e.g. for a firmware upgrade for new features, etc., or in case you wish to program it yourself. Sockets are provided for the synthesiser module and the low-pass-filter module, if applicable to your kit.

### 4.2 Construction steps

Please refer to the parts placement diagram below.

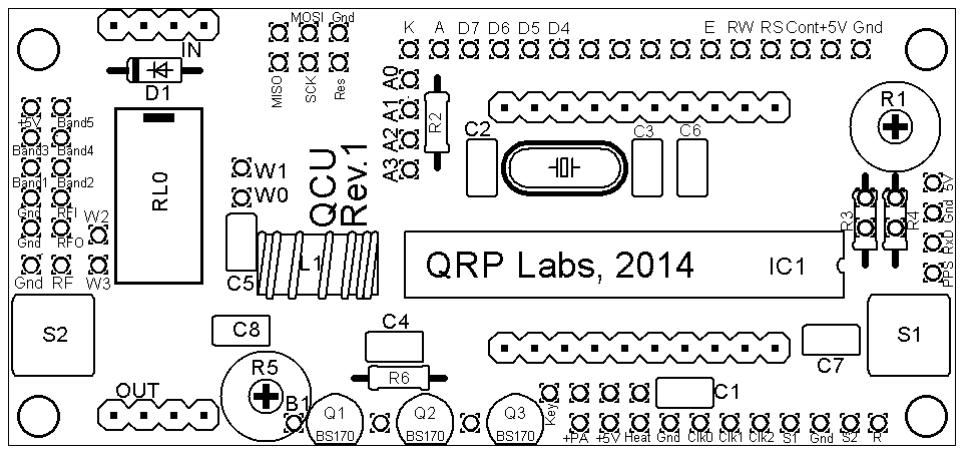
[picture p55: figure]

Pay special attention to the orientation of the semiconductors. For IC1, the dimple in the PCB silkscreen must be aligned with the dimple at the top of the IC socket and the IC.

The order of construction is not important. However, a good principle to follow is to install the smaller components first, so that the larger ones do not prevent easy access. One suggested order of construction is described below. I recommend following it carefully.

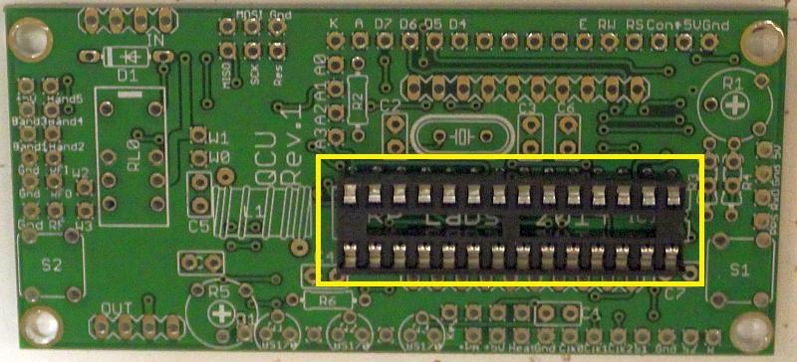
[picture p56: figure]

1) Solder in the socket for IC1.

To avoid confusion or mistakes later, align the dimple at one end of the socket, with the dimple illustrated on the PCB. The dimple should be at the end nearest the right-hand edge of the PCB.

2) Solder all capacitors, quartz crystal, and buttons S1/S2

There are five 100nF (0.1uF) capacitors. These are fitted in locations C1, C4, C5, C6, C8.

Note that the 22pF capacitors C2 and C3 either side of the crystal are NOT fitted – the 20MHz
crystal has been found to oscillate reliably without
them (there were some occasional issues when the

22pF capacitors were fitted). Therefore 22pF capacitors C2 and C3 are not supplied.

3) Wind and install the toroid

The silkscreen printing on the PCB shows vertical mounting of the toroid. If you prefer horizontal mounting, there is enough space for it. Please mount horizontally if you intend to use the OCXO/Si5351A Synth kit! When winding the toroid, remember that each time the wire goes through the centre of the toroid counts as one turn.
35cm of wire should be enough for 25 turns. Trim
the ends of the wire, scrape the enamel off and tin

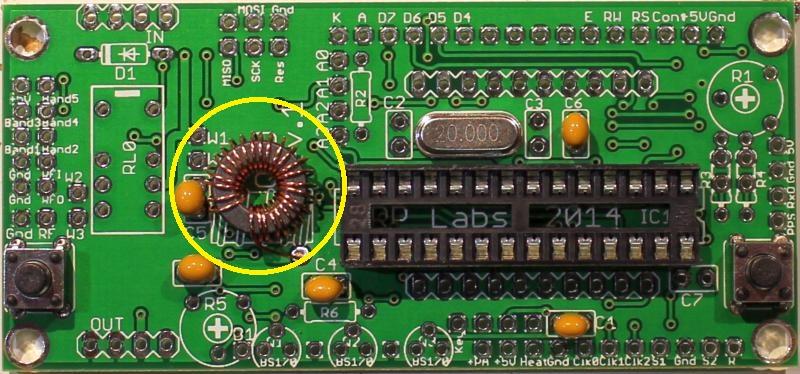
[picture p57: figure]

them with solder. As an alternative to scraping the enamel off, the wire ends may be held in a hot blob of solder on the iron tip for a few seconds, and the enamel will bubble away. Check continuity on the board with a DVM.

4) Solder the sockets for the low-pass-filter (LPF) module.

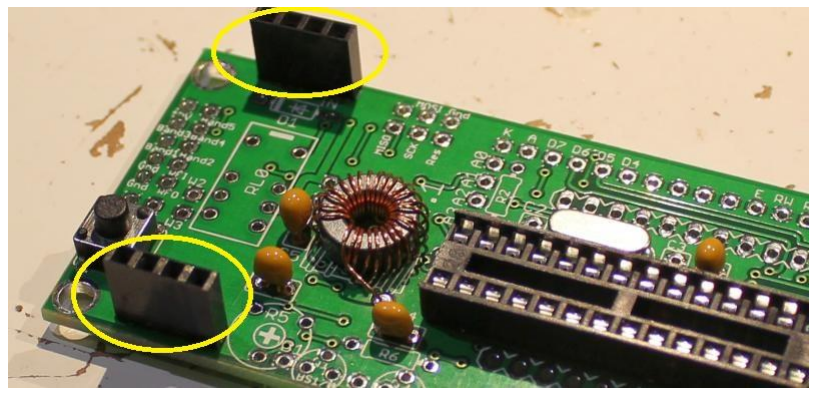
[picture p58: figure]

These are the two 4-way sockets. Some care
needs to be taken with the alignment, to ensure
that there is a good fit when the plug-in board is added. One method is to build the plug-in LPF module first; then plug it into the sockets. You can then solder the pins, ensuring correct alignment.

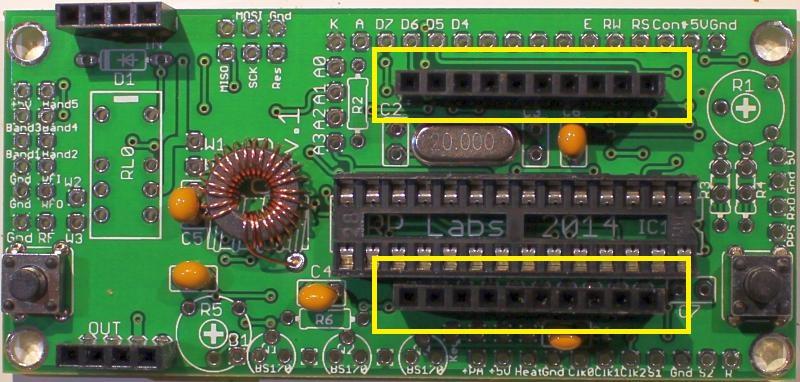
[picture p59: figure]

5) Solder the sockets for the Si5351A synthesiser module

These are the two 10-way sockets. Again take care of the alignment of the sockets, to ensure that there is a good fit when the plug-in board is added.

6) Fit and solder R1, the preset potentiometer that sets the LCD contrast.

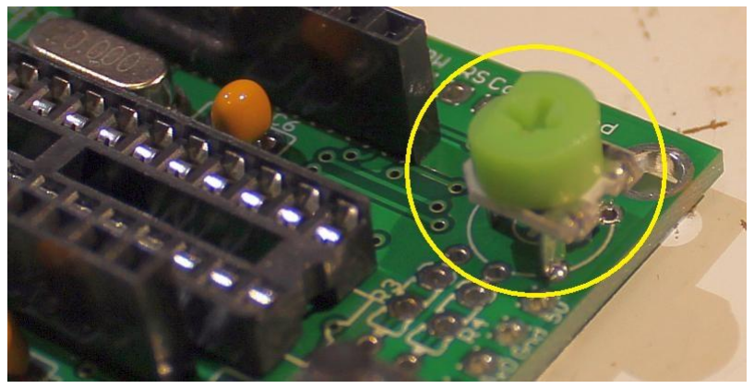
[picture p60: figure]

Be careful not to mix up the presets R1 (100K) and R5 (4.7K)! The code on R1 is “104”.

It is a slightly tight fit but apply pressure carefully and evenly, and the pins of the potentiometer will fit into the PCB perfectly.

Adjust this potentiometer to the fully clockwise position initially.

7) Fit and solder R5, the preset potentiometer that sets the PA bias.

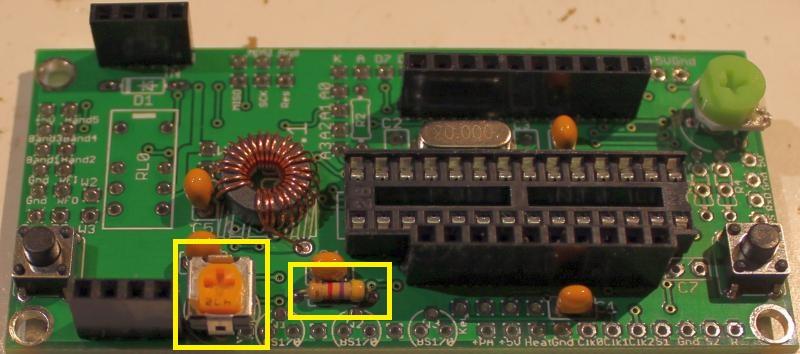
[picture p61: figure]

Also fit and solder the fixed 4.7K resistor R6. Be
careful not to mix up R1 and R5!

IMPORTANT: Turn the trimmer potentiometer all the way ANTI-clockwise, BEFORE applying power to the board. Please see section "PA bias set-up" below. The photograph (right) shows R5 in the mid position. In the correct completely ANTI-clockwise position, the “472” text will be to the right side, next to the Q1 position.

8) Solder wire jumpers as shown in the photograph and diagram below, depending on your requirements.

Typical jumper connections are shown in the photograph circled in yellow, and by red lines on the parts placement diagram below.

Please read the "Hardware options" sections
below, to decide which jumpers to fit.

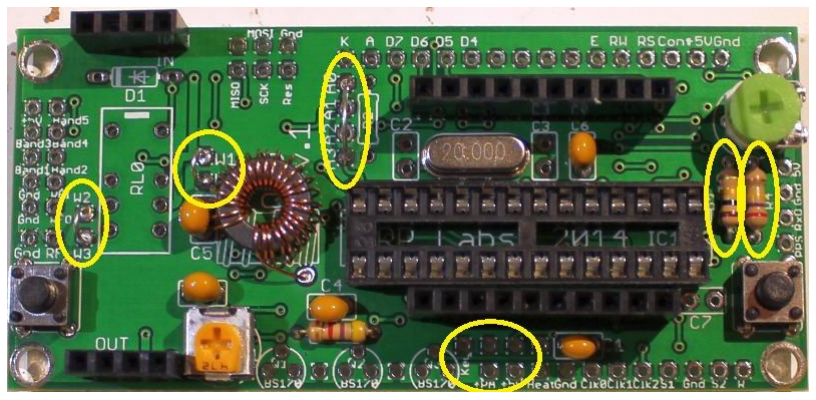
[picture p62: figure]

The wire jumpers can be made from offcuts from the other components e.g. capacitor leads. When installing these wire jumpers, I find it convenient to install them as a small semi-circular arch, perhaps 5mm high off the board. This is so that later, if they need to be removed (for different hardware options configuration), you can easily cut the links using wire cutters. It is easier than un-soldering them.

The W0-W1 and W2-W3 jumpers hard-wire the LPF into the circuit. Note that when a relay is fitted at RL0, you do NOT connect these two jumper wires. The relay is part of another kit, the relay-switched LPF board, which expands the capability of the Ultimate3S kit to sequence through up to 6 different bands.

If R2 is installed, in order to reduce LCD brightness, then connect A1-A2 instead of A0-A1 (see “hardware options” section below). You may decide to connect A0-A3 to use the software-implemented brightness control.

You may also install a jumper at the +PA and +5V connections at the bottom of the picture below, in order to power the power amplifier (PA) with the 5V supply. You should leave out this jumper if you intend to run the PA at a higher voltage. See more details in the “Hardware options” section below.

The "Heat" connection should be connected to +5V also, if you are using the OCXO version of the Si5351A module. It provides +5V to the oven heater, using a thick track on the PCB. This avoids voltage drop on narrow traces. If you are using the non-OCXO version of the Si5351A synthesiser module, then you do not need to connect the "Heat" connection.

Also pay attention to the jumpers at R3 and R4 on the right-hand side of the diagram. R3 is an optional resistor, to be fitted to enable in-circuit-programming for those wishing to update their own firmware and having the necessary equipment.

If you do not fit a 100K resistor for R3, then you must fit a wire jumper here as shown.

Resistor R4 is an optional resistor, which is in series with the top of the contrast adjustment potentiometer R1 and +5V. Typically the contrast voltage required is less than 1V and the adjustment is rather sensitive. If you wish, you can fit a 220K resistor in this position, which will make the contrast potentiometer less sensitive to adjust.

If you do not fit a 220K resistor for R4, then you must fit a wire jumper here as shown.

An example of typical jumper wire installations for basic operation of a single-band Ultimate3S QRSS/WSPR kit is shown in the following diagram.

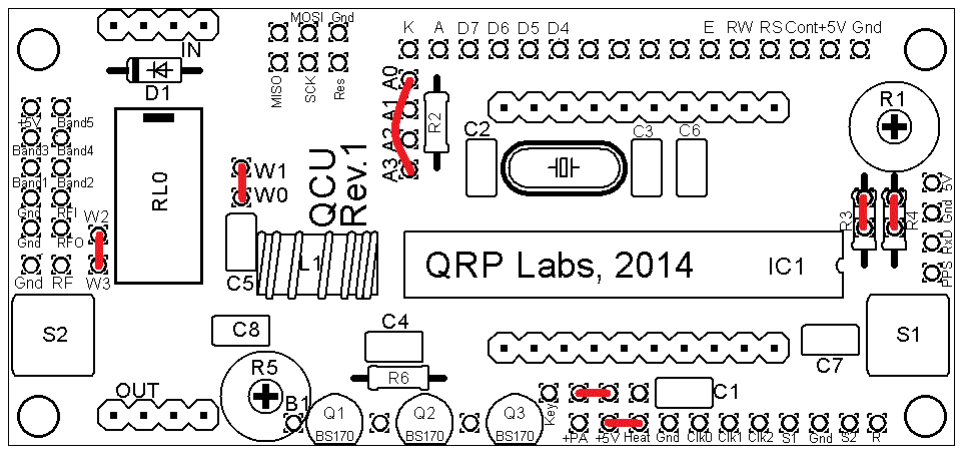
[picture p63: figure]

9) Solder in transistor Q1.

If you have purchased additional transistors for Q2 and Q3 to increase the power output, I still recommend starting with just the basic, single transistor, 5V PA supply setup. Get things working basically first, then later install the additional
transistors. Walk before you try to run!

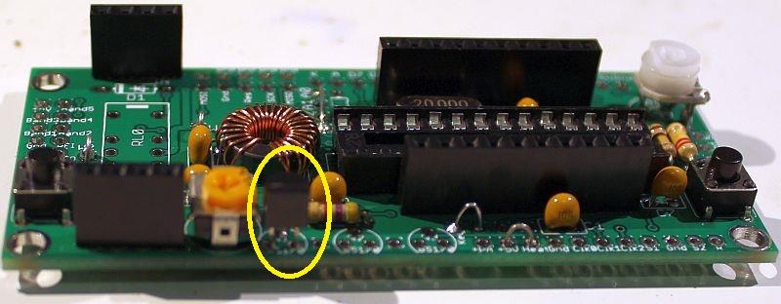
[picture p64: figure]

The transistors are located at the edge of the PCB with their flat side outwards. This is to allow easy attachment of a heatsink if desired (for higher voltage and hence higher power operation).

10) Install two 16-way connectors on the main PCB and LCD.

Install two 16-way connectors on the main PCB and LCD. Either way is fine, but my recommendation for installing the LCD connectors, is to use the female (socket) connector on the LCD side and the male (plug) on the PCB side.

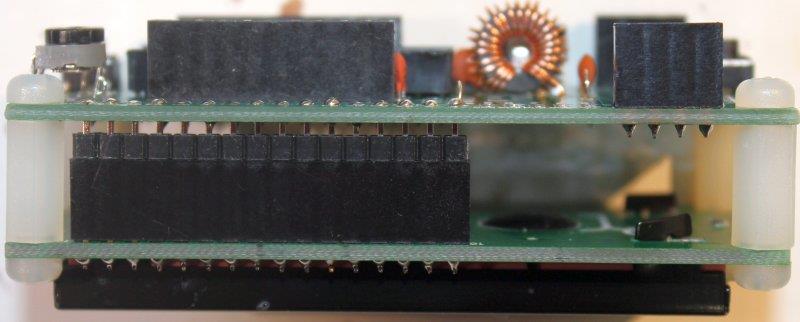
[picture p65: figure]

Be sure to solder the socket to the reverse of the
main U3S PCB!! Not the top side! It is very hard
to fix later, if you get this wrong!

Bolt together the LCD module and the PCB, with the 16-way connectors in place but not soldered. Then when you solder them, you will ensure perfect alignment. Use the eight 6mm M3 screws, and four 12mm nylon hex spacers, to bolt the PCB to the LCD.

The combined 16-way plug and socket when mated together, have a height of a little under 12mm. Therefore it is necessary to have a gap somewhere.

My suggested method is illustrated to the right here.
Closely mate the plug and socket. Leave the gap

between the male header (plug) and the PCB. I have found this method works successfully.

As you can see in the photo, the remaining pin length poking through to the component side of the PCB is short. However, the pins are still present in the holes and solder will fill the holes and connect to the pins.

At this stage, also solder the pins of the 16-way socket to the LCD module.

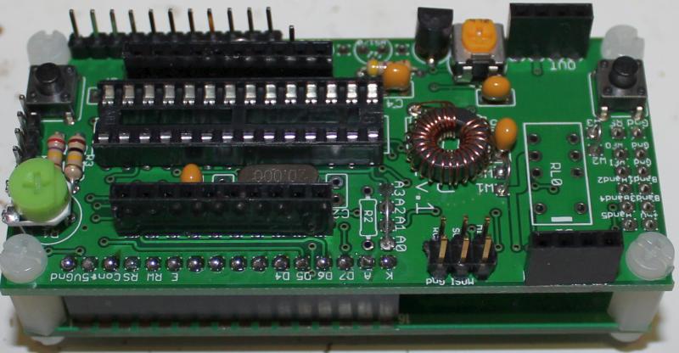
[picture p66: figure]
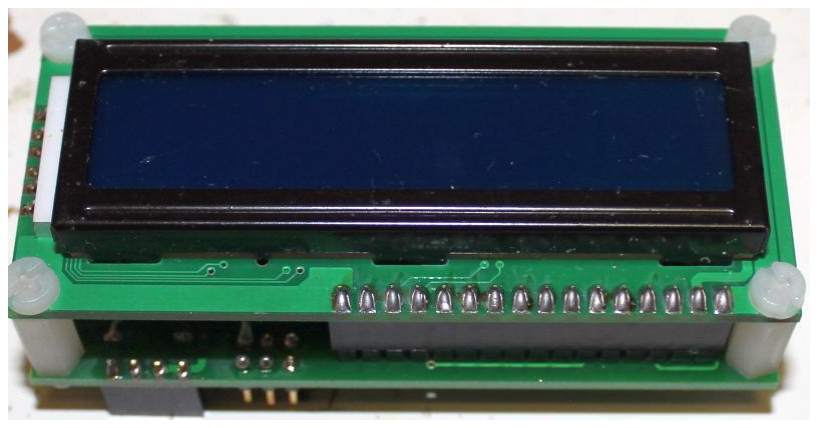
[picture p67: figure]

11) Optional header pins

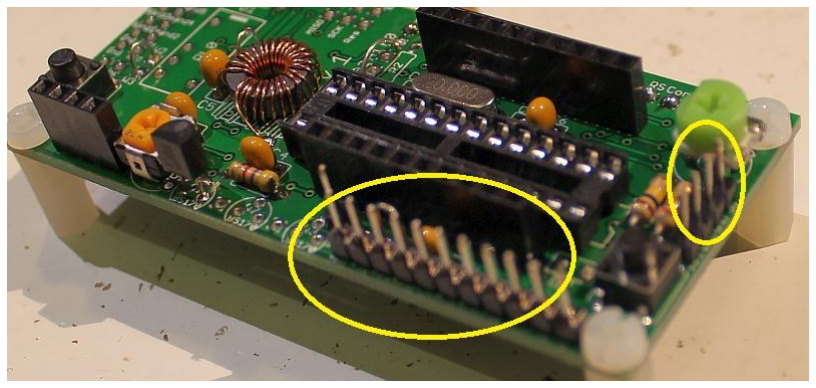
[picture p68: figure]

The kit is supplied with TWO of the 16-pin headers. Only one is needed for the connection to the LCD module. The other is supplied so that if you wish, you can solder it to the PCB and use it for more convenient connections to the kit. You can either solder directly to the pins, or use the appropriate connector.

The 16-pin header strip can easily be snapped into smaller pieces. In the photograph (right) I have broken off a 4-pin section to use for the GPS connector, and installed an 11-pin section along the board edge. The final pin was installed in the “Key” connection pad.

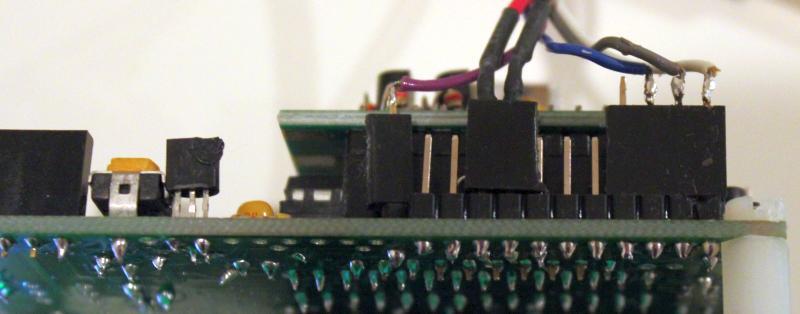
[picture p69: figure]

The photograph (right) shows an example of making connections to this header.

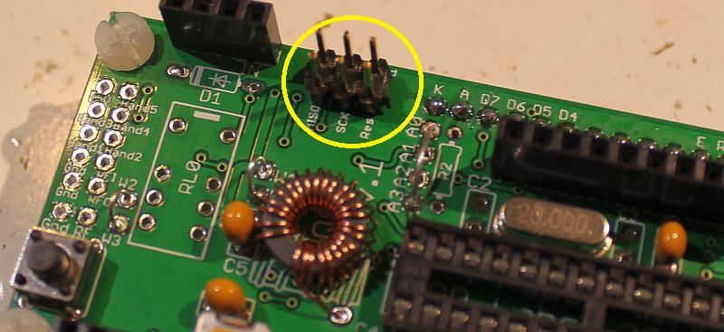
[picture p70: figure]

12) Optional In-circuit programming header

The QCU kit has provision for installing a standard Atmel 3 x 2 header (not supplied), for in-circuit programming of IC1 the ATmega328 processor.

This option is useful if you want to use one of the many inexpensive AVR programmers to upgrade the kit firmware, when updates are published by QRP Labs.

### 4.3 Module assembly

First the microcontroller IC1 should be inserted in its socket. Be sure to align the microcontroller chip correctly. The dimple on the chip must be at the same end as the dimple on the socket, and the dimple on the silkscreen legend on the PCB.

Next, plug together in the other modules (LPF, Si5351A Synth). These pictures show the U3S PCB Revision 1, but the module assembly is the same.

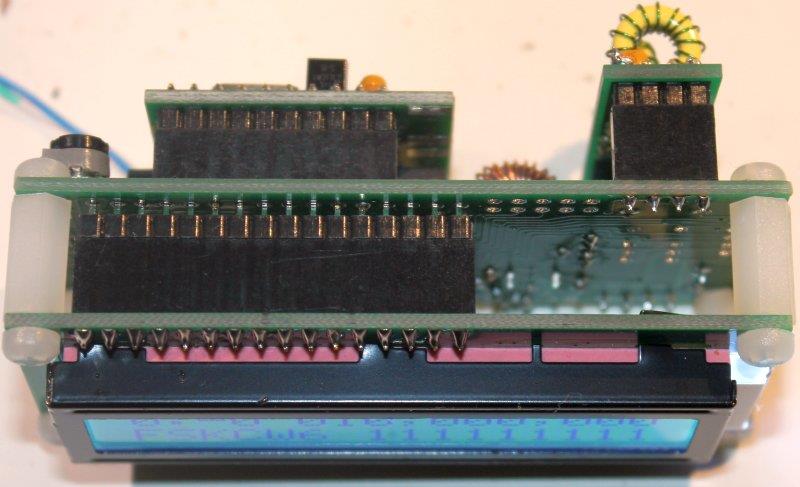
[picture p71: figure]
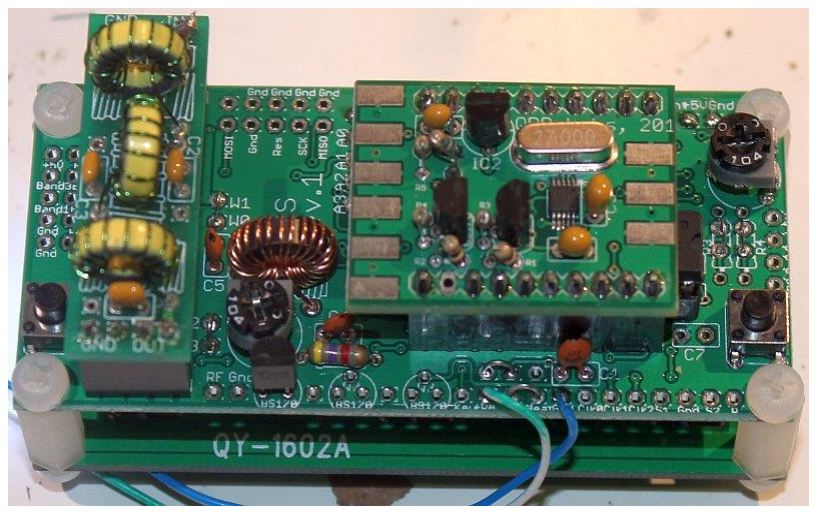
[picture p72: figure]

Ensure that the Si5351A synthesiser module is inserted the correct way round as shown in the photograph. The Low Pass Filter kit module should be plugged in with the “Out” legend aligned next to the RF Output connector of the main PCB (see photo).

Important! Upon power-up, you will need to adjust the contrast potentiometer R1 to view the LCD properly. Turn it fully clockwise to start with (before applying power). Then turn it gradually anticlockwise until the displayed text looks correct.

The series of photographs below show the display with a) fully clockwise; b) fully anti-clockwise; c) adjusted perfectly. When adjusted perfectly, you will see "Diagnostic Mode" message on the screen.

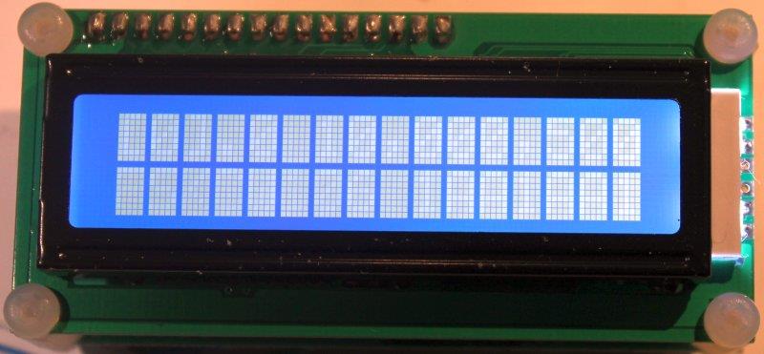
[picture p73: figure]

When you see "Diagnostic Mode" it means all is well with the

processor and the LCD communication. When you press the left button, diagnostic mode will be cleared. Then you should see the splash screen, which shows the firmware type and version number.

If you cannot see any text on the screen even after
adjusting the contrast setting, you have a problem. Please
refer to the "Troubleshooting" page on the QRP Labs website (see resources section below).

## 5. Hardware Options

### 5.1 Explanation of connections

The table to the right details the purpose of the connection points around the right-hand and bottom edges of the PCB.

The pin-spacing is 0.1-inches and a suitable connector could be used (see section above).

These connections are further described in the following sections.

Note that the cluster of connections at the left board edge are for fitting the connector to the relay-switched LPF board kit. They
can be ignored for now.

Connections A0, A1, A2 and A3 allow options concerning the LCD backlight, as described below. Typically you should connect A0 and A3, this enables the software controlled backlight control.

### 5.2 Connection for basic operation

For the most basic operation of this kit as QRSS/WSPR transmitter using 5V supply, it needs only a power supply and RF output connection. To allow use of a higher voltage supply for the PA, there are separate connections for the PA voltage and +5V supply. To run the transmitter using the 5V supply, be sure to connect a wire between the +5V and PA pins. This is shown by the short red horizontal line in the diagram (below).

The "Heat" connection is only required if you are using the OCXO version of the Si5351A synthesiser module. You must connect it to +5V to power the oven heater.

Label | Group | Description
5V | GPS | +5V supply to GPS module
Gnd | GPS | Ground connection to GPS module
RxD | GPS | Serial data input from GPS module
Pps | GPS | 1 pulse per second input from GPS module
R | Future | No connection – for future enhancements
S2 | Buttons | Optional external button S2, switch to Gnd
Gnd | Buttons | Ground for optional external buttons
S1 | Buttons | Optional external button S1, switch to Gnd
Clk2 | Signal | Clk2 Si5351A output, 3.3V p-p squarewave
Clk1 | Signal | Clk1 Si5351A output, 3.3V p-p squarewave
Clk0 | Signal | Clk0 Si5351A output, 3.3V p-p squarewave
Gnd | Power | Ground connection to Power supply
Heat | Power | +5V heater for OCXO/Si5351A module option
+5V | Power | +5V power supply
+PA | Power | PA power supply – may be connected to +5V
Key | Control | “Keying” output: high during transmit
Gnd | RF | Ground for RF output
RF | RF | RF output

### 5.3 Alternative button mounting option

You may use an external pair of buttons to control the kit. The button input signals are available at the edge of the board, labelled S1 (left button) and S2 (right button). The buttons should be of the push-to-make variety. The left button should be connected between the S1 signal and ground; similarly the right button should be connected between the S2 signal and ground. Suitable buttons are supplied in the official QRP Labs U3 Case and accessories kit.

### 5.4 Optional connection of GPS module

A GPS module may be connected to the kit, to provide frequency stability, accurate time, and latitude and longitude which can be converted to Maidenhead locator format for encoding in the WSPR message transmission.

Check that your module is powered from 5V. Many modules specify a 3.3V supply - in this case you will need to provide an external 3.3V voltage regulator. Some GPS modules may need a pull-up resistor however.

The QRP Labs QLG1 GPS receiver module kit is powered from 5V and
does not require pull-up resistors. It is suitable for direct connection to the Ultimate3S kit.

In cases where the location information is not required (modes other than WSPR) or you wish to enter it manually, the serial data input can be left unconnected. The 1 pps input is enough for the frequency lock function. A 1pps signal could be supplied from a non-GPS source, such as a laboratory frequency standard. Note that the frequency locking function can only operate if you have selected a wait period between message transmission (i.e. a non-zero “Frame” parameter).

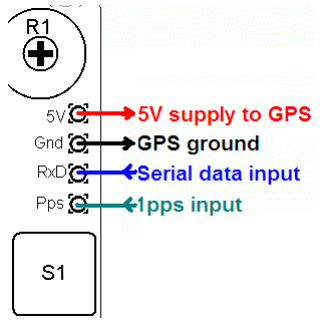
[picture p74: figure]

See operation instructions for details on how to configure the GPS interface.

### 5.5 Higher power output

The PA in the kit provides around 250mW of output power using a 5V supply and a single BS170 transistor (depending on the band). The transistor gets warm to the touch. If higher output powers are desired, this can be achieved by using a higher supply voltage for the Power Amplifier (PA). The microcontroller must still be run at a voltage not
exceeding its 5.5V rating (5V is recommended). To
facilitate running the PA at higher voltages to

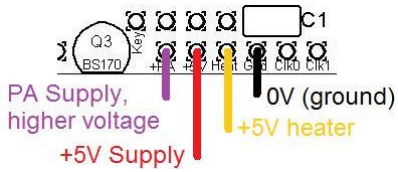
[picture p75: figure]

provide more power, the PA supply connection is a separate pin.

At higher supply voltages and power outputs, the heat dissipation in the BS170 will increase and its temperature will be higher. Provision is made on the PCB for two more transistors in parallel with the first. This will slightly increase the power output even at 5V supply, but more importantly at higher voltages it should share the heat dissipation between the devices.

It may be necessary to fix a heat sink to the transistors if the temperature rise is excessive. The transistors are located near the edge to the board to allow a heatsink. Experiment is needed in this area, with PA voltages up to perhaps 12V.

### 5.6 LCD backlight options

a) Full brightness: For basic operation connect A0 to A1 using a wire jumper (made from a capacitor lead offcut, for example). The blue LED backlight of the LCD module will be at full brightness. This is shown as the Red line (left). In this case, do not fit any resistor at the R2 position.
b) Reduced brightness: You may find the LED backlight of the LCD module too bright for your liking, or if you wish to operate from battery power, perhaps you consider that it consumes too much current. In that case, fit a wire jumper between A1 and A2, and use a suitable valued resistor at the R2 position: experiment, e.g. starting at 100-ohms. 180-ohms has been reported to work well. 220-ohms or 270-ohms may also suit your taste.
c) Software variable brightness: The U3 firmware contains a "Backlight" configuration setting which can be set from 0 (backlight OFF) to 9 (maximum brightness). This is achieved using pulse width modulation. To enable this setting, you must connect A0 to A3 using a wire jumper (do not fit any resistor at the R2 position).
d) Switched backlight: If you do not wish the LCD module's LED backlight to be on all the time, then instead of the wire jumper, you could connect wires to an on/off switch. This could be useful for battery powered operation, to reduce current consumption. For example, you could switch the display on to set up the kit, then leave it switched off during operation. The official QRP Labs U3 Case and accessories kit includes a spare switch which could be used for this purpose.

### 5.7 Si5351A outputs

For possible use in other projects, the connection points labelled Clk0, Clk1 and Clk2 provide direct connection to the Si5351A module's outputs. They are 50-ohm impedance and provide up to a 3.3V peak-peak squarewave. Actual peak-peak amplitude may be less than this (worst case 2.1V p-p), particularly at higher frequencies – please refer to the Si5351A datasheet. Do not draw excessive loads from these connections.

### 5.8 In-circuit programming of AVR

If you own an AVR programmer, you can make connections to the QCU PCB to allow updating the firmware without removing the AVR chip.

In this case, you should fit a 100K resistor as R3, not a jumper link. This is shown enclosed in RED on the right side of the below diagram. The other connections required to your programmer, are MISO, MOSI, SCK and Res (reset), these are indicated in the RED square on the diagram. The connection layout is designed to fit a 2 x 3-pin header, to match common AVR programmer cables. Before use, you should check that the connections match your programmer, because there are several standards in use. This board is designed to be as flexible as possible.

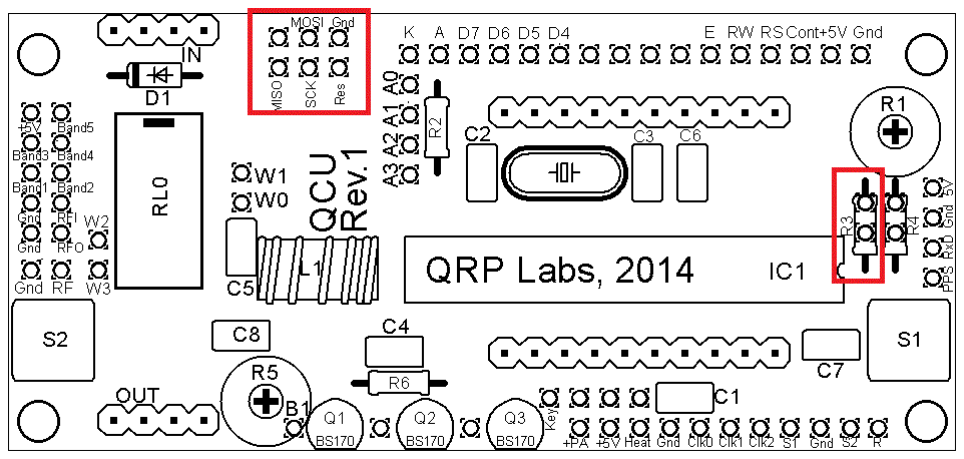
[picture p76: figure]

Notes:

1) Power needs to be applied to the kit during programming! When you start programming, whatever the processor is doing at that moment will be interrupted.
2) Some constructors have reported that if the relay-switched LPF board is fitted, the relays chatter because the programming lines are shared with relays 3 and 4, and programming errors. If this happens with YOUR programmer, you need to either remove the relay board during programming, or cut the wires to relays 3 and 4 and put a DPST switch in, to disconnect them when required.
3) Some programmers require a connection to sense the voltage level of the target processor. They do this on the 6th header pin (the top right of the 3 x 2 matrix in the picture above). On this QCU PCB, this pin is not connected. If your controller needs to sense the board voltage on this pin, then you need to wire a connection from this pin to +5V. A convenient (and nearby) place to do this is the cathode of the D1 diode. This connection is shown by the purple wire in the below diagram. The wire should be soldered on the underside of the PCB.

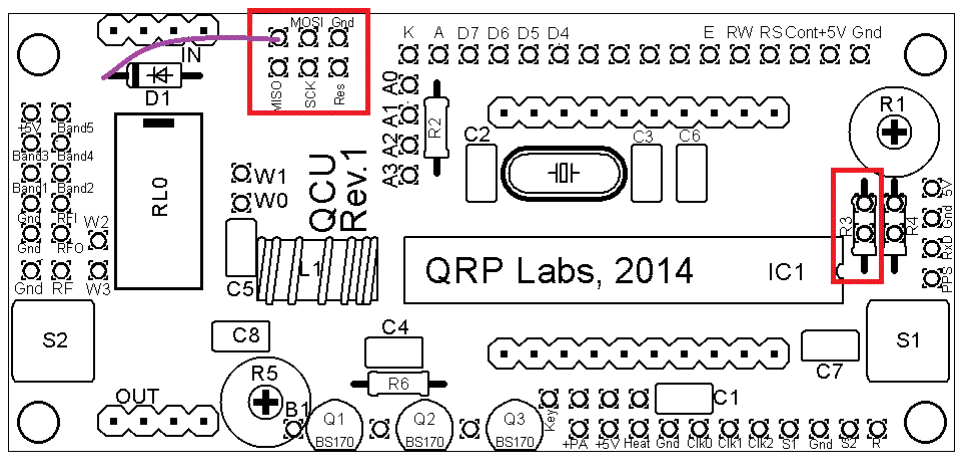
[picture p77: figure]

### 5.9 Higher sensitivity contrast potentiometer adjustment

The contrast voltage required by the LCD is typically under one volt, but the potentiometer R1 is connected between +5V and Gnd. Therefore most of the available travel of the potentiometer adjustment is redundant, and the contrast adjustment is rather sensitive. If you wish to improve this, you may fit a resistor at R4 instead of the wire jumper. A suitable resistor value is 220K or 270K, for example.

## 6. Calibration

It is very important to realise that by far the hardest part of any successful QRSS beacon operation, is tuning the oscillator to the correct frequency. For example, most 30m QRSS stations monitor a narrow 100Hz-wide band from 10,140,000 to 10,140,100. The WSPR sub-bands are 200Hz wide. If you are much outside this, the chances are that nobody will see your signal. It is therefore essential either to adjust your output frequency using an accurately calibrated frequency counter, or an accurately calibrated receiver.

If you are going to use a GPS receiver module to provide a 1pps signal to the kit, no calibration is required: the kit will self-calibrate from the 1pps signal.

In the case that you will not be using a GPS signal, you need to calibrate the kit by entering the correct value of the 27MHz reference oscillator frequency into the “Ref. Frq.” configuration setting.

It is possible that you have an accurate means to measure the 27MHz reference oscillator frequency itself by probing the correct point on the Si5351A module. However most kit builders will not have the necessary equipment, and such a measurement is not easy to make without itself risking disturbing the frequency.

The easiest method is to set the output frequency to something convenient such as 13.500000 MHz, and measure it. Measurement can either be by using an accurately calibrated frequency counter, or by setting up an accurately calibrated receiver with Argo and monitoring the output signal frequency that way.

Once you have measured the actual output frequency, you can calculate the required correction to the 27MHz reference frequency and enter it in the “Ref. Frq.” configuration setting. For example, suppose you set the output frequency to 13.500000 MHz but you actually measure 13.500075. Your output frequency is 75 Hz too high. Since your output frequency setting is 2 times less than the 27MHz reference oscillator frequency, this means that the actual reference oscillator value is 150Hz too high. So enter 27,000,150 in the “Ref. Frq.” setting.

## 7. PA bias set-up

If you are using the OCXO/Si5351A Synth you will find that the R5 trimmer potentiometer is only just accessible under the OCXO when plugged in. This is a great improvement over earlier PCB revisions in which the trimmer potentiometer was completely covered by the OCXO! There is only so far it could be moved, before falling off the board edge. An alternative method of setting up described below, can be used – and does not require the OCXO to be present.

Initially the bias trimmer potentiometer R5 should be set all the way anti-clockwise. With the Si5351A module plugged in, and when you have set up the software to configure your U3S for some transmission, connect a 50-ohm dummy load (two 100-ohm resistors in parallel is fine, or a 47-ohm resistor is fine too). Monitor the power output. As you turn R5 gradually clockwise, the power output will increase. At some point beyond half way, the power output will peak, and as you continue to turn clockwise, power will decrease. This is too far! Now your BS170 will start getting hot. Maybe very hot. So back-off a little. My recommendation is to set the power output a little below the peak setting. A little ANTI-clockwise, from the peak power output setting.

An alternative adjustment procedure also works very nicely. I recommend this method, if you have access to a means to measure the current consumption of the kit with reasonable accuracy. You should measure the overall current consumption of the U3S kit in “idle” mode (key up, not transmitting). You do not even need to plug in the Si5351A module for this. It is a useful method for those using the OCXO, who find accessing R5 to be difficult. Monitor the current consumption of the U3S in “idle” mode and adjust R5 until you just about see a slight increase. This will be a fairly reasonable bias point for good operation of the PA, when you plug in the Si5351A module.

## 8. Resources

Please see the kit pages at http://www.qrp-labs.com for any information on latest updates and issues.

For troubleshooting please refer to http://www.qrp-labs.com/ultimate3/u3trouble for troubleshooting.

Further references are listed in the Operation manual.

## 9. Version History

0 18-Jan-2016

- First version, based initially on Ultimate3S kit assembly manual for U3S Rev2 PCB

1 04-Apr-2016

- Correction to diode connection mentioned on page 16, should be cathode (was anode)
- Clarification of the “anticlockwise” bias potentiometer photograph

2 06-Oct-2016

- Correction to circuit diagram, R4 shown as 100K should be 220K; also on page 7 R4 was referred to as 200K, should be 220K.

3 25-Oct-2016

- Simplified and clarified the assembly manual

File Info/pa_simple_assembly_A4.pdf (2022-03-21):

Rev 1.03 | 1

PA

## 5W HF PA kit SIMPLIFIED assembly instructions

## 1. Introduction

This is a Power Amplifier kit (PA) for CW or FSK modes. The output power is approximately 5W in the middle of the HF frequency range, using a 13.8V supply. A single inexpensive IRF510
MOSFET is the amplification device. An unusual feature of this PA is the built-in facility for envelope shaping, which can create a precise raised-cosine keying envelope shape. This greatly reduces key-clicks when using on/off keyed modes such as CW or at the commencement/completion of an FSK mode transmission.

I highly recommend building the full kit as described in the assembly instructions. The kit has a discrete component power modulator (voltage regulator) which is controlled by an 8-bit R-2R Digital Analogue Converter, and allows an external microcontroller to control the amplitude of the output by loading the on-board 8-bit shift register using three I/O signals, and thereby create the raised cosine shape.

These instructions are for a simplified assembly of the PA kit, which omits raised cosine envelope shaping, or the power modulator with fold-back current limiting. It is easier to build this way, but the functionality is less.

The kit has a PCB of size 80 x 37mm, which is the same size as the other QRP Labs modules such as the Ultimate3S QRSS/WSPR transmitter kit, the VFO kit and the Relay-switched LPF kit. It is therefore physically (as well as electrically) compatible with the other QRP Labs kits and can be bolted behind them in the familiar PCB sandwich. Alternatively this PA can be used with your own homebrew projects. The PCB has space for SMA connectors (not supplied by default with the kit), if you wish to use SMA cables.

The PA kit must always be followed by a low pass filter to attenuate unwanted transmitter harmonics, as usual for RF power amplifiers.

Carry out an inventory of the components according to the parts list to make sure all the components required are present. Remember that there will be many surplus components that are required only for the full build and will not be used here. Read the assembly instructions first before starting the assembly, understand everything, and then finally start the assembly, following all the steps carefully!

The following diagram shows the simplified circuit diagram of this HF PA.

This diagram includes a 10-ohm resistor modification which is highly recommended, and will be described later in this document.

## 2. Parts list

Unused parts are coloured grey – these are used only in the full build.

Resistors

R27 | 0.33-ohm, 2 watt resistor
(none) | 10-ohm resistor
R2, 19 | 15K resistor (2 pieces)
R4..10, 28 | 1.1K resistor (8 pieces)
R3, 11..18, 24 | 2.2K resistor (10 pieces)
R20, 22 | 3.3K resistor (1 pieces used, 1 piece not used)
R21, 30 | 330-ohm resistor (2 pieces)
R23 | 8.2K resistor
R29 | 47K resistor
R1 | 4.7K trimmer potentiometer resistor
R26 | 3.3K resistor (not supplied)
R25 | 4.7K trimmer potentiometer resistor (not supplied)

Capacitors

C1, 2, 3, 7, 8 | 1uF capacitor (5 pieces)
C5, 6 | 1uF capacitor (2 pieces)
C4 | 1nF capacitor

Semiconductors

IC1 | 74HC595 8-bit shift register, 16-pin DIP package
IC2 | 7805L 5V regulator, TO92 package
Q3, 4 | 2N3904 NPN transistor, TO92 package
Q1, 2, 6, 8 | 2N3906 PNP transistor, TO92 package
Q5 | 2SC4242 NPN power transistor, TO220 package
Q7 | IRF510 N-channel power MOSFET, TO220 package
Q9 | BS170 N-channel MOSFET, TO92 package

Miscellaneous

16-pin socket | 16-pin DIP socket for IC1
10-pin header | 10-pin 0.1-inch header
Heatsink | 65mm long PCB-mounting heatsink and pins
Insulation sets | 2 pieces silicone rubber insulation pads + washers for the TO220 transistors
Nut and bolt | 12mm long M3-size bolt and matching nut
FT50-43 | FT50-43 toroid
Wire | 100cm 0.33mm diameter wire
PCB | 80 x 37mm Printed Circuit Board (PCB)

## Theoretical circuit explanation

The chosen amplification device is the IRF510 MOSFET. It is inexpensive, robust, easily able to handle the power requirements, and in a convenient TO220 package. On the other hand, the IRF510 does have high gate capacitance. It is originally intended as a switch for switched-mode power supplies and other such industrial switching requirements. Using it as an RF amplifier wasn’t the manufacturer’s original intention! But it works well on HF, nevertheless! The power output does drop off at the higher frequencies.

For this reason the PCB has been designed to also accept the RD15HVF1 transistor (and similar devices) which are intended and designed for RF applications. They perform very well right up into VHF, 2m band etc. So if you wish to use this PA kit for 6m and 2m you may want to replace the supplied IRF510 with
a RD15HVF1 or one of its siblings. The pinout
of the RD15HVF1 is different to that of the

IRF510. The PCB has a second set of pads to suit the RD15HVF1.

The incoming RF is coupled to the IRF510 gate via a 1uF capacitor. The largish 1uF value is intended to help the PA work well on LF and MF. A DC bias voltage must be applied to the IRF510 gate, this is supplied by 4.7K preset potentiometer R1 via the 3.3K resistor R20.

A trifilar output transformer wound on an FT50-43 toroid provides matching to the 50-ohm output. There are pads/holes on the PCB for an optional SMA connector. This is not supplied in the kit but is available in the QRP Labs shop. You can also fit an SMA connector at the PA kit’s RF input instead of the 2-pin header. The RF output is also available at the 2-pin header JP5, and at a 2 x 5-pin header JP1 (not supplied). The 2 x 5-pin header matches the headers on the Ultimate3S QRSS/WSPR Transmitter PCB and the 6-band relay-switched filter kit PCB. This option may be used when using this PA kit with Ultimate3S, and is described in the application note AN004.

The PA kit also contains a TO92-package 5V regulator IC type 78L05, IC2 (also equivalently called 7805L by some manufacturers). Note that this is shown on the main circuit diagram but in not the sub-block above. This 5V is used for the PA bias. Providing the regulator on board simplifies the use of this PA kit module because you only need to provide a single PA supply e.g. 13.8V. However do not be tempted to power other circuits from this 5V regulator output, such as the Ultimate3S kit or other. The 78L05 is only a low power voltage regulator and has no heatsink. The 78L05 is rated for 100mA maximum supply current.

## 3. Assembly

Assembly of this kit is quite straightforward. The usual kit-building recommendations apply: work in a well-lit area, with peace and quiet to concentrate. Some of the semiconductors in the kit are sensitive to static discharge. Therefore observe Electrostatic discharge (ESD) precautions. And FOLLOW THE INSTRUCTIONS!!

A jeweller’s loupe is really useful for inspecting small components and soldered joints. You’ll need a fine-tipped soldering iron too. It is good to get into the habit of inspecting every joint with the magnifying glass or jeweller’s loupe (like this one I use),
right after soldering. This way you can easily identify any
dry joints or solder bridges, before they become a
problem later on when you are trying to test the project.

It is always best to detect and correct any mistakes as early as possible (immediately after soldering the incorrect component). The board is quite compact, to fit the required 80 x 37mm PCB dimensions. Removing a component and re-installing it later is often very difficult!

The resistors in the kit are installed vertically, because
PCB space is limited. It was important to design it to fit

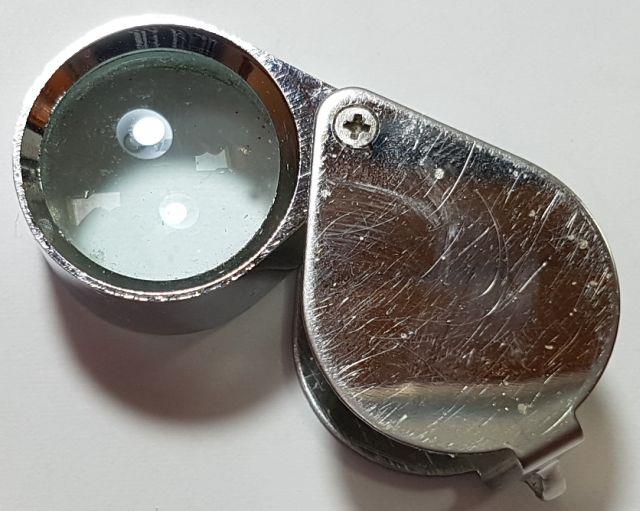
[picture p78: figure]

on an 80 x 37mm PCB for potential use with other QRP Labs kits such as the Ultimate3S QRSS/WSPR transmitter. You will need to bend the resistor wires as shown in the picture below. On the parts layout diagram there is a small circle around the hole where the body end of the resistor should be installed. This is
not critical (resistors don’t care
which way around they are) but it is
recommended, just to try to ensure that the folded over wire-end of the
resistor doesn’t touch any other
wire or metal part.

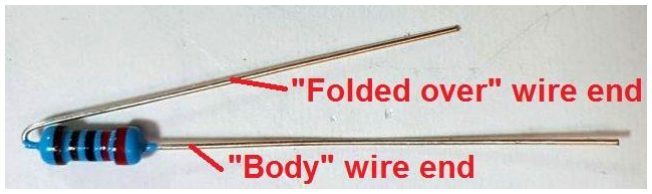
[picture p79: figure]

Please refer to the layout diagram and PCB tracks diagrams below, and follow the steps carefully.

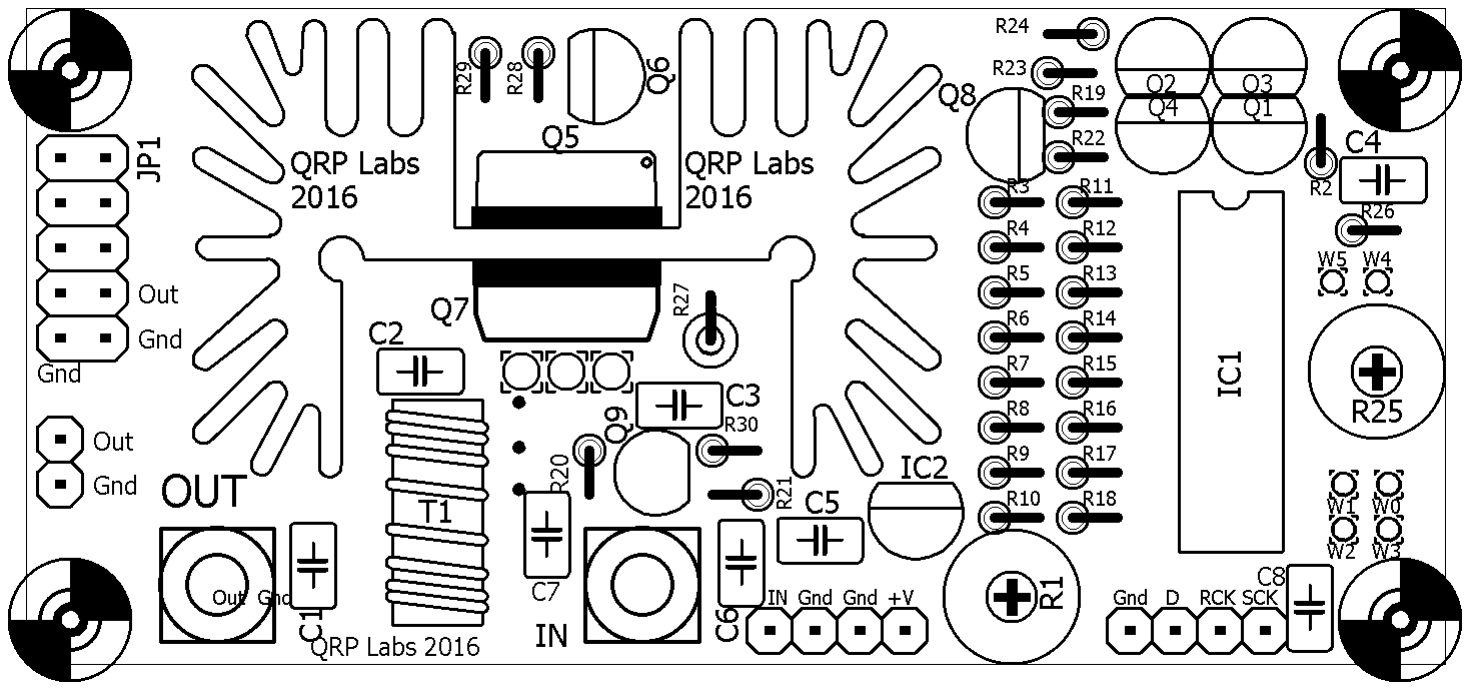
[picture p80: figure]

PCB track diagram. Tracks shown in BLUE are on the bottom layer. Tracks shown in RED are on the top layer. There are only two layers (nothing is hidden in the middle). Not shown in this diagram are the extensive ground-planes. Everything on the bottom layer that isn’t a RED track, is ground-plane! Large areas of the top side are also ground-plane, connected to the bottom ground-plane layer at frequent intervals by vias.

Note that the heatsink is not electrically connected to ground or anything else. The area right under the heatsink has no ground-plane on the top layer. This is to prevent the heatsink potentially scratching the soldermask and connecting to a ground-plane if there was one. For the same reason there are no tracks on the top layer under the heatsink. The metal tabs of the TO220 transistor is NOT connected to ground, and is insulated from the heatsink, so long as all the insulating hardware is properly installed. The heatsink itself is therefore connected to nothing at all.

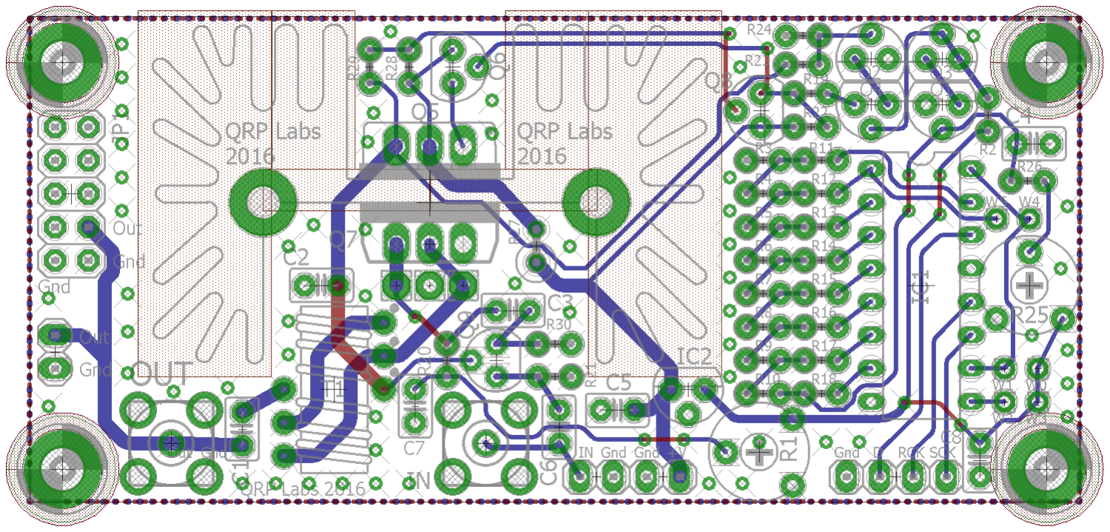
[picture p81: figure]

## 3.1 Inventory parts

This is the full list of parts. Many are not used in this simplified build. Please refer to the parts list.

## 3.2 Install required components

Install and solder the components indicated in this diagram and described as follows.

YELLOW: Capacitors C1, C2, C3, C7 and C8 are 1uF capacitors. The writing on the capacitor is “105”. Be careful – the kit also contains one 1nF capacitor labelled “102” – do not mix them up!

RED: Resistor R20, 3.3K, with colour code with colour code orange-orange-black-brown-brown.

BLUE: 78L05 voltage regulator IC2. Be careful to install this with the same orientation as the white silkscreen printing on the PCB. Also check the label on the component – there are many TO92-style transistors which look similar – do not mix them up!

GREEN: The 4.7K preset bias adjustment potentiometer, with label “472”.

PURPLE: Optionally you can install header pins. Many people prefer to solder wires to header pins, rather than in holes. Or you may wish to use header socket connectors. In this case snap off a 2-pin section and a 4-pin section from the supplied 10-pin header, and install them as shown.

## 3.3 Install jumper wires

The jumper wires are necessary to bypass the power modulator circuit, and to bypass the leakage gate circuit. These parts of the full PA kit assembly are not undertaken in this simplified build.

Four jumpers need to be installed as per the following diagram. This diagram shows the PCB holes/pads in green to make it clear where the jumper wires need to be installed. These jumpers can be made using wire offcuts from the installed components or surplus components.

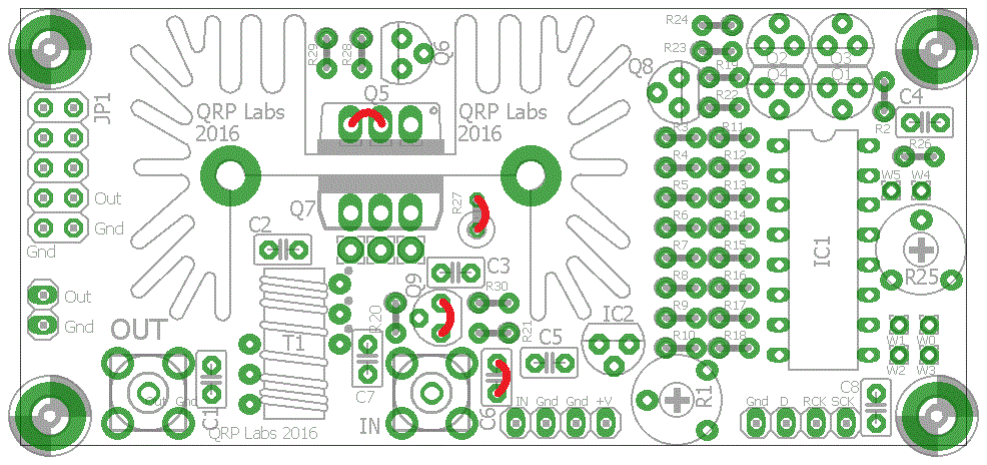
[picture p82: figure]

## 3.4 Install trifilar transformer

The trifilar transformer is installed in the position coloured red in this diagram. The photo (right) shows the board after installing the trifilar transformer. But it is a tricky part of the assembly, so please read and follow these steps carefully.

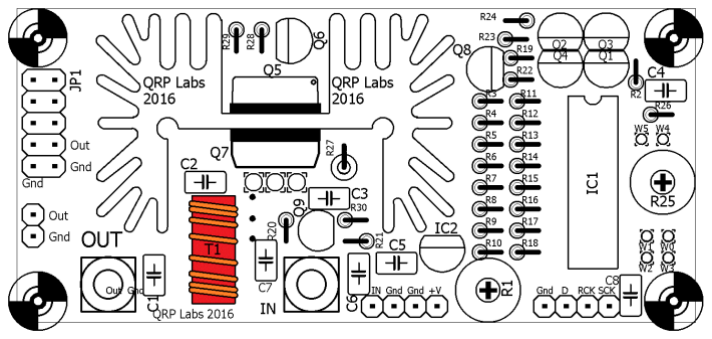
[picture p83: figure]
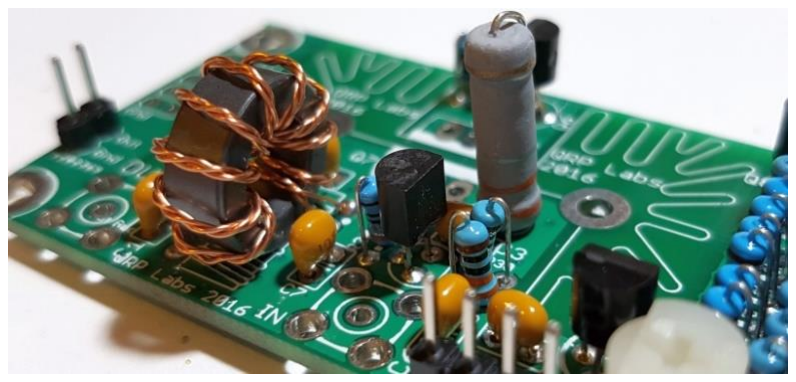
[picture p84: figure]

Firstly, the wire. The best way to un-wind it, without tangling it up, is to think of what the kit-packing person that wound it up did. Then reverse his steps. So, first unwind the tightly wrapped part in the middle where the end of the wire has been secured. Then, open out the spool of wire so that it is a circle. Then unwind the spool, around your fingers, reversing the process of winding it in the first place.

When you have unwound the wire and straightened it, cut it into three approximately equal pieces. These three pieces now need to be tightly twisted together to make the trifilar wire. My method for this is to tie one end in a knot around a small screwdriver shaft. Similarly tie the other end around another small screwdriver. Now clamp one end somehow to something solid. You could use a vice, if you have one. If you don’t, then you have to get creative and think of something. Here I taped it to the edge of the desk. Now you can twist the screwdriver at the free end, repeatedly until you twist the three wires together thoroughly. You need to keep the wire under a little tension to keep the twists evenly spaced.

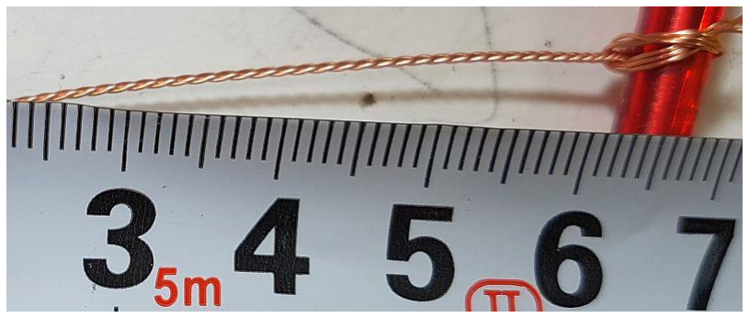
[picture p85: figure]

I put about 70-90 twists into a 25cm length of wire. The end result is something like the photo (right). The measurement scale is in cm.

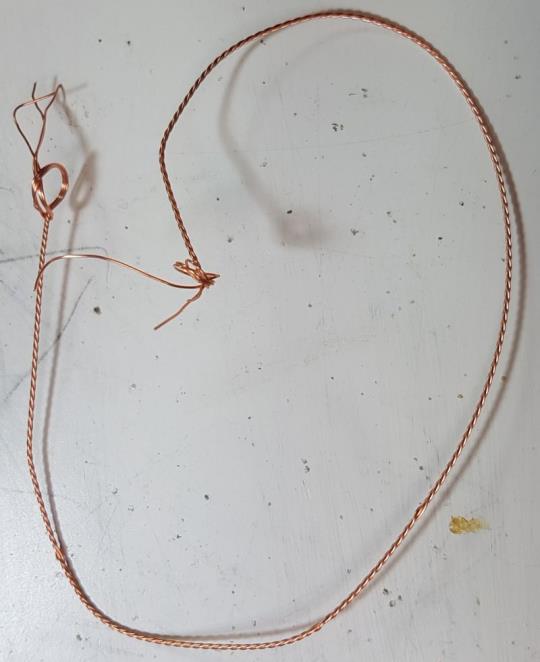
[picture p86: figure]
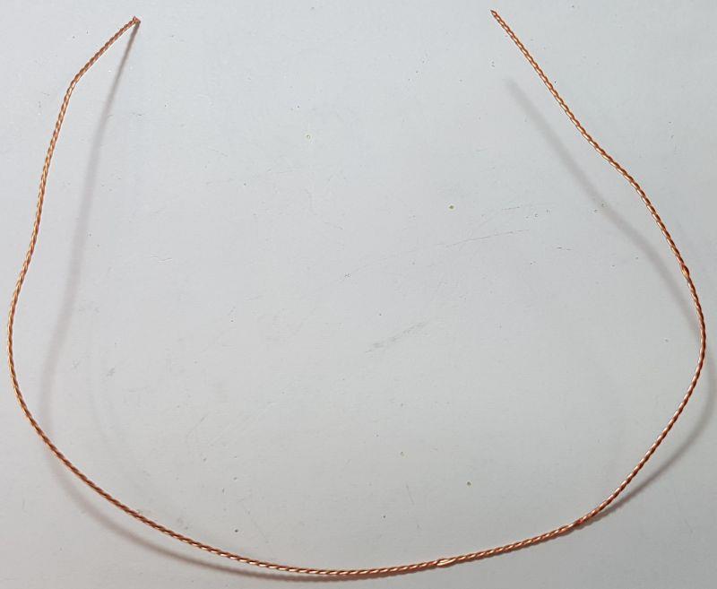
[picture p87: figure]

Now cut off the untidy ends, and this is the piece of wire that will be used to wind the FT50-43 toroidal core as a trifilar transformer.

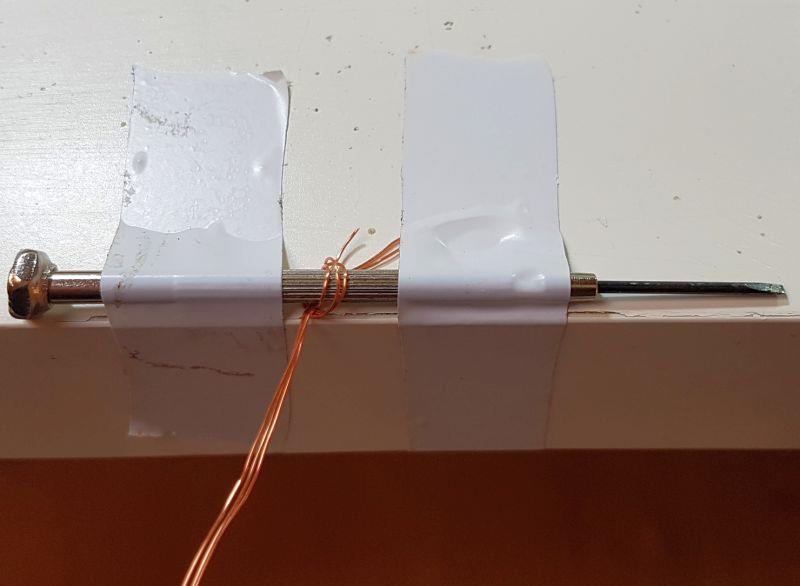
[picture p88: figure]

Hold the core between thumb and finger. Pass the wire first from above, to below. Then take the wire from below, and bring it around to pass through the toroid again to form the second turn. After each turn, ensure the wire is fitting snugly around the toroidal core. Wind 10 turns on the core. Each time through the toroid’s central hole counts as one turn. Cut off the excess wire, leaving about 2.5cm remaining.

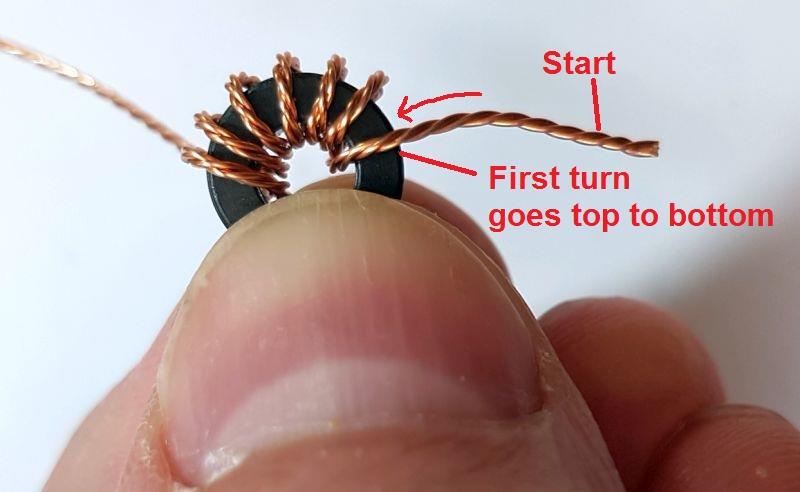
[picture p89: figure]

Now it’s necessary to identify which wire belongs to which winding. You have three windings twisted together, they all use the same wire. The only way to do this is with a DVM as continuity tester. First, untwist and straighten the wire ends that are not wound around the toroidal core.

Now tin the last few mm at the ends of each wire. You can do this by scraping off the enamel then tinning with the soldering iron; or, hold the wire end in a blob of molten solder for a few (maybe 10) seconds, until the enamel burns off.

Now use a DVM to test for
continuity. Re-arrange the wires
so that there is continuity from A-A, B-B, and C-C in this photo.

Carefully keep this orientation of wires and insert the transformer this way into the PCB. You can carefully cut off those few mm of tinned section of wire, if it won’t fit through the PCB holes. But BE CAREFUL not to lose the
orientation of the wires! The
right wires must be in the right

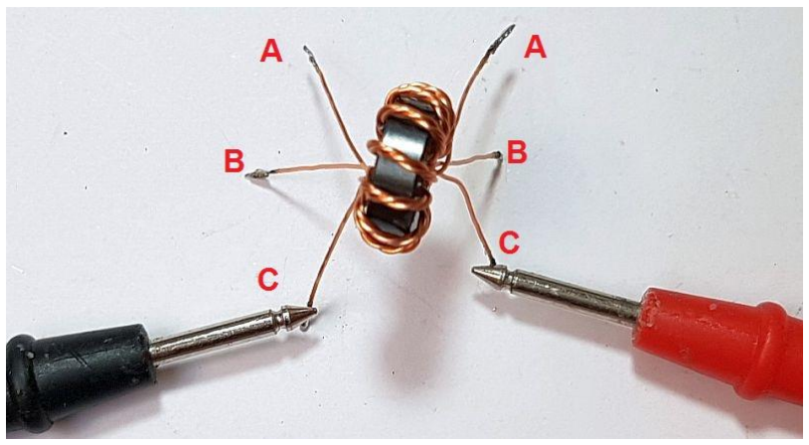
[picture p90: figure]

holes, so that the windings are connected correctly in the circuit!

It’s a good idea to check for continuity A-A, B-B, C-C again with the DVM, just to make sure that you didn’t accidentally mix up the wire orientation while inserting the wires.

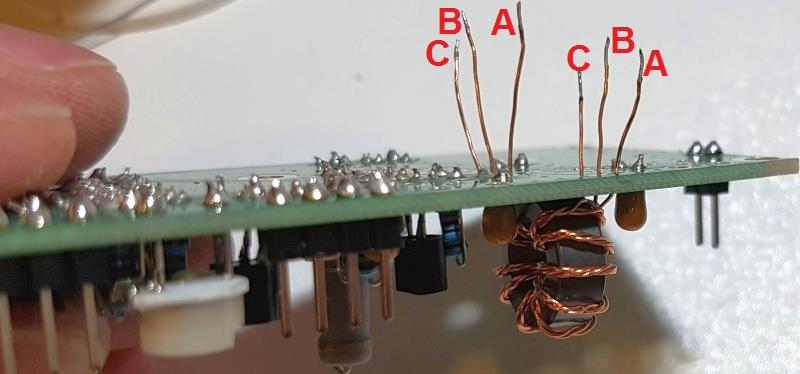
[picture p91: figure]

Now trim the wires underneath the board, and tin the ends again. The EASIEST way to do this is simply apply solder so that it sits in the hole and surrounds the 1mm of wire ending, and hold the soldering iron in that position for a few seconds until the enamel is burnt away. This tins the wires and solders them to the PCB pads.

You can inspect the joints with a magnifying
glass or jeweller’s loupe. The photograph (right)
shows a joint where the soldering iron has not

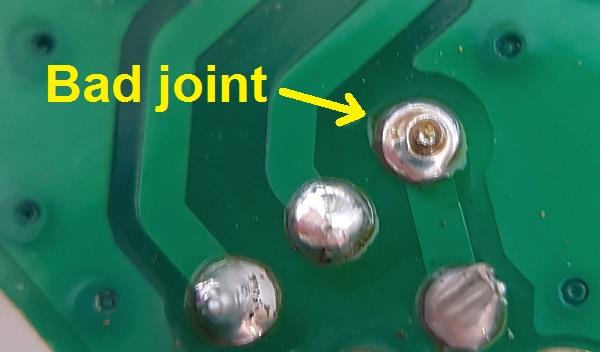
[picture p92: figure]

been held long enough on the joint. The enamel has not properly burnt off the wire, and there will be no electrical connection to the copper wire. The circuit will not work! So fix it!

You can also test that the wires are properly soldered. Use a DVM to check for continuity (zero ohms resistance) between the indicated points C and A in this diagram and photo. If there is continuity it means that the copper wire is all properly soldered. If not, then go back and check again. You can then check the individual windings to see where the fault lies.

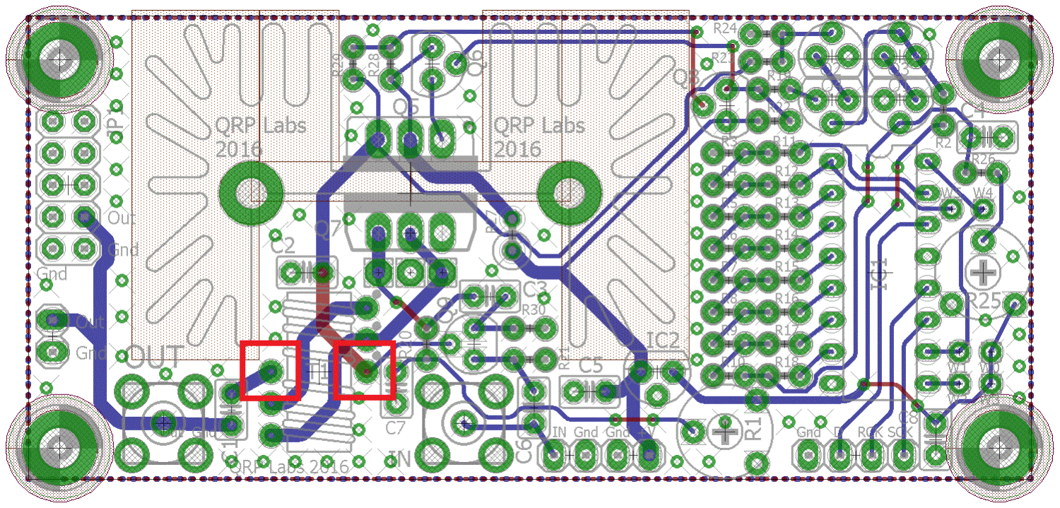
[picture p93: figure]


Note that this does NOT necessarily check that you correctly orientated the windings. The only way to do that, was with the DVM continuity check before inserting the transformer; and after identifying the windings, being careful not to mix the wires again while inserting the transformer in the PCB; finally checking again once the wires are inserted but before soldering.

## 3.5 Install heatsink assembly

In this kit the IRF510 transistor final (Q7) is fitted to the metal heatsink. The metal tab of this transistor must not short to ground or to other parts of the circuit. Therefore insulating silicone rubber pads are used, and insulating white plastic washers. In this photo (right) the heatsink is viewed side-on before assembly. The picture shows how the transistor assembly must be put together before soldering.

On the side of the heatsink with the large gap, the silicone pad is placed on the heatsink where the
IRF510 transistor will sit. The transistor is placed
on the silicone pad. The white nylon insulating


washer is pushed into the hole in the transistor tab. The bolt then fits through the hole. The metal bolt does not touch the metal tab of the transistor, and the tab does not touch the heatsink.


In the prototypes I put the bolt on the far side and the nut on the IRF510 side, as shown. Then it is easiest to grab the bolt with pliers while tightening the screw from the other side.

If you have some heatsink compound then this would be a good idea (though the prototypes development and testing did not use it). Take care to align the transistor accurately and tighten the bolt/nut well. You will be rewarded by an assembly which fits easily into the holes on the PCB.

It is difficult to remove and replace transistors later! So before soldering, check once again that the Q7 transistor (IRF510) is in the correct place on the side of the wide opening of the heatsink. Check that everything matches the PCB silkscreen and this diagram (right).

Once the heatsink assembly and transistors are
fitting perfectly into the PCB, you can solder first


the heatsink mounting pins, then the transistor component leads themselves. A high wattage soldering iron may be needed for soldering the heatsink pins, as the heatsink will try to conduct away heat which may lower the temperature of the joint below the melting point of solder. You could leave the heatsink pins unsoldered if it seems troublesome. After soldering the transistor leads, cut off the excess lead length.

Note that the pads for the heatsink mounting pins are not connected to ground (or anything else). The PCB top side has no copper or tracks of any sort under the heatsink; this is to ensure that even if the soldermask accidentally got scratched, there would be no contact between the heatsink and ground or any other electrical connection.

## 3.6 A recommended modification

This modification will be included as
standard on any future PCB revisions. It
involves the addition of a 10-ohm resistor
at the gate of Q7, the IRF510 final PA transistor. The PA does work without this resistor, and indeed it will produce slightly higher power output. However at certain supply voltages and frequencies, instability can occur. When this happens the amplifier superimposes a low frequency oscillation envelope on the wanted RF output. Fitting this 10-ohm resistor resolves this potential problem, at the cost of some power reduction. The measurements made later in this document were made with this 10-ohm resistor fitted.

The modification involves cutting one track
on the BOTTOM side of the PCB, and

soldering a 10-ohm resistor on the bottom side of the PCB. The resistor location is shown in the above circuit diagram fragment which shows the IRF510 PA. The 10-ohm resistor is supplied in the kit and has colour code brown-black-black-silver-brown.


The modification is illustrated in the following diagram and picture.

## 3.7 RD15HVF1 Substitution for VHF operation

The supplied IRF510 transistor works well at HF. However for the VHF bands 6m and above, the gain of the IRF510 in this circuit is very low. If you wish you may substitute the RD15HVF1 transistor or one of its close relatives. These transistors are more expensive but are designed for VHF/UHF power amplifiers and should work well in this circuit.

The pinout of the RD15HVF1 is different to the IRF510! The PCB has a position for the RD15HVF1 transistor if you
wish to use it. If you wish to use
the RD15HVF1 in this circuit,
insert its leads into the set of three holes shown in RED in the diagram. You will need to bend the leads of the transistor outwards slightly, away from the heatsink, so that they are aligned with this set of holes. Take care to insert the transistor leads into the correct holes.


## 4. Connecting and configuring the Power Amplifier kit

## 4.1 Basic connections

The power amplifier kit requires a supply voltage of typically 12 or 13.8V. The amplifier may draw 1 or 1.5A of current so remember to use a well-regulated good quality power supply capable of this. Use thick wires to the PA to avoid voltage drop in the wiring. You may wish to connect an electrolytic capacitor close to the PA kit PCB, particularly if the wires to your supply are long.

The RF input to the amplifier may be connected at the pin header, or you may install an SMA connector for it. If using the pin header, it is a good idea to use a ground connection wire as well as the RF signal connection wire. Thin coax is suitable.

The RF output may be taken from a pin header, or an SMA connector, or the 2 x 5-pin header pads provided. The footprint for the 2 x 5-pin header is provided to facilitate connection to the Ultimate3S kit – if you are using this then please refer to App Note AN004. As usual, remember to connect a low pass filter at the PA output, to attenuate transmitter harmonics.

The 4-pin header with the microcontroller signals that control the 8-bit shift register, DAC and power modulator are NOT used in this simplified construction. They may be left unconnected.

## 4.2 Bias adjustment

Correct bias adjustment is very important! Before connecting power, turn the R1 bias potentiometer completely anti-clockwise (zero volts bias)!

R1 adjusts the bias at the gate of the IRF510 final PA transistor Q7. If the bias is too low, the gain (and power output) of the amplifier will be low. If the bias is too high, the current through Q7 will flow even when there is no signal; this can result in excess power dissipation (though the power modulator circuit removes power to the IRF510
PA final in any case). Efficiency is also reduced and
gain/power output may be reduced also if bias is too high.


Theoretically the ideal bias point for the gate of the MOSFET, is where there is zero idle current through the IRF510 transistor, and where increasing the bias voltage any further would result in idle current starting to flow. This point has optimal power output, if the input signal amplitude is optimum, and it has best efficiency as well as spectral purity of the output. Of course in the real world, everything can (and does) change!

The zero idle current point can be found quite easily if you connect an ammeter (typically a DVM in current measurement mode) in series with the PA kit supply. The adjustment is carried out in the key-up state, or in other words, no RF input (you could disconnect the RF input, for example).

Start with R1 completely anti-clockwise. Observe the current consumption of the PA kit when “idle” (key-up state, not transmitting, no RF input). Then slowly turn the R1 trimmer potentiometer clockwise until you observe a very slight increase in the current consumption. The point where the current just starts to increase is the zero bias point.

An alternative (and arguably simpler) method of bias adjustment is to transmit into a 50-ohm dummy load, measuring power with a power meter or observing on an oscilloscope. Turn the R1 trimmer potentiometer clockwise until maximum power output is obtained, then back off slightly. The bias setting using this method is higher than the zero idle current method. The power output will be higher too.

The gain of the IRF510 amplifier is less at the upper end of the HF bands particularly 28MHz (the 10m band). The input signal is also typically lower, when using for example an Ultimate3S kit as the driver. In these cases, adjusting the PA with a higher bias voltage can improve the gain/power output at the high frequency end of its range of operation.

If using this PA in a multi-band transmitter and desiring maximum power output, you could adjust the bias for best power output on the highest frequency that will be used (for example, 28MHz) where the bias is most critical. The bias setting is much less critical at the lower end of HF.

## 4.3 Heatsink temperature rise; PA kit installation in enclosure

The desired output power of this PA kit in your application has a significant bearing on how you enclose the project. Remember that the heatsink will dissipate a considerable amount of heat. The heat dissipation will cause the temperature of the heatsink to rise. You need to take this into account when deciding what enclosure to use. You may wish to bolt the heatsink to the back of a metal box, for example; or consider a fan to cool the heatsink.

In operation the power modulator transistor will dissipate some heat as it is an imperfect switch; the IRF510 final PA will operate at perhaps 50% efficiency or something like that (dependent on many factors). For a power output of 5W you will therefore be dissipating at least 5W, maybe somewhat more.

Another factor to take into account is the transmission mode you will be using. A continuous key-down transmission using FSK modes such as WSPR, will dissipate a much higher average power than an on/off keyed mode such as CW.


As an example, one prototype here was
operated on continuous key-down on
10MHz, with 13.8V supply using an Ultimate3S transmitter as the driver. The power output was set to 5W using the maximum DAC value (meaning excess power was also dissipated in the power modulator). An overall current consumption of 1.06A was recorded. The assembly was lying on the workbench with no enclosure, and no forced air cooling. It took about half an hour for the temperature of the heatsink to stabilise. By that time it had reached a temperature of 61C which was a rise of 33C above the ambient temperature of the lab. The transmission was switched off after 40 minutes (see chart).

In summary: Enclosing the PA kit in an enclosure will increase the temperature rise; using fan-assisted cooling would reduce it. There are many factors that will influence heat dissipation. The above discussion should be taken as a guideline only – your mileage may (WILL) vary!

## 5. Power Amplifier characteristics

Please refer to section 5 of the full PA kit assembly instructions. The measurements there were made with the full assembled kit. This simplified kit assembly does not suffer voltage drop across the power modulator, nor does it have any attenuation in the leakage gate. Due to this, the output power will be slightly higher with this simplified kit assembly.

## 6. References

- App Note AN004 explains how to use this PA kit in conjunction with an Ultimate3S QRSS/WSPR kit to increase the output power to around 5W, and apply raised cosine RF envelope shaping for a beautiful clean click-free signal. Refer to http://qrp-labs.com/appnotes (http://qrp-labs.com/appnotes)
- For updates relating to this kit please visit the QRP Labs PA Kit page http://qrp-labs.com/pa
- For any questions regarding the assembly and operation of this kit please join the QRP Labs group, see http://qrp-labs.com/group for details

## 7. Document Revision History

- 02-Jan-2017 | 1.0 | Initial revision
- 09-Mar-2017 | 1.01 Corrected typos in toroid core type
- 04-May-2017 | 1.02 Corrected section 3.3 to say four jumper wires (not three)
- 29-Nov-2018 | 1.03 Corrected BS170 in parts list, it is TO92 not TO220 package

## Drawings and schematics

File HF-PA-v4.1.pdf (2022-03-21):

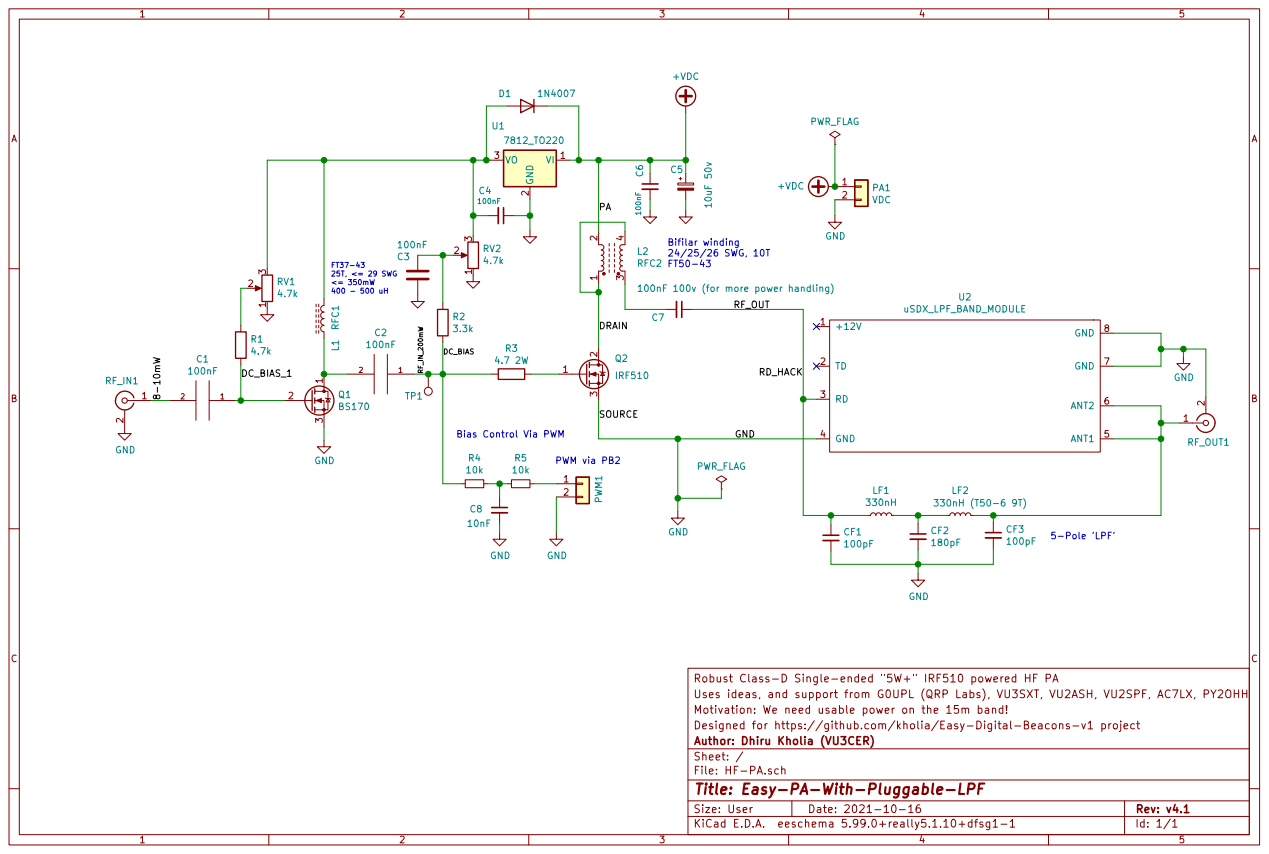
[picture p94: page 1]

5-Pole 'LPF' Bifilar winding
24/25/26 SWG, 10T

Robust Class-D Single-ended "5W+" IRF510 powered HF PA
Uses ideas, and support from G0UPL (QRP Labs), VU3SXT, VU2ASH, VU2SPF, AC7LX, PY2OHH
Motivation: We need usable power on the 15m band!
Designed for https://github.com/kholia/Easy-Digital-Beacons-v1 project
File: HF-PA.sch Sheet: / Author: Dhiru Kholia (VU3CER)

Id: 1/1 Title: Easy-PA-With-Pluggable-LPF

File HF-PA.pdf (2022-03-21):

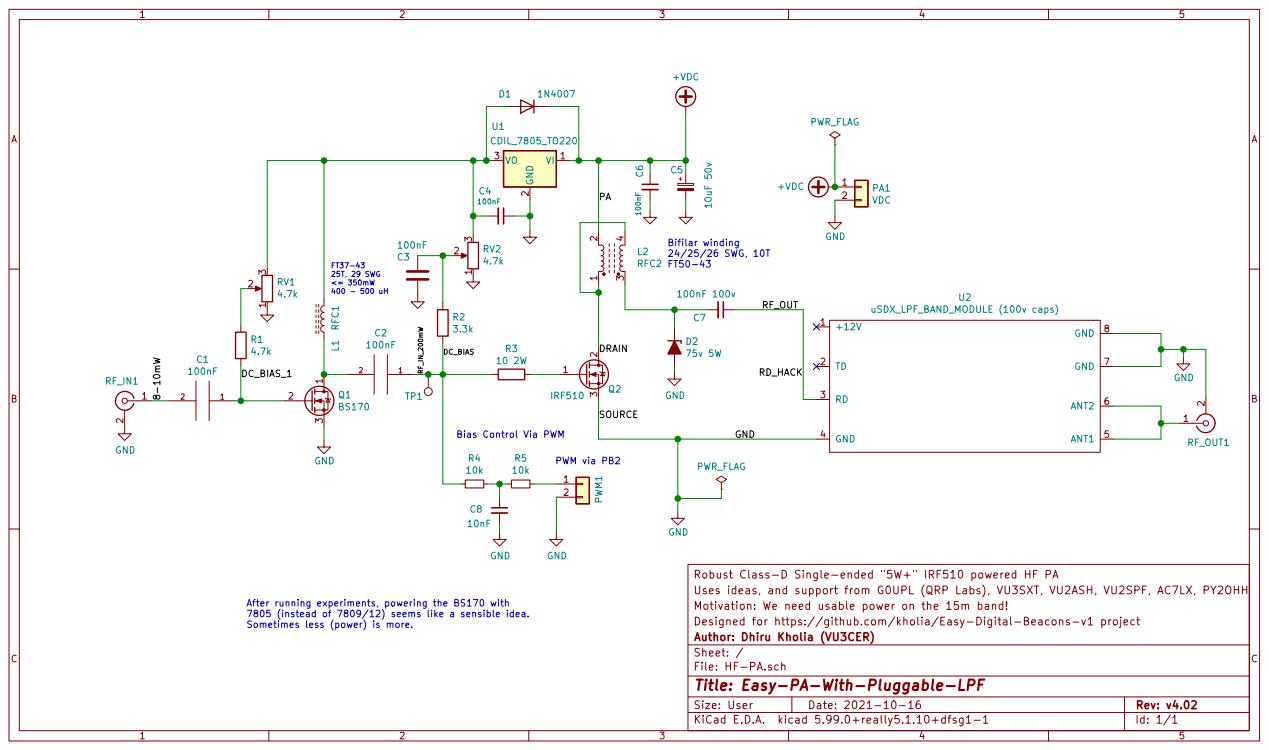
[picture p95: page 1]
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

After running experiments, powering the BS170 with
7805 (instead of 7809/12) seems like a sensible idea.

Id: 1/1 Title: Easy-PA-With-Pluggable-LPF

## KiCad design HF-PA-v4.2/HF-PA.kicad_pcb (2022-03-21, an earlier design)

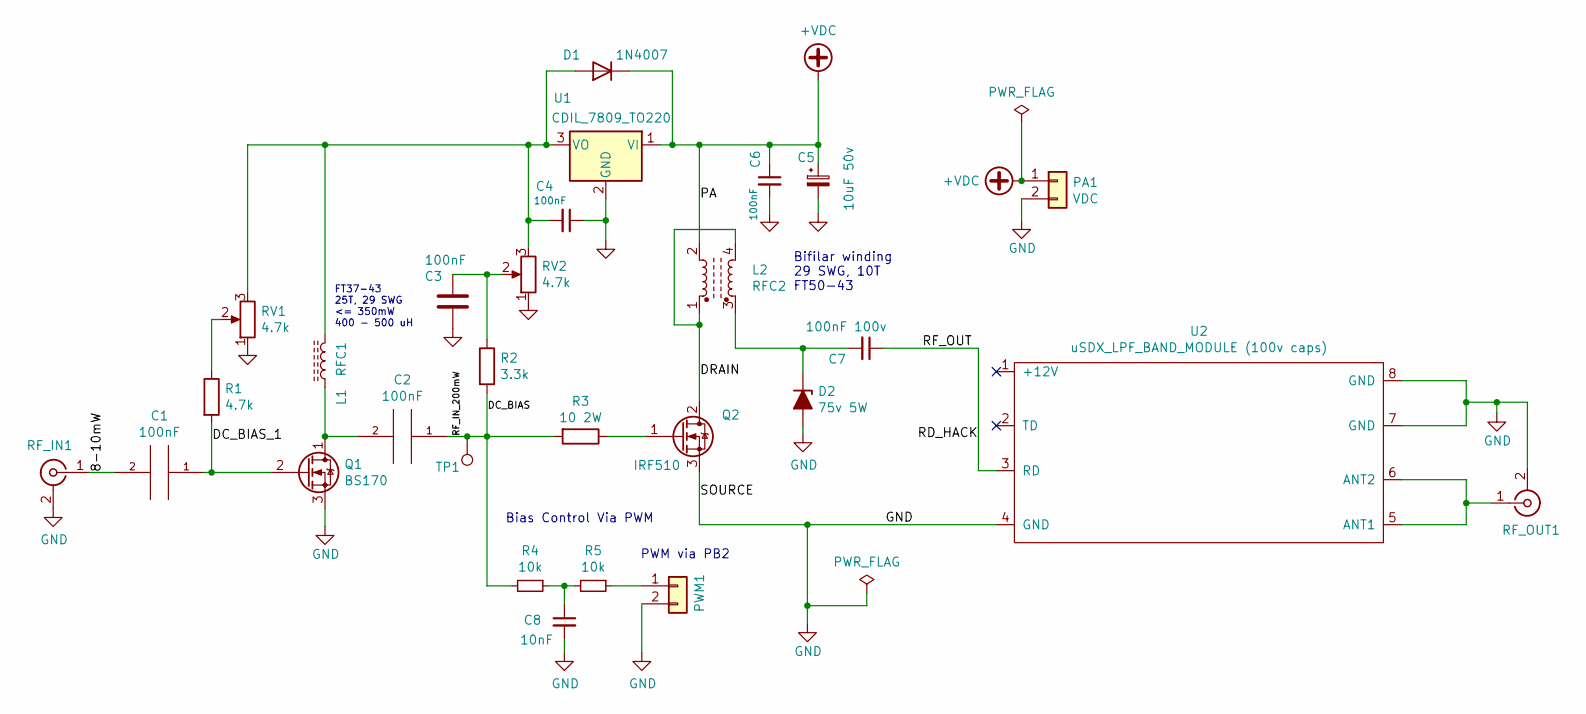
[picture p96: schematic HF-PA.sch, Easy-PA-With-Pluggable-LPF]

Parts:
C1, C2, C3, C4, C6: 100nF; C_Disc_D4.3mm_W1.9mm_P5.00mm
C5: 10uF 50v; CP_Radial_D5.0mm_P2.50mm
C7: 100nF 100v; C_Disc_D4.3mm_W1.9mm_P5.00mm
C8: 10nF; C_Disc_D4.3mm_W1.9mm_P5.00mm
D1: 1N4007; D_DO-41_SOD81_P3.81mm_Vertical_AnodeUp
D2: 75v 5W; D_DO-201_P5.08mm_Vertical_AnodeUp
L1: RFC1; L_Toroid_Vertical_L10.0mm_W5.0mm_P5.08mm
L2: RFC2; FT50-43 Transformer
PA1: VDC; PinHeader_1x02_P2.54mm_Vertical
PWM1: Conn_01x02; PinHeader_1x02_P2.54mm_Vertical
Q1: BS170; PinSocket_1x03_P2.54mm_Vertical
Q2: IRF510; TO-220-3_Vertical
R1: 4.7k; R_Axial_DIN0207_L6.3mm_D2.5mm_P2.54mm_Vertical
R2: 3.3k; R_Axial_DIN0207_L6.3mm_D2.5mm_P2.54mm_Vertical
R3: 10 2W; R_Axial_DIN0207_L6.3mm_D2.5mm_P2.54mm_Vertical
R4, R5: 10k; R_Axial_DIN0207_L6.3mm_D2.5mm_P2.54mm_Vertical
RF_IN1: Conn_Coaxial; SMA_Amphenol_901-144_Vertical
RF_OUT1: Conn_Coaxial; SMA_Amphenol_901-144_Vertical
RV1, RV2: 4.7k; Potentiometer_Runtron_RM-065_Vertical
TP1: TestPoint; PinHeader_1x01_P2.54mm_Vertical
U1: CDIL_7809_TO220; TO-220-3_Vertical
U2: uSDX_LPF_BAND_MODULE (100v caps); uSDX_LPF_Band_Module

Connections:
+VDC: C5.1, C6.1, D1.1 (K), L2.2, PA1.1, U1.1 (VI)
/8-10mW: C1.2, RF_IN1.1 (In)
/DC_BIAS: C2.1, R2.2, R3.2, R4.2, TP1.1
/DC_BIAS_1: C1.1, Q1.2 (G), R1.2
/DRAIN: L2.1, L2.4, Q2.2 (D)
/RD_HACK: C7.1, U2.3 (RD)
GND: C3.2, C4.1, C5.2, C6.2, C8.2, D2.2 (A), PA1.2, PWM1.2, Q1.3 (S), Q2.3 (S), RF_IN1.2 (Ext), RF_OUT1.2 (Ext), RV1.1, RV2.1, U1.2 (GND), U2.4 (GND), U2.7 (GND), U2.8 (GND)
unnamed: C2.2, L1.1, Q1.1 (D)
unnamed: C3.1, R2.1, RV2.2
unnamed: C4.2, D1.2 (A), L1.2, RV1.3, RV2.3, U1.3 (VO)
unnamed: C7.2, D2.1 (K), L2.3
unnamed: C8.1, R4.1, R5.2
unnamed: PWM1.1, R5.1
unnamed: Q2.1 (G), R3.1
unnamed: R1.1, RV1.2
unnamed: RF_OUT1.1 (In), U2.5 (ANT1), U2.6 (ANT2)

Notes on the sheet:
Bias Control Via PWM
PWM via PB2
FT37-43 25T, 29 SWG <= 350mW 400 - 500 uH
Bifilar winding 29 SWG, 10T FT50-43

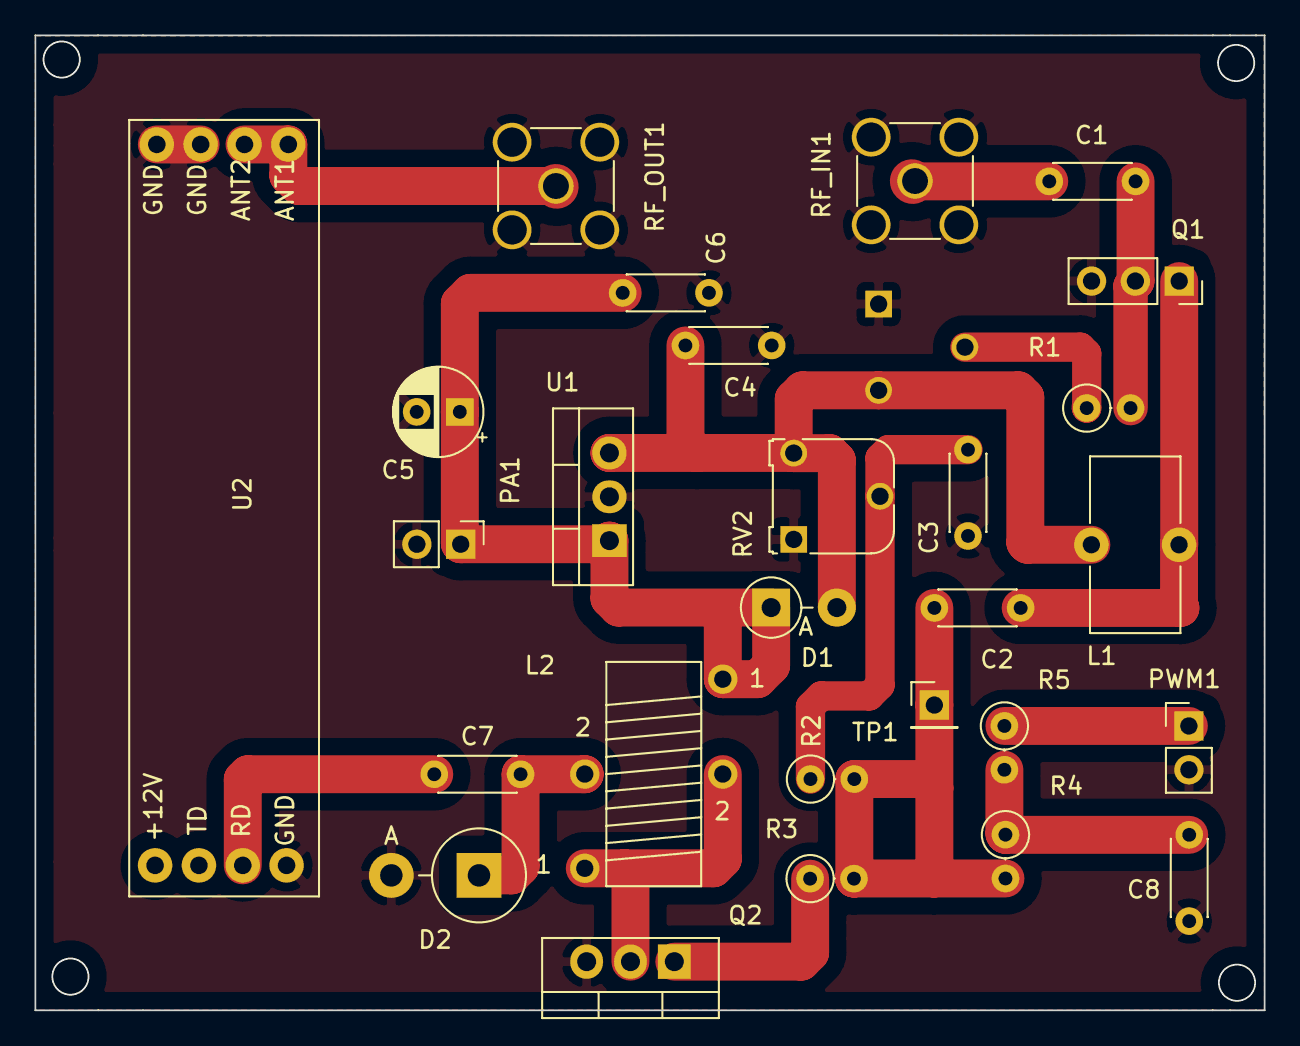
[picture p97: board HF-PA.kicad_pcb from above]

Board: 2 copper layers, 71.2 x 56.5 mm, 28 parts (1 on the bottom side), 16 nets.
